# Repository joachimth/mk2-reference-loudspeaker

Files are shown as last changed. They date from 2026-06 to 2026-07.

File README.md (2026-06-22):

# Mk2 Reference Loudspeaker

A DIY active 3-way reference loudspeaker project, inspired by Genelec 8361, Dutch & Dutch 8C, and Revel Salon2.

## Current Design - v6b

| Parameter | Value |
|---|---|
| Woofers | 2 × GRS 8SW-4HE-8 (push-push, side-mounted) |
| Midrange | ScanSpeak 15W/4434G00 |
| Tweeter | ScanSpeak H2606/920000 in WG212 waveguide |
| Cabinet | 300 × 370 × 1080 mm, 22 mm birch plywood |
| Front edges | R50 vertical roundovers |
| Bass volume | ~69 L sealed |
| Mid chamber | ~5.7 L sealed |
| Bass/mid xover | 150 Hz LR4 |
| Mid/tweeter xover | 1250 Hz LR4 |
| Mid/tweeter c-c | 140 mm |
| Bass alignment | Fc ~34.5 Hz, Qtc ~0.62 |
| System type | Active, DSP-controlled |

## Project Status




Design candidate **v6b** is selected. CAD models and simulations are complete.
Physical prototype not yet started.

**Current gate:** Print WG212 waveguide → measure H2606 distortion at 1250 Hz → confirm crossover frequency → build prototype.

See [`PROJECT_TODO.md`](PROJECT_TODO.md) for the full task list and dependency graph.

## Documentation

The full Design Bible lives in the `docs/` folder:

| Chapter | File |
|---|---|
| Master index | [docs/00_design_bible.md](docs/00_design_bible.md) |
| 1. Project goals | [docs/01_project_goals.md](docs/01_project_goals.md) |
| 2. Theory | [docs/02_theory.md](docs/02_theory.md) |
| 3. Woofer selection | [docs/03_woofer_selection.md](docs/03_woofer_selection.md) |
| 4. Midrange selection | [docs/04_midrange_selection.md](docs/04_midrange_selection.md) |
| 5. Tweeter selection | [docs/05_tweeter_selection.md](docs/05_tweeter_selection.md) |
| 6. Waveguide development | [docs/06_waveguide_development.md](docs/06_waveguide_development.md) |
| 7. Cabinet development | [docs/07_cabinet_development.md](docs/07_cabinet_development.md) |
| 8. Push-push bass | [docs/08_push_push_bass.md](docs/08_push_push_bass.md) |
| 9. Volume calculations | [docs/09_volume_calculations.md](docs/09_volume_calculations.md) |
| 10. Bracing | [docs/10_bracing.md](docs/10_bracing.md) |
| 11. Crossovers | [docs/11_crossovers.md](docs/11_crossovers.md) |
| 12. Directivity | [docs/12_directivity.md](docs/12_directivity.md) |
| 13. Spinorama | [docs/13_spinorama.md](docs/13_spinorama.md) |
| 14. DSP | [docs/14_dsp.md](docs/14_dsp.md) |
| 15. Measurements | [docs/15_measurements.md](docs/15_measurements.md) |
| 16. Build guide | [docs/16_build_guide.md](docs/16_build_guide.md) |
| 17. Future versions | [docs/17_future_versions.md](docs/17_future_versions.md) |

## Reference Files

- [DESIGN_REQUIREMENTS.md](DESIGN_REQUIREMENTS.md) - Acoustic and mechanical targets
- [DESIGN_DECISIONS.md](DESIGN_DECISIONS.md) - Rationale for all key decisions
- [PARTS.md](PARTS.md) - Driver and materials list
- [SIMULATIONS.md](SIMULATIONS.md) - Simulation work and assumptions
- [MEASUREMENTS.md](MEASUREMENTS.md) - Measurement plan
- [BUILD_LOG.md](BUILD_LOG.md) - Physical build log
- [ROADMAP.md](ROADMAP.md) - Version history and future plans
- [CHANGELOG.md](CHANGELOG.md) - Design change log
- [REFERENCES.md](REFERENCES.md) - Books, papers, tools
- [TODO.md](TODO.md) - Outstanding tasks
- [REVIEW.md](REVIEW.md) - External technical review of the docs/simulations (flags physics-doc errors and revisits the 1250 Hz / 140 mm targets)
- [simulations/](simulations/) - Version-controlled simulation scripts + generated plots (bass alignment / max-SPL, vertical lobing)
- [cad/](cad/) - Parametric CAD (OpenSCAD OS waveguide for the H2606)
- [assets/](assets/) - Drawings, response plot, DSP table, and the SB23 study's design bible (reference material; see [assets/README.md](assets/README.md) — note the SB23 material diverges from the v6b spec)

## License

MIT

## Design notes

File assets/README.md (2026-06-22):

# Assets

Drawings, plots, and data files for the Mk2 Reference Loudspeaker.

These were imported from an external design session. They are kept here as
**reference material**. Treat the numbers in them as simplified, physics-based
**estimates / sketches — not measured data** and not the authoritative spec.

## ⚠️ These files describe an SB23-based study, not the current v6b spec

The current reference candidate (**v6b**) uses **GRS 8SW-4HE-8** woofers (see
`../DESIGN_DECISIONS.md` DD-004, and the v6b table in `../README.md`). The
drawings and DSP table below depict an **alternative / earlier SB23 line** and
disagree with v6b on several values. They are recorded for reference only; the
v6b spec in the rest of the repo is unchanged.

| Parameter | Current v6b (repo) | These assets |
|---|---|---|
| Woofer | GRS 8SW-4HE-8 | SB23 (SB23NRXS45-8) |
| Cabinet height | 1080 mm | 1050 mm |
| Bass volume | ~69 L sealed | ~50 L (`mk2_kabinet_tegning`) / ~64 L (`mk2_cab_ark1_ydre`, `..._snit_lodret`) |
| Mid/tweeter c-c | 140 mm | 157 mm (`mk2_kabinet_tegning`) / 160 mm (`mk2_cab_ark1_ydre`) |
| Bass/mid xover | 150 Hz LR4 | 180 Hz LR4 |
| Mid/tweeter xover | 1250 Hz LR4 | 1600 Hz LR4 |
| Waveguide / mid / tweeter | WG212 / 15W/4434G00 / H2606/920000 | same |

Note the assets are also **internally inconsistent** (c-c 157 vs 160 mm; bass
~50 vs ~64 L), so they are a set of in-progress sketches rather than one
finalized design.

## File index

This folder holds the **SB23 study** (the alternative direction) — its write-up,
drawings, data, and plots. Duplicates that also belonged in the type-based
folders have been removed: the review is at [../REVIEW.md](../REVIEW.md), the
runnable scripts + their plots are in [../simulations/](../simulations/), and the
waveguide model is in [../cad/mk2_waveguide_os.scad](../cad/mk2_waveguide_os.scad).

### Write-up + data

| File | What it is |
|---|---|
| [mk2_design_bible_sb23.md](mk2_design_bible_sb23.md) | **The SB23 study's full design write-up** (Danish): OS waveguide, ~1600 Hz LR4, c-c ~157–160 mm, 2 × SB23 sealed ~64 L (Qtc ≈ 0.75 / Fc ≈ 54 Hz). Textual companion to the drawings. Alternative direction, **not** the repo's v6b spec. |
| [mk2_parametre.csv](mk2_parametre.csv) | Parameter list for the SB23 study (cabinet, alignment, waveguide, crossovers). Columns: `Parameter` (name, Danish), `Værdi` (value with unit inline). |
| [mk2_stykliste.csv](mk2_stykliste.csv) | Cut list / bill of materials for the SB23 cabinet (panel sizes, bracing, magnet coupling rod). Columns: `Del` (part name), `Antal` (qty), `Mål (mm)` (dimensions), `Materiale` (material), `Bemærkning` (notes). |
| [mk2_dsp.csv](mk2_dsp.csv) | DSP filter plan per driver (HP/LP, Linkwitz Transform, delay, rest-EQ). Columns: `Vej` (signal path / driver), `Filter` (filter type and name), `Frekvens` (frequency or parameter), `Type` (filter topology: LR4, LT, PEQ, delay), `Formål` (purpose / rationale). |

### Drawings

| File | What it is |
|---|---|
| [mk2_kabinet_tegning.png](mk2_kabinet_tegning.png) | Cabinet dimensions and driver placement (labelled WG 212 mm, c-c 157 mm). |
| [mk2_cab_ark1_ydre.png](mk2_cab_ark1_ydre.png) | Sheet 1 — external dimensions (front / side / top), 300 × 370 × 1050 mm. |
| [mk2_cab_ark2_snit_lodret.png](mk2_cab_ark2_snit_lodret.png) | Sheet 2 — vertical section A-A (chambers + bracing, 22 mm walls). |
| [mk2_cab_ark3_snit_vandret.png](mk2_cab_ark3_snit_vandret.png) | Sheet 3 — horizontal section (push-push side woofers, internal width). |
| [mk2_cab_ark4_baffel.png](mk2_cab_ark4_baffel.png) | Sheet 4 — baffle layout (WG + mid cutouts, recesses). |
| [mk2_kabinet_tegninger.pdf](mk2_kabinet_tegninger.pdf) | Combined cabinet drawings (PDF). |
| [mk2_waveguide_profil.png](mk2_waveguide_profil.png) | Rendered OS waveguide profile (companion to `../cad/mk2_waveguide_os.scad`). |

### Plots (estimates, not measured)

| File | What it is |
|---|---|
| [mk2_estimeret_respons.png](mk2_estimeret_respons.png) | Estimated spinorama-style response: on-axis target, estimated in-room, sound power, directivity index. |
| [mk2_di_handoff.png](mk2_di_handoff.png) | Directivity-index hand-off across the mid/tweeter crossover. |
| [mk2_vertikal_lobing.png](mk2_vertikal_lobing.png) | Vertical lobing estimate for the SB23 study's c-c / crossover. |

The design bible's inline image and file references (`mk2_waveguide_profil.png`,
`mk2_kabinet_tegning.png`, `mk2_parametre.csv`, `mk2_dsp.csv`) all resolve within
this folder.

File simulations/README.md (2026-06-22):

# Simulations

Version-controlled, assumption-headed simulation scripts for the Mk2 Reference
Loudspeaker. This starts closing the "recreate simulations as version-controlled
scripts" task in [../SIMULATIONS.md](../SIMULATIONS.md).

**All outputs are simplified physics estimates, not measured data.** Every script
states its assumptions in a docstring. Final crossover/DSP decisions must come
from real measurements of the finished cabinet (see [../MEASUREMENTS.md](../MEASUREMENTS.md)).

## Scripts

| Script | What it computes | Output |
|---|---|---|
| `bass_alignment_maxspl.py` | Sealed alignment table (2 × GRS 8SW-4HE) + excursion-limited max-SPL ceiling (GRS vs SB23 reference) + sealed response with a Linkwitz-Transform target. | `plots/bass_alignment_maxspl.png` |
| `bass_volume_compare.py` | Sealed alignment (Qtc / Fc / F3) and group delay for 64–72 L net, highlighting the 69 L target — shows the alignment is robust to box-volume tolerance. | `plots/bass_volume_compare.png` |
| `vertical_lobing.py` | First vertical interference-null angle vs frequency for c-c and crossover options. | `plots/vertical_lobing.png` |
| `directivity_estimate.py` | Estimated directivity index (DI) of the 15W and the WG212 tweeter across the crossover — quantifies the DI step vs crossover frequency (DD-010 / REVIEW §C2). | `plots/directivity_estimate.png` |
| `waveguide_profile.py` | WG212 mouth-to-baffle termination cross-section — shows the sharp-lip diffraction problem and the flush / blended fixes. | `plots/waveguide_termination.png` |
| `crossover_simulation.py` | LR4 filters at 150 Hz + 1250 Hz: per-section amplitude and phase, coherent sum, zoomed panels around each crossover region. | `plots/crossover_simulation.png`, `csv/crossover_simulation.csv` |
| `system_response.py` | Full-bandwidth on-axis estimate 20 Hz–20 kHz: sealed woofer + LR4 LP@150, piston mid + BP@150/1250, tweeter roll-in + LR4 HP@1250 (placeholder — replace with real H2606-in-WG212 FR). | `plots/system_response.png`, `csv/system_response.csv` |
| `polar_response.py` | 2D polar map (freq × angle), spinorama curves (on-axis, listening window, early reflections, sound power, DI, PIR), and horizontal polar cuts at 7 key frequencies. | `plots/polar_response.png`, `csv/spinorama.csv`, `csv/polar_horizontal.csv` |
| `vertical_polar_map.py` | Vertical 2D heat-map vs frequency + comparison of four crossover options (1250/1350/1450/1600 Hz) + null-depth bar chart. Key input to the WG212 distortion-test decision. | `plots/vertical_polar_map.png`, `csv/vertical_polar_map.csv` |
| `design_versions_comparison.py` | Tabulates v1–v6b design parameters for reference. | `design_versions.md`, `csv/design_versions.csv` |
| `baffle_step.py` | Baffle-step diffraction model for the 300 mm wide cabinet: SPL correction curve, low-frequency level loss, and the full on-axis response before/after step correction. | `plots/baffle_step.png`, `csv/baffle_step.csv` |

The GRS alignment script reproduces the repo's stated **Qtc ≈ 0.62 / Fc ≈ 34.5 Hz
in ~69 L** (verified in [../REVIEW.md](../REVIEW.md) §A). The lobing script backs
up [../REVIEW.md](../REVIEW.md) §C2: even c-c 160 mm crossed at 1600 Hz keeps the
first vertical null near 42° — far outside the listening window.

## Running

```
pip install "numpy>=1.26" "matplotlib>=3.8"
python3 simulations/bass_alignment_maxspl.py
python3 simulations/bass_volume_compare.py
python3 simulations/vertical_lobing.py
python3 simulations/directivity_estimate.py
python3 simulations/waveguide_profile.py
python3 simulations/crossover_simulation.py
python3 simulations/system_response.py
python3 simulations/polar_response.py
python3 simulations/vertical_polar_map.py
python3 simulations/design_versions_comparison.py
python3 simulations/baffle_step.py
```

The directivity script implements the Bessel `J1` via a polynomial
approximation, so no SciPy is required.

Plots are written to `simulations/plots/`.

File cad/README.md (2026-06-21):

# CAD

Parametric CAD models for the Mk2 Reference Loudspeaker.

## `mk2_waveguide_os.scad`

A fully parametric **OpenSCAD** model of the tweeter waveguide for the
ScanSpeak **H2606/920000** — an oblate-spheroid (OS) constant-directivity bore
with a tangent rolled mouth that ends flush with the baffle.

- Mouth ≈ **211.7 × 121.0 mm**, total depth **75 mm** (the WG212 family).
- Asymmetric coverage ≈ **100° horizontal / 64° vertical**.
- Horizontal pattern control down to ≈ **1620 Hz**, i.e. designed to support a
  clean LR4 crossover to the 15W/4434G00 **near the waveguide's control limit**
  rather than well below it (this relates to the crossover discussion in
  [../REVIEW.md](../REVIEW.md) §C2 — the repo's current target is 1250 Hz LR4).

### Critical tunables (verify before printing)

- `throat_d` (28 mm placeholder) **must be matched to the real H2606 dome /
  faceplate exit** — this sets whether you get a throat resonance. Print throat
  test pieces against the physical tweeter first.
- The mouth roundover must blend smoothly into the cabinet's baffle roundover;
  a step there re-introduces diffraction.
- **Mouth-to-baffle termination:** the flange now sits *behind* the flush mouth
  plane so the bore meets the baffle with no forward lip (an earlier version left
  a sharp 90° edge there — a diffraction source). `Lr` controls the mouth
  roundover; increase it for an even gentler baffle blend at the cost of depth.
  See [`../simulations/waveguide_profile.py`](../simulations/waveguide_profile.py)
  and `plots/waveguide_termination.png`.

### Building

Open in OpenSCAD, render with F6, export STL. `$fn` is high for export — drop to
64 while iterating. The model echoes the computed mouth size and depth on render.

A rendered profile of this waveguide is in
[../assets/mk2_waveguide_profil.png](../assets/mk2_waveguide_profil.png).

These are **design-direction geometry, not validated by measurement.** Mouth
size, throat and coverage must be confirmed against H2606-in-waveguide
measurements.

## `cabinet.scad`

A fully parametric **OpenSCAD** model of the v6b enclosure — the first cabinet
geometry in the repo.

- External **300 × 370 × 1080 mm**, 22 mm walls, **R50** front vertical
  roundovers (rear edges square).
- **Side-mounted push-push** woofer cut-outs, opposed at the same height
  (~520 mm), with the rigid coupling block between the magnets (see
  [Chapter 8](../docs/08_push_push_bass.md)).
- Front baffle cut-outs for the **WG212** (elliptical mouth + rounded flange
  recess, matched to `mk2_waveguide_os.scad`) and the **15W/4434G00** midrange at
  **~150 mm c-c**.
- `show_internals = true` renders a cut-away with the sealed mid chamber, a
  window brace at the woofer line and the bass/mid shelf brace.
- `show_waveguide = true` drops the WG212 model into the baffle (it `use`s
  `mk2_waveguide_os.scad`, so keep both files together). The waveguide is seated
  with its mouth poking `wg_through` (default 0.3 mm) **through** the baffle. Its
  seating depth is read from the waveguide via `wg_front_z()`, so it can't drift
  out of sync. (If it only sits flush near ~84.5 mm, your waveguide file is the
  old flange-forward version — the flush model seats at `D_tot` = 75 mm.)

### Assembly and the coincident-face rule

OpenSCAD cannot show a hole or a join where two surfaces sit at exactly the same
plane — the boolean becomes non-manifold and renders as a flickering "smear"
instead of a clean opening. So every cutter here overshoots the panel it pierces
by `eps` (0.1 mm), and when the waveguide is seated its flush mouth is pushed
`wg_through` mm proud of the baffle so the two solids genuinely overlap. Keep
`wg_through > 0` (≥ 0.01 mm); set it to ~0.3 mm for a reliable preview. The
overlap is cosmetic for visualisation — it is not a real interference fit.

### Critical tunables (verify before cutting)

- `woofer_z`, `tw_z`, `mid_z` (driver heights) and `cc` set the baffle layout;
  confirm against the real flanges and the bracing layout
  ([Chapter 10](../docs/10_bracing.md)).
- The mid-chamber box here is **representational** — its net volume must be
  confirmed at **~5.7 L** from the solid model
  ([Chapter 9](../docs/09_volume_calculations.md)) before it is trusted.
- Cut-out diameters (woofer 185, mid 124 mm) are estimates pending datasheet
  templates.

This is a **dimension-check / visualisation model, not a cut list.**

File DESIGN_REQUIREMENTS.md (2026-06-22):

# Design Requirements

## Acoustic Targets

- Approx. ±1.5 dB on-axis response
- Smooth directivity index
- Controlled horizontal radiation
- Useful ±15° vertical listening window
- Smooth predicted in-room response

## Driver Layout

- 2 × GRS 8SW-4HE-8
- ScanSpeak 15W/4434G00
- ScanSpeak H2606/920000
- WG212

## Cabinet

- 300 × 370 × 1080 mm
- 22 mm birch plywood
- R50 front roundovers

## Alignment

- 69 L sealed bass chamber
- Qtc ≈ 0.62
- Fc ≈ 34.5 Hz

## Crossovers

- 150 Hz LR4
- 1250 Hz LR4

## Geometry

- Target c-c spacing: **140 mm nominal** (WG212 mouth radius ~55 mm + 15W flange radius ~62 mm + gap ~23 mm).
  In practice ~150–155 mm is expected once the WG212 is printed and the 15W flange is physically measured.
  Confirm from physical parts before locking the cabinet model.

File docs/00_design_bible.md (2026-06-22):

# Mk2 Reference Loudspeaker - Design Bible

## About this document

This is the master documentation index for the Mk2 Reference Loudspeaker project. Each chapter covers one aspect of the design process, from initial goals through theory, driver selection, cabinet development, simulation, measurement, and build.

The design bible is a living document. It will be updated as the project progresses from simulation to physical prototype to final tuning.

---

## Current design summary - v6b

- Active 3-way loudspeaker with DSP crossovers
- 2 × GRS 8SW-4HE-8 woofers (side-mounted push-push)
- ScanSpeak 15W/4434G00 midrange
- ScanSpeak H2606/920000 tweeter in WG212 waveguide
- Cabinet: 300 × 370 × 1080 mm, 22 mm birch plywood, R50 front roundovers
- Bass: ~69 L sealed, Fc ~34.5 Hz, Qtc ~0.62
- Crossovers: 150 Hz LR4 (bass/mid), 1250 Hz LR4 (mid/tweeter)
- Mid/tweeter c-c: 140 mm

---

## Chapters

| # | Title | File | Status |
|---|---|---|---|
| 1 | Project goals and philosophy | [01_project_goals.md](01_project_goals.md) | Complete |
| 2 | Loudspeaker theory | [02_theory.md](02_theory.md) | Complete |
| 3 | Woofer investigations | [03_woofer_selection.md](03_woofer_selection.md) | Complete |
| 4 | Midrange investigations | [04_midrange_selection.md](04_midrange_selection.md) | Complete |
| 5 | Tweeter investigations | [05_tweeter_selection.md](05_tweeter_selection.md) | Complete |
| 6 | Waveguide development | [06_waveguide_development.md](06_waveguide_development.md) | Complete (CAD done; print + measure pending) |
| 7 | Cabinet development | [07_cabinet_development.md](07_cabinet_development.md) | Complete (CAD done; build pending) |
| 8 | Push-push bass | [08_push_push_bass.md](08_push_push_bass.md) | Complete |
| 9 | Volume calculations | [09_volume_calculations.md](09_volume_calculations.md) | Complete |
| 10 | Bracing | [10_bracing.md](10_bracing.md) | Complete (representational CAD; detail pending build) |
| 11 | Crossovers | [11_crossovers.md](11_crossovers.md) | Complete (frequency pending distortion measurement) |
| 12 | Directivity | [12_directivity.md](12_directivity.md) | Complete |
| 13 | Spinorama | [13_spinorama.md](13_spinorama.md) | Complete (estimated; true spinorama pending build) |
| 14 | DSP | [14_dsp.md](14_dsp.md) | Complete (platform not yet selected) |
| 15 | Measurements | [15_measurements.md](15_measurements.md) | Plan written; execution pending prototype |
| 16 | Build guide | [16_build_guide.md](16_build_guide.md) | Plan written; execution not started |
| 17 | Future versions | [17_future_versions.md](17_future_versions.md) | Complete |

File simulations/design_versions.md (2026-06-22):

# Mk2 Reference Loudspeaker — Design Versions Comparison

Auto-generated by `simulations/design_versions_comparison.py`. Numbers from ROADMAP.md and design decision log.

## Physical

| Version | Status | Cabinet (W×H×D mm) | Wall | R-front | Bass vol (L) | Mid vol (L) |
| --- | --- | --- | --- | --- | --- | --- |
| **v1** | concept | 300×370×1080 | 22 mm | R50 | 69.0 | 5.7 |
| **v2** | concept | 300×370×1080 | 22 mm | R50 | 69.0 | 5.7 |
| **v3** | investigation | 300×370×1080 | 22 mm | R50 | 69.0 | 5.7 |
| **v4** | exploration | 280×370×1080 | 22 mm | R40 | 65.0 | 5.7 |
| **v5** | candidate | 300×370×1080 | 22 mm | R50 | 68.0 | 5.7 |
| **v6** | candidate | 300×370×1080 | 22 mm | R50 | 69.0 | 5.7 |
| **v6b** | CURRENT REFERENCE | 300×370×1080 | 22 mm | R50 | 69.0 | 5.7 |

## Drivers & crossovers

| Version | Woofer | Qty | Midrange | Tweeter | Waveguide | Xover bass | Xover mid/tw | c-c (mm) |
| --- | --- | --- | --- | --- | --- | --- | --- | --- |
| **v1** | SB23NRXS45-8 | 2 | ScanSpeak 15W/4434G00 | ScanSpeak H2606/920000 | WG212 | 150 Hz LR4 | 1600 Hz LR4 | 150 |
| **v2** | SB23NRXS45-8 | 2 | ScanSpeak 15W/4434G00 | ScanSpeak H2606/920000 | WG212 | 150 Hz LR4 | 1500 Hz LR4 | 150 |
| **v3** | GRS 8SW-4HE-8 | 2 | ScanSpeak 15W/4434G00 | ScanSpeak H2606/920000 | WG212 | 150 Hz LR4 | 1500 Hz LR4 | 150 |
| **v4** | GRS 8SW-4HE-8 | 2 | ScanSpeak 15W/4434G00 | ScanSpeak H2606/920000 | WG212 | 150 Hz LR4 | 1400 Hz LR4 | 150 |
| **v5** | GRS 8SW-4HE-8 | 2 | ScanSpeak 15W/4434G00 | ScanSpeak H2606/920000 | WG212 | 150 Hz LR4 | 1300 Hz LR4 | 150 |
| **v6** | GRS 8SW-4HE-8 | 2 | ScanSpeak 15W/4434G00 | ScanSpeak H2606/920000 | WG212 | 150 Hz LR4 | 1250 Hz LR4 | 140 |
| **v6b** | GRS 8SW-4HE-8 | 2 | ScanSpeak 15W/4434G00 | ScanSpeak H2606/920000 | WG212 | 150 Hz LR4 | 1250 Hz LR4 | 150 |

## Bass alignment (2× driver, sealed)

| Version | Qtc | Fc (Hz) | Notes |
| --- | --- | --- | --- |
| **v1** | 0.56 | 31.9 | Initial concept with SB23 woofer; directivity investigation started |
| **v2** | 0.56 | 31.9 | Cabinet geometry defined; side-mounted push-push woofer layout introduced |
| **v3** | 0.62 | 34.5 | GRS 8SW-4HE-8 introduced as woofer candidate; strong sealed alignment fit |
| **v4** | 0.65 | 35.8 | Narrower 280 mm front explored; R40 roundover useful but mechanically constrained |
| **v5** | 0.63 | 34.8 | 300 mm / R50 selected; 68 L bass volume |
| **v6** | 0.62 | 34.5 | Directivity optimization; c-c 140 mm target; WG212–WG240 compared |
| **v6b** | 0.62 | 34.5 | c-c 150 mm practical minimum (15W frame). WG212 CAD + cabinet CAD complete. 1250 Hz target subject to WG212 distortion test (tweeter Fs 1030 Hz). Fallback: 1350-1450 Hz if 1250 Hz fails. |

---

*Measurements will be added to this table once the prototype is built. Until then all values are design targets, not validated data.*

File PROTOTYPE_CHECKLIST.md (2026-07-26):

# Prototype Checklist — Next Gate

## What you need to do before building the cabinet

3 steps. That's it. Do them in order.

---

## Step 1 — Print the SB26STAC waveguide

| Property | Current value | Status |
|---|---|---|
| STL source | `cad/exports/waveguide.stl` (or local: `openscad -o waveguide.stl cad/waveguide.scad`) | ✅ Ready |
| Material | PETG recommended | |
| Orientation | Print flat — flange down, throat up | |
| Post-print | Slow cool to avoid warping | |

**Known dimensions (do NOT change without measurement):**

| Dimension | Value | Source | Caliper verify? |
|---|---|---|---|
| Throat diameter | ø32 mm (dome + surround, caliper-verified) | SB26STAC physical measurement Jul 25 | [x] |
| BCD (screw circle) | ø88.5 mm | Caliper-verified Jul 25 | [x] |
| Mouth size (H×V) | from SCAD echo | SCAD | |
| Total depth | from SCAD | SCAD | |
| Flange (W×H) | from SCAD | SCAD | |

### SB26STAC tweeter mounting — verify before bonding

| Dimension | Expected | Check with caliper | Pass? |
|---|---|---|---|
| Faceplate OD | 100.0 mm (measured 99.84) | [x] Caliper-verified Jul 25 | [x] |
| Screw hole BCD | ø88.5 mm | [x] Caliper-verified Jul 25 | [x] |
| Throat through-hole | ø32 mm — dome + surround fits bore | [x] Caliper-verified Jul 25 | [x] |
| Recess diameter | ø43 mm (outer edge) | [x] Caliper-verified Jul 25 | [x] |

> **Note:** SB26STAC-C000-4 GrabCAD STEP file is a FAKE (similar but wrong SB Acoustics tweeter). All dimensions have been caliper-verified from the physical unit (Jul 25, 2026) and updated in waveguide.scad. See `docs/SB26STAC_measurement_sheet.html` for full verification sheet.

### Baffle mounting holes — verify before drilling

| Dimension | Expected | Check | Pass? |
|---|---|---|---|
| BCD x | from SCAD | ☐ | ☐ |
| BCD y | from SCAD | ☐ | ☐ |
| Screw diameter | from datasheet | ☐ | ☐ |

---

## Step 2 — Confirm driver cutout diameters from real parts

**These are still estimates — confirm from physical driver before cutting baffle.**

| Driver | Cutout diameter | Status | Verify from |
|---|---|---|---|
| GRS 12SW-4HE (woofer) | ø284 mm | ⚠️ Estimate from datasheet (embedded fonts block text extraction) | ☐ Caliper on physical unit |
| ScanSpeak 18W/4424G00 (mid) | Ø144.3 mm (Ø179.2 faceplate) | From official datasheet + cad/midrange.scad | ☐ Verify anyway |
| SB26STAC waveguide mouth (baffle aperture) | from SCAD | ✅ Auto-propagating from waveguide.scad | ☐ Measure printed part |

---

## Step 3 — Distortion test: SB26STAC at 1100 Hz

This is **the design gate**. If the SB26STAC can't do 1100 Hz with low distortion, the crossover frequency shifts up.

**Setup:**
- Mount SB26STAC in the printed waveguide
- Use a solid baffle (cardboard or ply test panel) with the waveguide aperture cut
- Measure nearfield with measurement mic (UMIK-1 or similar)
- Signal: 2.83 V sine sweep

**What to check:**

| Frequency | Acceptable THD | Action |
|---|---|---|
| 1100 Hz | < 2% | ✅ Crossover target confirmed at 1100 Hz LR4 |
| 1300 Hz | < 2% | Shift crossover up; update fc_mid in all simulation scripts |
| 1500 Hz | < 2% | Same as above |
| 1800 Hz | < 1% | Safe upper limit |

**Why 1100 Hz specifically:** SB26STAC Fs = 750 Hz. Crossover at 1100 Hz is 350 Hz above resonance. The SB26STAC has 0.6 mm Xmax, giving +8.1 dB excursion headroom at crossover. This is a comfortable margin. If distortion is too high, raise to 1300-1500 Hz.

**Recording (note these):**
- Measured THD at 1100 Hz: _____ %
- Measured THD at 1300 Hz: _____ %
- Measured THD at 1500 Hz: _____ %
- Any audible anomalies: ___________

**After the test:**
- [ ] If 1100 Hz passes: confirm fc = 1100 Hz, update DESIGN_DECISIONS.md
- [ ] If 1100 Hz fails: update fc_mid in all simulation scripts + MiniDSP XML config
- [ ] Measure real c-c from printed waveguide flange to 18W frame — expected 165 mm (DD-016)
- [ ] Update cc_mid_tw_mm in design_versions_comparison.py + DESIGN_DECISIONS.md DD-011

---

## Then you can: start the cabinet build

The cabinet CAD is fully parametric. Once these 3 steps are done:

1. Order drivers (2× GRS, 1× 18W/4424G00, 1× SB26STAC-C000-4 per speaker)
2. DSP: MiniDSP 4×10 HD — import `mk3-v9-200-1100-bw4-lr4.xml`
3. Follow `docs/16_build_guide.md` — 10 phases, build log in `BUILD_LOG.md`
4. 22 mm birch plywood, ~4 sheets per pair

---

## CAD current state (as of July 26, 2026)

| Model | File | Notes |
|---|---|---|
| `cad/waveguide.scad` | primary | SB26STAC waveguide: BCD 88.5 mm, throat 32 mm (caliper-verified), recess 43 mm. STL rendered, manifold. Waveguide mockup printed and impedance-verified. |
| `cad/cabinet.scad` | shared | Fully dynamic from waveguide.scad; W300 D420 H1180, 65 L bass chamber, 5.7 L mid chamber. Updated for GRS 12SW-4HE (284 mm cutout). |

**Don't cut panels from SCAD outputs until parts are physically verified.**

---

## Quick reference — key dimensions

| Item | Value |
|---|---|
| Cabinet W×D×H | 300 × 420 × 1180 mm (22 mm birch ply, locked Jul 8) |
| Woofer (each) | GRS 12SW-4HE, 4 Ω, 12" high excursion, side-mounted push-push |
| Woofer centers | ~520 mm from bottom, opposed at same height |
| Midrange | ScanSpeak 18W/4424G00, 4 Ω |
| Tweeter | SB Acoustics SB26STAC-C000-4 in custom waveguide |
| Mid/tweeter c-c | 165 mm (physical minimum with 18W faceplate — verify from real parts, DD-016) |
| Bass crossover | 200 Hz BW4 |
| Mid/tweeter crossover | 1100 Hz LR4 (unconfirmed — Step 3) |
| FR roundovers | R19 on cabinet front vertical edges |
| DSP | MiniDSP 4×10 HD |

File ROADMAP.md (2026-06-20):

# Mk2 Reference Loudspeaker Roadmap

## v1 - Initial concept

- Active 3-way reference loudspeaker concept
- Initial cabinet and driver layout
- SB23 woofer-based starting point

## v2 - Cabinet development

- 300 mm wide cabinet concept
- Side-mounted push-push woofers
- Dedicated midrange chamber
- H2606 in waveguide

## v3 - GRS woofer investigation

- Introduced GRS 8SW-4HE-8 as alternative woofer
- Evaluated sealed-box alignments
- Found strong fit for 64-70 L sealed bass volume

## v4 - 280 mm cabinet exploration

- Explored narrower 280 mm front baffle
- Compared edge roundovers
- Found R40 useful but mechanically constrained

## v5 - 300 mm / R50 cabinet

- Selected 300 mm front width
- Selected R50 vertical front roundovers
- Targeted 64-70 L sealed bass volume
- Refined woofer placement and mid chamber

## v6 - Directivity optimization

- Compared WG212, WG220, WG230 and WG240 concepts
- Compared 1300-1600 Hz mid/tweeter crossover region
- Found c-c spacing more important than larger waveguide mouth

## v6b - Current reference candidate

Current main design:

- 300 x 370 x 1080 mm cabinet
- 22 mm birch plywood
- R50 front roundovers
- 2 x GRS 8SW-4HE-8 side-mounted push-push woofers
- ScanSpeak 15W/4434G00 midrange
- ScanSpeak H2606/920000 tweeter
- WG212 waveguide
- Approx. 69 L sealed bass volume
- Approx. 5.7 L sealed mid chamber
- 150 Hz LR4 bass/mid crossover
- 1250 Hz LR4 mid/tweeter crossover
- Target 140 mm mid/tweeter c-c spacing

## v7 - Measurement-validated design

- Build first physical prototype
- Measure all drivers in cabinet
- Import measurements into VituixCAD
- Validate or revise 1250 Hz crossover
- Validate vertical listening window

## v8 - CAD/package refinement

- Final cabinet drawings
- Final waveguide model
- STEP/STL export
- CNC/fræse-ready drawings

## v9 - DSP implementation

- Initial MiniDSP/FusionAmp presets
- Delay optimization
- EQ and target curves
- House curve versions

## v10 - Advanced variants

- FIR filters
- Alternative tweeters
- Alternative midranges
- Cardioid/controlled bass experiments

## v11 - Integrated active version

- Integrated amplifier module
- Internal DSP
- Full wiring plan
- Finalized build guide

---

## Alternative variant - SB23 line (parallel study)

A separate, self-contained study explores a **SB23-based** version of the Mk2
rather than the GRS bass of the main v6b line. It shares the H2606 tweeter, 15W
midrange and waveguide direction but differs on the bass and several cabinet
numbers:

- 2 × SB Acoustics SB23NRXS45-8 (push-push), sealed ~64 L, Qtc ≈ 0.75 / Fc ≈ 54 Hz
- OS (oblate-spheroid) waveguide, ~1600 Hz LR4 mid/tweeter, c-c ~157-160 mm
- Cabinet ~1050 mm tall, 180 Hz LR4 bass/mid

This is **not** the reference design — v6b (GRS) remains the main line. The full
write-up, drawings, parameters and parts list live in
[`assets/`](assets/) (see [`assets/mk2_design_bible_sb23.md`](assets/mk2_design_bible_sb23.md)
and [`assets/README.md`](assets/README.md)). Several of its directivity arguments
(higher crossover near the waveguide control limit, ~157-160 mm c-c) align with
the review caveats now recorded against DD-010 / DD-011.

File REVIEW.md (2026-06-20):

# Technical Review — Mk2 Reference Loudspeaker

External review of the repository documentation and the "simulations" (the numbers and
physics claims in the docs). Goal: flag anything incorrect, anything worth optimising,
and confirm which numbers hold up.

**Headline:** the core bass alignment is **correct** (reproduced independently below).
The design framing (sealed, active, push-push, spinorama-driven, "estimates not
measurements") is sound and honestly stated. The issues are a handful of **documentation
errors in the physics explanations** and **two design targets (1250 Hz crossover, 140 mm
c-c) that are questionable and probably not buildable as written**.

Severity: 🔴 fix (wrong), 🟠 revisit (questionable judgement), 🟡 minor/polish.

---

## A. Bass alignment — verified correct ✅

Independent recomputation, two GRS 8SW-4HE in a shared sealed box, standard N-driver
relation `Vas_total = N · Vas_single`, `Qtc = Qts·√(1 + Vas_total/Vb)`:

| Vb (net) | Qtc | Fc |
|---|---|---|
| 62 L | 0.64 | 35.4 Hz |
| 69 L | 0.62 | 34.5 Hz |
| 73 L | 0.62 | 34.0 Hz |

This matches the repo's stated **Qtc ≈ 0.62 / Fc ≈ 34.5 Hz** in ~69 L. Good low-Q sealed
alignment, ideal for DSP extension. No change needed to the *numbers*.

---

## B. Documentation errors to fix 🔴

### B1. `docs/09_volume_calculations.md` — the Vas explanation is wrong
The text says *"the effective system Vas is approximately equal to the individual driver
Vas."* That is incorrect, and if you actually used it you'd get the wrong answer:
`Vas=31.7, Vb=69 → Qtc 0.54 / Fc 30`, **not** the 0.62/34.5 you (correctly) report.

The correct statement, and the one that reproduces your own result:
> For N identical drivers sharing one sealed box, the system behaves like one driver with
> `Sd_total = N·Sd` and **`Vas_total = N · Vas_single`**. For two GRS: `Vas_total = 2 × 31.7 = 63.4 L`.
> `Qtc = Qts·√(1 + Vas_total/Vb) = 0.45·√(1 + 63.4/69) = 0.62`, `Fc = 24.9·√(…) = 34.5 Hz`.

Note `docs/03_woofer_selection.md` already states the correct `63.4 L` — so 09 currently
contradicts 03. Align 09 to 03.

### B2. `docs/03_woofer_selection.md` — inverted formula + spec mismatches
- The formula is printed inverted: *"Qtc = Qts × sqrt(1 + Vb/Vas per driver pair)"*.
  It should be `Qtc = Qts × sqrt(1 + Vas_total / Vb)`.
- Spec table lists **Xmax ~13 mm** and **Sd ~214 cm²**. The SoundImports datasheet for
  8SW-4HE gives **Xmax 10.8 mm** and **Sd 227 cm²** (Re 3.8 Ω, not 3.4). The 13 mm figure
  is likely an Xmech/peak number, not Xmax. Use the conservative datasheet Xmax (10.8 mm)
  for any SPL/excursion estimate, and verify all three against the official GRS sheet.

### B3. `docs/11_crossovers.md` — LR4 phase claim is wrong
The doc says *"both drivers are 180° out of phase at Fc, but this is corrected by time
delay."* That describes **LR2**, not LR4. For **LR4** the two acoustic outputs are
**in phase (0°)** at Fc, each at −6 dB, and they sum flat **without** polarity inversion.
What time-alignment (delay) corrects is the **physical acoustic-centre offset** between
drivers — not a 180° crossover phase. Suggested wording:
> LR4 outputs are in phase at the crossover frequency (each −6 dB) and sum flat with no
> polarity inversion. DSP delay is used to align the drivers' acoustic centres so the
> summation is correct off-axis as well as on-axis.

---

## C. Design targets to revisit 🟠

### C1. 140 mm c-c (DD-011) is probably not buildable as written
Geometric minimum c-c ≈ `(mid_frame/2) + (WG_flange_height/2)`. The 15W frame is Ø149,
so its half is 74.5 mm. A WG212 (mouth ~121 mm tall + a rolled mouth termination) needs a
flange roughly 140–150 mm tall → half ≈ 70–75 mm. That puts the **geometric minimum c-c
at ~145–160 mm**. 140 mm is only achievable with a deliberately compact / bottom-trimmed
("D-shaped") flange. Recommendation: treat **c-c ≈ 150–160 mm** as the realistic target,
set it from the actual WG flange + mid recess once the WG is in CAD, and don't over-commit
to 140 in the decision log.

Importantly, you don't *need* 140 for lobing — see C2.

### C2. 1250 Hz crossover (DD-010) — the rationale is only half-right
The repo says lowering the crossover "improves directivity matching." It improves
**lobing**, but it can **hurt constant directivity**, because a 212 mm-mouth waveguide only
controls its pattern down to ~1500–1700 Hz. Crossing at **1250 Hz** sits ~300–450 Hz
**below** where the WG controls, so in that octave the tweeter pattern is still broad (no
match benefit), and you ask the H2606 (Fs 1030 Hz) to work at only **1.2 × Fs** — aggressive
for an LR4 high-pass and a distortion/excursion risk.

Lobing does **not** force 1250 Hz. First vertical null angle `θ = asin(c / (2·d·fx))`:

| c-c | 1250 Hz | 1500 Hz | 1600 Hz |
|---|---|---|---|
| 140 mm | 79° | 55° | 50° |
| 160 mm | 59° | 46° | 42° |

Even at **c-c 160 mm and 1600 Hz** the first null is at **42°** — far outside the ±15–30°
window. So a buildable **c-c ≈ 160 mm crossed near the WG control limit (~1500 Hz)** is
clean for lobing *and* gives the WG something to actually do. Suggested target: **acoustic
LR4 ~1500 Hz, c-c ~155–160 mm**, final value set by measured H2606-in-WG distortion
(expect the usable range 1400–1700 Hz). (`simulations/vertical_lobing.py` reproduces the
table above.)

### C3. `docs/08_push_push_bass.md` — self-contradictory, and the stagger is excessive
The chapter says "centres aligned at the same height" and then "vertically stacked … lower
350 mm / upper 700 mm." A 350 mm vertical offset destroys most of the force-cancelling
couple (large rocking moment) — it is *not* a minor compromise.

It is also unnecessary. The GRS overall depth is ~117 mm; in a 256 mm internal width two
opposed magnets leave `256 − 2×117 = 22 mm` of **static** gap (the magnets are fixed to the
baskets/walls and don't move). So **same-height opposed push-push fits**, and a short rigid
**coupling block bonded across that 22 mm** is actually the ideal force-cancelling
arrangement. Recommendation: drop the 350/700 stagger; specify **same height, opposed, with
a coupling block**. Only stagger or widen the cabinet if you want more working clearance.

---

## D. Minor / polish 🟡

- **`docs/09`** driver-displacement deduction "~1.5 L for two woofers" is low for the deep
  GRS (117 mm, ~1.6 kg magnet) — budget ~2–3 L each (~5 L pair). It barely moves Qtc
  (still ~0.62), but fix the figure.
- **`docs/14` / DD-006** mid sensitivity is quoted ~88 dB; the 15W/4434G00 is ~89.7 dB.
  Tweeter pad will land around −5 to −7 dB; finalise from measurement (already noted).
- **Impedance labelling:** the SoundImports listing shows 4 Ω under the "-8" SKU
  (Re 3.8). Confirm whether your drivers are 4 Ω (series → 8 Ω, as the docs assume) or
  8 Ω before wiring.
- **Naming:** consider stating once, prominently, that all spinorama/DI curves are
  *simplified power-response estimates*, not CEA-2034 from measurement — the docs say it,
  but a one-line banner at the top of `13_spinorama.md` would prevent misreading.

---

## E. What's genuinely good (so it isn't lost in the edits)

- Sealed-alignment maths and the low-Q DSP rationale are correct.
- The "estimates, not measurements; finalise from REW/VituixCAD" discipline is exactly
  right and consistently repeated.
- The CEA-2034 / Toole–Olive framing in `02_theory.md` and `13_spinorama.md` is accurate.
- Cabinet width / roundover reasoning (300 mm + R50) is sound and well-justified.
- Documentation structure (numbered chapters + a decision log with DD-IDs) is excellent and
  easy to review.

---

## F. Suggested additions in this PR

To start closing the "recreate simulations as version-controlled scripts" TODO
(`SIMULATIONS.md`), this review ships two runnable, assumption-headed scripts:

- `simulations/bass_alignment_maxspl.py` — sealed alignment table + excursion-limited max
  SPL (GRS pair vs SB23 reference) + sealed response with a Linkwitz-Transform target.
  Writes `simulations/plots/bass_alignment_maxspl.png`.
- `simulations/vertical_lobing.py` — first vertical-null angle vs frequency for c-c and
  crossover options (backs up §C2). Writes `simulations/plots/vertical_lobing.png`.

Run: `python3 simulations/bass_alignment_maxspl.py` (needs numpy + matplotlib).

All figures are simplified physics estimates and must be validated against measurements of
the finished cabinet.

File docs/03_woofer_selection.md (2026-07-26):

# Chapter 3 - Woofer Investigations

> **UPDATE Jul 8, 2026:** Cabinet width locked at 300 mm (not 320 mm as stated
> below). Bass volume is ~65 L (not 75 L). DATS measurements (Jul 25) show
> Fs=23.3 Hz, Qts=0.46 after 10h break-in (datasheet: Fs=22, Qts=0.43).

---

## Requirements

The woofer system must:

- Cover the bass range from approximately 20-25 Hz to 200 Hz
- Be suitable for a sealed alignment with Qtc around 0.6-0.65
- Produce useful output below 30 Hz with DSP assistance
- Fit two drivers side-mounted in a 320 mm wide cabinet
- Have sufficient excursion for realistic SPL at low frequencies
- Have an acceptable cost/performance ratio for a DIY project

A 12-inch driver size was selected as the target, as it provides high excursion and large radiating surface area for deep bass output in a moderate sealed cabinet. (An earlier 8-inch target — GRS 8SW-4HE-8 — was used through v7 and is retained below as a historical comparison.)

---

## Investigated drivers

### SB Acoustics SB23 (initial concept, v1)

The SB23 family was the starting point in the earliest concept phase (v1). The SB23 is a well-regarded driver with good T/S parameters, but it was replaced as the project evolved and the bass volume requirements became clearer.

**Outcome:** Not selected. Used as the starting reference point only.

---

### GRS 8SW-4HE-8 (historical — v3 through v7, superseded by 12SW)

The GRS 8SW-4HE-8 was introduced in v3 and served as the woofer through v7. It has
been superseded by the GRS 12SW-4HE (see below) for the v8 bass upgrade. It is
retained here as a historical comparison.

**Key T/S parameters (manufacturer data):**

| Parameter | Value |
|---|---|
| Fs | ~24.9 Hz |
| Vas | ~31.7 L |
| Qts | ~0.45 |
| Re | ~3.8 Ω |
| Xmax | ~10.8 mm |
| Sd | ~227 cm² |

T/S values are from the SoundImports datasheet and must be verified against the
official GRS sheet before construction. Use the conservative datasheet **Xmax
~10.8 mm** for any excursion/SPL estimate; the ~13 mm figure quoted elsewhere is
likely an Xmech/peak number, not Xmax.

**Two drivers in series:**
- Total impedance: ~8 Ω nominal
- Combined Vas: approximately 2 × 31.7 L = 63.4 L equivalent (for one equivalent driver)
- Combined Sd: approximately 2 × 227 cm² = 454 cm²

**Sealed alignment — two drivers in 69 L net (historical, v7):**

Two identical drivers sharing one sealed box behave like a single equivalent
driver with `Sd_total = 2 × Sd` and `Vas_total = 2 × Vas_single = 63.4 L`. The
sealed alignment is then:

```
Qtc = Qts × sqrt(1 + Vas_total / Vb) = 0.45 × sqrt(1 + 63.4/69) ≈ 0.62
Fc  = Fs  × sqrt(1 + Vas_total / Vb) = 24.9 × sqrt(1 + 63.4/69) ≈ 34.5 Hz
```

So for two GRS 8SW-4HE-8 in a sealed cabinet (historical v7 simulation target):

- Net bass volume: ~69 L
- Fc: ~34.5 Hz
- Qtc: ~0.62

This is a low-Q sealed alignment that:
- Has a well-controlled rolloff
- Responds well to DSP bass extension (Linkwitz Transform or shelf boost)
- Produces low group delay compared with heavily tuned ported designs

**Strengths:**

- Low Fs suitable for deep bass in a moderate cabinet
- Good excursion for the price
- 4-ohm nominal impedance allows series wiring to 8 Ω (suitable for most amplifiers)
- Fits the cabinet geometry and mounting requirements

**Weaknesses / open items:**

- Verify exact cutout and frame dimensions before cabinet construction
- Verify push-push wiring phase: the rear-mounted woofer must be wired in reversed polarity to maintain acoustic push-push cancellation of cabinet reaction forces

### GRS 12SW-4HE (selected — v8)

The GRS 12SW-4HE is a 12-inch high-excursion woofer selected for the v8 bass
upgrade, replacing the 8SW. The push-push configuration and sealed alignment are
retained.

**Key T/S parameters (manufacturer data, Klippel-verified Xmax):**

| Parameter | Value |
|---|---|
| Fs | 22 Hz |
| Vas | 80.4 L |
| Qts | 0.43 |
| Sd | 504 cm² |
| Xmax | 12.5 mm (Klippel verified) |
| Bl | 16.2 Tm |
| Sensitivity | 84.5 dB |
| Power | 250 W |
| Impedance | 4 Ω |
| Cutout diameter | 284 mm |

**Two drivers in series:**
- Total impedance: ~8 Ω nominal
- Combined Vas: 2 × 80.4 = 160.8 L equivalent
- Combined Sd: 2 × 504 = 1008 cm²

**Sealed alignment — two drivers in ~75 L net (under divider plate):**

```
Qtc = Qts × sqrt(1 + Vas_total / Vb) = 0.43 × sqrt(1 + 160.8/75) ≈ 0.76
Fc  = Fs  × sqrt(1 + Vas_total / Vb) = 22.0 × sqrt(1 + 160.8/75) ≈ 39.0 Hz
```

So for two GRS 12SW-4HE in a sealed cabinet (v8 target):

- Net bass volume: ~75 L (under the divider plate)
- Sealed Fc: ~39 Hz, Qtc: ~0.76
- Linkwitz Transform target: Fc 39.0 → 28 Hz, Qtc 0.76 → 0.707

**Displacement and max SPL:**
- Peak displacement (2 drivers): 2 × Sd × Xmax = 2 × 504 cm² × 12.5 mm = 12.6 cm³
- vs 8SW pair: 2.0 cm³ — a 6.3× increase
- Max SPL @ 30 Hz: **+16 dB** over the previous 8SW design

**Strengths:**

- Very low Fs (22 Hz) — deep bass extension in a moderate sealed cabinet
- High excursion (12.5 mm Xmax, Klippel verified) for low-distortion SPL
- Large Sd (504 cm²) for efficient air displacement
- Good cost/performance ratio (~€75 per driver)
- Qts 0.43 works well with a Linkwitz Transform to a 0.707 target

**Weaknesses / open items:**

- Large frame (~332 mm overall) and 284 mm cutout — verify fit on 370 mm deep
  side panels
- Basket depth ~136 mm — opposed magnets have only ~4 mm clearance in the
  276 mm internal width (vs ~22 mm for the old 8SW). Coupling block must be sized
  accordingly.
- Lower sensitivity (84.5 dB) than the 8SW — more amplifier power needed, but the
  6.3× displacement advantage dominates at low frequencies
- Verify push-push wiring phase and coupling block fit before finalizing CAD

---

## Configuration: push-push

Two woofers, one front-mounted and one rear-mounted (or both side-mounted facing outward), wired so that as one cone moves outward the other cone also moves outward into free air. This means the reaction forces on the cabinet are equal and opposite, cancelling rather than summing.

See Chapter 8 (Push-push bass) for full detail.

---

## Wiring

Two 4-ohm woofers wired in series: nominal 8 Ω total load.

Parallel wiring (2 Ω total) is possible if the amplifier channel is rated for 2-ohm loads, but series wiring is safer for most DSP/amplifier hardware.

**Confirm impedance before wiring.** The GRS 12SW-4HE is a 4 Ω driver; two in
series gives the intended 8 Ω load. Verify the actual DCR of the delivered drivers
before committing the wiring.

---

## Current status

GRS 12SW-4HE selected (v8). The previous GRS 8SW-4HE-8 is retained as a historical
comparison. Exact mechanical dimensions (cutout 284 mm, frame ~332 mm, mounting
depth ~136 mm, opposed magnet clearance ~4 mm) must be verified before cabinet CAD
is finalized.

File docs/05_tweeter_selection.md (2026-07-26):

# Chapter 5 - Tweeter Investigations

> **UPDATE Jul 25, 2026:** Throat diameter caliper-verified at **32 mm** (not
> 28 mm as estimated below). Recess diameter corrected to **43 mm** (not 53 mm).
> Both values updated in `cad/waveguide.scad`. The 320 mm baffle width mentioned
> below was later changed to 300 mm (see Chapter 7 update note).

---

## Requirements

The tweeter must:

- Cover the range from 1100 Hz to beyond 20 kHz
- Be suitable for mounting in a custom waveguide
- Have sufficient power handling and headroom at 1100 Hz
- Have low distortion at 1100 Hz and above
- Have a dome/surround geometry compatible with the waveguide throat design
- Fit within the 320 mm baffle at 140 mm c-c from the midrange

---

## Selected driver

### SB Acoustics SB26STAC-C000-4

A 26mm soft dome tweeter with cast aluminium faceplate, copper-capped pole piece, and a non-reflective rear chamber with optimized damping.

**Key specifications:**

| Parameter | Value |
|---|---|
| Series | SB26 |
| Type | Conventional soft dome (no built-in horn) |
| Dome diameter | 26 mm / 1" |
| Dome material | Fine weave fabric |
| Impedance | 4 Ω |
| Re | 3.2 Ω |
| **Fs** | **750 Hz** |
| **Sensitivity** | **91.5 dB / 2.83V / 1m** |
| Le | 0.04 mH |
| Qms | 3.0 |
| Qes | 1.78 |
| Qts | 1.12 |
| BL | 1.6 Tm |
| Mms | 0.3 g |
| **Xmax (one-way)** | **0.6 mm** |
| **Linear travel (p-p)** | **1.2 mm** |
| Sd | 6.2 cm² |
| Power (RMS) | 120 W |
| Power test | IEC 268-5, HP Butterworth 2600 Hz 12 dB/oct |
| Faceplate Ø | 100.0 ±0.35 mm |
| BCD | 88.5 ±0.10 mm |
| Mounting holes | 4-Ø4.0 + 4-Ø8.0 counterbore |
| Recess Ø | 53.0 mm |
| Total depth | 39.7 mm |
| Net weight | 0.53 kg |
| Price | ~€37 |
| STEP file | **Not available** (manual caliper measurement required) |

Datasheet: `assets/datasheets/SB26STAC-C000-4.pdf`

---

## Why the SB26STAC was selected

The SB26STAC was chosen through a systematic selection analysis (see
`docs/SB26STAC-C000-4_analysis.md` for the full analysis and simulation
results). Its key advantages:

- **Fs 750 Hz gives 350 Hz margin at the 1100 Hz crossover** — a comfortable
  margin that requires no distortion-test gate before committing to the
  crossover frequency.
- **0.6 mm Xmax gives +8.1 dB excursion headroom** at 1100 Hz — 3× the linear
  travel of a typical 1" dome tweeter, substantially more maximum SPL capability
  near the crossover.
- **91.5 dB sensitivity is a better match to the 15W/4434G00's 89.7 dB** — only
  -1.8 dB of DSP pad is needed. This reduces wasted amplifier power and the
  thermal/level mismatch.
- **No ferrofluid** — vented pole piece instead, eliminating the long-term
  ferrofluid aging concern.

---

## Driver character

The SB26STAC is a conventional dome tweeter — no built-in horn. The dome radiates directly into the waveguide throat, which provides the acoustic loading and directivity control.

The fine weave fabric dome produces a smooth, non-aggressive character. The copper-capped pole piece reduces voice coil inductance and phase shift, improving transient response. The non-reflective rear chamber with vented pole piece provides damping without ferrofluid, eliminating the long-term aging concern.

The 0.6mm one-way Xmax is exceptional for a 1" dome tweeter. This directly translates to higher maximum SPL at the crossover frequency before distortion rises.

---

## Sensitivity matching

At 91.5 dB / 2.83V / 1m, the SB26STAC is 1.8 dB more sensitive than the 15W midrange (~89.7 dB). This requires only ~2 dB of DSP attenuation on the tweeter channel — a natural match.

In the waveguide, the SB26STAC will gain 2-3 dB of acoustic loading, bringing effective sensitivity to ~94 dB. The exact pad is finalized from measurement.

---

## Waveguide integration

The SB26STAC has no built-in horn — the 26mm dome radiates directly. The custom waveguide (`cad/waveguide.scad`) starts its OS bore at Ø28mm (dome + ~1mm surround per side) and provides the full directivity control.

Key waveguide dimensions:

| Parameter | Value |
|---|---|
| Throat diameter | 28 mm (dome + surround) |
| Coverage angles | 100° H × 64° V |
| Mouth size | 293 × 173 mm |
| Total depth | 98 mm |
| Rear plate | Ø115 mm |
| Faceplate pocket | Ø101 × 4mm deep |
| Baffle mounting | Flange recessed into baffle |

**Open item:** The throat diameter (28mm) is estimated from the 26mm dome + surround. The faceplate has a Ø53mm recess around the dome. Physical caliper measurement is needed to confirm the exact throat transition before the final print.

---

## Crossover integration

The tweeter is:
- **High-pass at 1100 Hz LR4**
- Approximately -2 dB gain adjustment in DSP to match midrange sensitivity
- DSP delay applied to align acoustic center with midrange

The 1100 Hz crossover is selected because:
1. **Fs margin:** 350 Hz above the 750 Hz resonance — comfortable, no distortion test gate
2. **Directivity:** Better DI match with the 15W at 1100 Hz (4.6 dB mismatch)
3. **Lobing:** The broadside null for 150mm c-c is at 1147 Hz — just above the 1100 Hz crossover, where LR4 suppression is strongest. ±15° ripple is under 0.7 dB.

See Chapter 11 (Crossovers) and Chapter 14 (DSP) for detail.

---

## Open items

- [ ] Purchase SB26STAC-C000-4 physical unit
- [ ] Caliper measurement: faceplate OD, BCD (88.5 from drawing — confirm), dome surround Ø, total depth, recess Ø, counterbore depth
- [ ] Confirm throat diameter (estimated 28mm — dome + surround)
- [ ] Print waveguide
- [ ] Test fit SB26STAC in waveguide
- [ ] Measure on-axis and off-axis response in waveguide
- [ ] Measure distortion at 1100 Hz (expected to pass comfortably)
- [ ] Confirm c-c spacing to 15W midrange is achievable at 140 mm

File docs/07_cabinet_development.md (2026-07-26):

# Chapter 7 - Cabinet Development

> **UPDATE Jul 8, 2026:** Cabinet dimensions locked at **W300 × D420 × H1180 mm**
> (commit 27850dc). The 320 mm width discussed below was the v9 design at the
> time of writing. It was later reduced to 300 mm after verifying 12SW magnet
> clearance at 256 mm internal width. Bass volume is ~65 L (not 75 L as stated
> below). This chapter is kept as design history.

---

## Design history

The cabinet geometry was developed iteratively across the early concept versions.

| Width | Roundover | Notes |
|---|---|---|
| Initial concept | - | Active 3-way with push-push woofers |
| 280 mm | R20-R40 | Narrower baffle explored, R40 promising |
| 300 mm | R50 | 300/R50 selected as best compromise (DD-007) |
| 320 mm | R19 | Current v9 cabinet — width increased for 12SW magnet clearance |

---

## Current dimensions

| Parameter | Value |
|---|---|
| External width | 320 mm |
| External depth | 380 mm |
| External height | 1180 mm |
| Material | 22 mm birch plywood |
| Front edge roundovers | R19 (vertical edges) |
| Rear/other edges | R20-R30 or chamfers (TBD) |

---

## Cabinet width: 320 mm

The 320 mm wide front baffle is the current v9 cabinet width. Originally 300 mm
was selected (DD-007) as the best compromise, but the width was increased to
320 mm to provide adequate clearance for the opposed GRS 12SW-4HE magnets (only
~4 mm gap at 276 mm internal width with 300 mm external). The 320 mm width gives
276 mm + 2×9 mm = improved internal clearance.

The 320 mm width is the best compromise between:

- **Directivity:** A narrower baffle reduces baffle diffraction effects at high frequencies. 280 mm was investigated but showed only small additional benefits over 300 mm (the original DD-007 width).
- **Diffraction:** The R19 roundovers on the 320 mm baffle smooth diffraction more than was achievable on the narrower 280 mm version with practical roundover radii.
- **Mechanical fit:** 320 mm provides enough width for the waveguide and the woofer cutouts while leaving adequate material for the box sides and bracing.
- **Cabinet volume:** 320 mm provides more internal volume than 280 mm, easing the ~65 L bass chamber requirement (volume under the divider plate).
- **Visual proportion:** 320 mm is a reasonable proportion for a tall reference loudspeaker.

---

## R50 front edge roundovers

The R19 vertical front roundovers (revised from R50 in v9 — see DD-016 and
CHANGELOG) were selected from a comparison of R20, R30, R40, R50, and R70 radii in simplified diffraction simulation.

Larger roundovers produce smoother diffraction, reducing the diffraction ripple in the off-axis response and the predicted in-room response. R19 is a practical radius for the 320 mm wide cabinet using typical woodworking methods (router jig or router table).

The roundover applies to the vertical front edges only. The horizontal top and bottom edges may use smaller roundovers or chamfers depending on the mechanical construction.

---

## Driver placement

### Tweeter / waveguide

The waveguide is mounted at the top of the driver array on the front baffle. The tweeter dome center is approximately 140 mm above the midrange center.

Exact height from the cabinet top is to be determined from the final front baffle layout, with the waveguide centered as close to the top as practical while leaving adequate material above the cutout.

### Midrange

The ScanSpeak 18W/4424G00 is mounted directly below the waveguide. The center-to-center spacing to the tweeter is 165 mm (DD-016, physical minimum with these flanges).

The midrange operates in a dedicated sealed chamber (see Chapter 9: Volume calculations).

### Woofers

Two GRS 12SW-4HE woofers (12" high excursion) are side-mounted in a push-push
configuration, opposed at the same height on the two side panels (directly across
from each other — see Chapter 8). The current placement targets:

- Both woofer centers: approximately 520 mm from the cabinet bottom (nominal;
  same height on both sides)

This height is subject to revision based on:
- Internal bracing layout
- Mid chamber boundaries
- The coupling block between the opposed magnets (push-push symmetry)

---

## Material: 22 mm birch plywood

22 mm Baltic birch plywood is the primary structural material. It offers:

- Consistent density and stiffness compared with MDF
- Good screw retention for threaded inserts
- Manageable weight
- Better moisture resistance than MDF
- Suitability for CNC or hand cutting

The front baffle may use a double layer (44 mm) around the driver cutouts for driver mounting depth and rigidity, depending on the final design.

---

## Front baffle layout

The front baffle must accommodate:

- Waveguide cutout
- ScanSpeak 18W/4424G00 midrange cutout
- R19 vertical front edge roundovers
- 165 mm c-c spacing between waveguide and 18W centers (DD-016)
- Adequate wood remaining between cutouts and edges for structural integrity

The mechanical tightness of this layout is a known constraint (DD-011). The waveguide flange and midrange recess must be designed together.

---

## Internal layout

| Region | Contents |
|---|---|
| Upper section | Mid chamber (~11 L sealed, 18W/4424G00) |
| Main bass chamber | Bass volume (~65 L net, under divider plate) |
| Woofer positions | Side walls, push-push |
| Bracing | Shelf, window, vertical (see Chapter 10) |

---

## Open items

- Finalize exact external dimensions and tolerances
- Develop full 2D front baffle layout drawing
- Verify woofer frame dimensions fit side walls
- Determine front baffle thickness (single vs. double layer)
- Confirm waveguide flange dimensions once CAD is complete
- Generate OpenSCAD or STEP cabinet model

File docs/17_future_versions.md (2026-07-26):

# Chapter 17 - Future Versions

---

## Version roadmap

The Mk3 Reference Loudspeaker is designed to be an evolving platform. The v9 design (GRS 12SW-4HE woofer upgrade, ScanSpeak 18W/4424G00 midrange, SB26STAC-C000-4 tweeter at 1100 Hz, 200 Hz BW4 bass/mid crossover, W300 D420 H1180 cabinet) is the current prototype candidate. Future versions will address remaining limitations and explore more advanced techniques.

---

## v8 - GRS 12SW-4HE woofer upgrade

Woofer upgraded from GRS 8SW-4HE-8 (8") to GRS 12SW-4HE (12" high excursion).

**Changes:**
- 2 × GRS 12SW-4HE push-push woofers (Fs 22 Hz, Xmax 12.5 mm, Sd 504 cm²)
- Bass volume ~65 L under divider plate
- Linkwitz Transform: Fc 39→28 Hz, Qtc 0.76→0.707
- Max SPL @ 30 Hz: +16 dB over v7
- See DD-015

---

## v9 - Midrange upgrade + crossover optimization

The v9 design upgrades the midrange and optimizes the bass/mid crossover.

**Changes from v8:**
- Midrange replaced: ScanSpeak 15W/4434G00 → **18W/4424G00** (Discovery, 18 cm, 91 dB)
- Layout flipped: midrange on top, waveguide/tweeter below, full-width tilted divider between
- Bass/mid crossover: 150 Hz LR4 → **200 Hz BW4** (fills woofer rolloff dip)
- Cabinet width: 300 mm → **320 mm** (12SW magnet clearance), depth 380 mm, height 1180 mm
- Front roundovers: R50 → **R19**
- Mid/tweeter c-c: 150 mm → **165 mm** (physical minimum with 18W faceplate)
- DSP gains rebalanced: **W0/M-4/T-9** (woofer at unity, pad others down)
- DSP correction reduced: ±6 → ±1.3 dB
- See DD-016, DD-017

**Remaining goals (prototype validation):**
- Build prototype cabinet
- Measure all drivers in cabinet
- Import measurements into VituixCAD
- Validate or revise the 1100 Hz crossover for 18 cm cone directivity
- Validate the vertical listening window at 165 mm c-c
- Finalize DSP crossover settings
- Document all measurements

**Success criteria:**
- On-axis response ±1.5 dB after DSP
- DI smooth and rising
- No lobing artifacts in ±15° vertical listening window
- SB26STAC distortion acceptable at 1100 Hz (expected)

---

## v10 - CAD and package refinement

After the prototype is validated acoustically, refine the physical design for a higher-quality final version.

**Goals:**
- Create complete 2D cabinet drawings for CNC or hand cutting
- Finalize waveguide CAD (OpenSCAD or Fusion360/FreeCAD)
- Export STEP/STL files for waveguide printing or machining
- Generate final front baffle layout drawing with exact hole positions
- Refine exterior finish (veneer, solid wood edge, paint)

---

## v11 - DSP implementation

Finalize the DSP implementation for long-term use.

**Goals:**
- Finalize MiniDSP or FusionAmp presets
- Create preset files for three house curves (flat, Harman, bass lift)
- Document all DSP settings with backup files in repository
- Test with multiple sources and listening conditions
- Document startup/shutdown procedure for the active system

---

## v12 - FIR filters

Upgrade the DSP from IIR (Linkwitz-Riley) to FIR (linear phase) crossovers.

**Goals:**
- Implement FIR crossover filters (requires a DSP platform with sufficient tap count)
- Achieve linear phase crossover behavior
- Measure before/after comparison
- Evaluate audibility of the change

**Platform options:**
- miniDSP SHD (Dirac Live, FIR capable)
- ADAU1701/1452 with FIR support
- Linux-based DSP (e.g. Camilla DSP on Raspberry Pi)

---

## v13 - Integrated active electronics

Design and build an integrated amplifier module that fits inside the cabinet.

**Goals:**
- Internal 3- or 4-channel Class D amplifier
- Internal DSP
- Power supply
- Single IEC power input on the rear panel
- Balanced XLR or RCA line-level input
- Clean cable management

**Platform candidates:**
- Hypex FusionAmp (plug-in module)
- Purifi-based custom amplifier
- ADAU1452 custom DSP + separate ICEpower or Purifi amplifier channels

---

## Advanced investigations (Nice To Have)

### Cardioid bass (separate experiment)

Cardioid bass uses a rear-facing woofer with a delay and polarity inversion to produce partial cancellation of the rear wave. This can reduce room excitation by the bass system and improve the in-room bass response.

Inspired by Dutch & Dutch 8C. Requires additional amplifier channel and DSP filters.

### Purifi midrange

The Purifi PTT6.5W04-NFA-01 is a 6.5-inch midrange driver with exceptionally low distortion. It would be a candidate to replace the ScanSpeak 15W in a higher-performance version.

### Klippel NFS measurements

A Klippel NFS (Near Field Scanner) provides a complete spinorama dataset from near-field measurements, without requiring a large outdoor measurement area. Available at some universities and professional labs.

### Public website / GitHub Pages

A GitHub Pages static site with the design documentation, measurement results, and build photos, for sharing the project with the DIY audio community.

---

## Version history

See [ROADMAP.md](../ROADMAP.md) for the full version history.
See [CHANGELOG.md](../CHANGELOG.md) for detailed design changes per version.

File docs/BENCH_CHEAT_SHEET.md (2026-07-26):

# Mk3 Reference Loudspeaker — Bench Cheat Sheet

> Print this (one page). Keep it at the workbench or next to the MiniDSP plugin.

---

## System Overview

| Item | Value |
|---|---|
| **Design** | Active DSP 3-way, sealed, push-push woofers |
| **Cabinet** | W300 × D420 × H1180 mm, 22 mm birch plywood (locked Jul 8) |
| **Bass volume** | ~65 L (under divider plate) |
| **Front roundovers** | R19 mm vertical edges |

---

## Drivers

| Band | Driver | Quantity | Sensitivity | Notes |
|---|---|---|---|---|
| **Woofer** | GRS 12SW-4HE | 2 (push-push) | 84.5 dB | 12" high excursion, Fs 22 Hz, Xmax 12.5 mm |
| **Mid** | ScanSpeak 18W/4424G00 | 1 | 91 dB | Discovery series, 18 cm |
| **Tweeter** | SB Acoustics SB26STAC-C000-4 | 1 | 91.5 dB | Conventional dome, Fs 750 Hz, waveguide-mounted |

---

## Crossover

| Band | Frequency | Slope |
|---|---|---|
| Bass → Mid | **200 Hz** | BW4 (24 dB/oct) |
| Mid → Tweeter | **1100 Hz** | LR4 (24 dB/oct) |

### Why 1100 Hz
- SB26STAC Fs is 750 Hz — 350 Hz margin, no distortion gate needed.
- 1100 Hz is below the broadside null for ~150 mm c-c spacing (1147 Hz).
- Optimisation sweep scored 8.1/10 at this point.

### Wiring
- **Woofers:** wired in **series** → 8 Ω load per side
- Mid: single driver
- Tweeter: single driver
- **Level trim:** woofer 0 dB (unity), mid -4 dB, tweeter -9 dB (W0/M-4/T-9)

---

## Critical Dimensions

| Dimension | Value | Verified? |
|---|---|---|
| Mid/tweeter c-c spacing | **~150-160 mm** (realistic target; 140 mm ideal if D-flange waveguide) | [ ] |
| Tweeter waveguide throat | **32 mm** (caliper-verified Jul 25) | [x] |
| Waveguide mouth | **~293 mm** | [ ] |
| Waveguide BCD | **88.5 mm** (4-hole, Ø4.0 + Ø8.0 CBSK) | [x] |
| 18W cutout | Ø144.3 mm | [ ] |
| 12SW cutout | Ø284 mm | [ ] |
| Cabinet internal width | 256 mm (300 - 2×22 mm walls) | [ ] |
| Opposed woofer magnet clearance | ~4 mm @ 256 mm internal width | [ ] ⚠️ |

> ⚠️ **Verify 12SW magnet clearance with physical driver before cutting panels.**
> Coupling block: h=20 mm, r=55 mm. Basket profile must be checked against a real
> 12SW. The 300 mm cabinet width (256 mm internal) was chosen to provide adequate
> opposed-magnet clearance.

---

## DSP Chain (per channel)

```
Input → Subsonic HP 18 Hz LR4 → Linkwitz Transform → Crossover → Output
```

### Linkwitz Transform (12SW in ~65 L sealed)

| Parameter | Before LT | After LT |
|---|---|---|
| Fc | ~42 Hz (DATS: Fs=23.3, Qts=0.46) | 28 Hz |
| Qtc | ~0.88 (DATS-measured) | 0.707 |

### Delay Estimates (for MiniDSP alignment)

| Driver | Estimated delay | Notes |
|---|---|---|
| Woofer | 0 µs | Reference point |
| Mid | ~0.4-0.6 ms | Acoustic center ~15-20 cm behind woofer |
| Tweeter | ~0.2-0.4 ms | Waveguide mouth behind mid, but smaller depth |

> Measure with REW timing reference for exact values.

---

## Verification Steps (in order)

- [x] **1. Print waveguide** — throat 32 mm ✓, BCD 88.5 mm ✓, caliper-verified Jul 25
- [ ] **2. SB26STAC distortion test** — 1100 Hz, 96 dB. Target: ≤2% THD. If >3%, rethink XO
- [x] **3. Measure T/S on 12SW** — DATS measured, break-in 10h complete: Fs=23.3, Qts=0.46
- [ ] **4. Mock up magnet clearance** — cut cardboard templates from STEP, check opposed gap
- [ ] **5. Full cabinet** — build, mount drivers, seal, wire series
- [ ] **6. DSP load** — import `mk3-v9-200-1100-bw4-lr4.xml` → upload to MiniDSP
- [ ] **7. Nearfield measurements** — each driver individually with REW
- [ ] **8. Gated measurements** — quasi-anechoic at 1 m, full system
- [ ] **9. Iterate** — adjust delay, level, PEQ based on measured response

---

## Cabinet Construction Notes

- **12SW cutout:** 284 mm — significantly larger than the old 8SW (185 mm)
- **Bracing:** new angle divider plate (12°) in cad/ — reduces internal reflections
- **Vertical braces** added to all panels in cad/
- **Ideal panel material:** 24 mm plywood (18 mm minimum + 3 mm laminate)
- **Internal volume:** target ~75 L under divider plate after deducting braces

---

## Tooling Reference

| Tool | Purpose |
|---|---|
| **MiniDSP 4×10 HD** | Active crossover, EQ, delay |
| **REW** | Measurements, gating, distortion, timing |
| **OpenSCAD + cad/** | Waveguide profile, cabinet model, STL export |
| **dsp-configs/generate_minidsp_xml.py** | Regenerate MiniDSP XML (modify freq/gain/delay) |
| **dsp-configs/generate_biquads.py** | Regenerate biquad coefficients |

---

## Quick Links

| File | What it covers |
|---|---|
| `DESIGN_DECISIONS.md` | All DD entries with rationale |
| `docs/07_cabinet_development.md` | Cabinet design evolution |
| `docs/11_crossovers.md` | Crossover design and optimization |
| `docs/14_dsp.md` | Full DSP architecture |
| `docs/16_build_guide.md` | Assembly instructions |
| `cad/` | All CAD files (cabinet, waveguide, braces) |
| `simulations/` | Simulation scripts and outputs |
| `dsp-configs/` | MiniDSP XML configs + generators |

---

*Last updated: July 26, 2026 — v9 (18W/4424G00 midrange, 200 Hz BW4 crossover, W300 D420 cabinet, DATS-measured drivers).*

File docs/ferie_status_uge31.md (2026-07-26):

# Mk3 Prototype — Status før ferie (uge 31-33)

**Dato:** 25. juli 2026 (lørdag aften)
**Næste handling:** Første værkstedsdag efter ferie

## ✅ Hvad er klart

| Område | Status | Detaljer |
|---|---|---|
| **Cabinet design** | LÅST (v9) | W300 D420 H1180, 22mm birkekrydsfiner. CAD, STL, cut-SVG, BOM alle genereret. |
| **Push-push woofers** | LÅST | 2× GRS 12SW-4HE, side-mounted, 65 L shared sealed chamber. |
| **Waveguide** | VERIFICERET | Throat 32mm ✅, recess ØD 43mm ✅ (caliper 25/7). Waveguide.scad opdateret. Mockup printet og impedans-målt. |
| **Crossover frekvenser** | LÅST | 200 Hz BW4 + 1100 Hz LR4. Bekræftet optimal (175 Hz testet og afvist). |
| **DSP config** | KLAR | `mk3-sb26stac-200hz-bw4.xml`. Gains W0/M-4/T-9. Subsonic 18 Hz LR4. |
| **BOM v9** | KLAR | ~EUR 800/pair aktivt. Alle driverpartnumre, tilbehør, dæmpematerialer. |
| **Bench cheat sheet** | KLAR | `docs/BENCH_CHEAT_SHEET.md` med byggeprocedure og mål. |
| **CI/CD** | GRØN | cad-r32 udgivet. 12 sims → STL → 34 renders → cut SVGs → deploy. Auto-release aktiveret. |

## 🔬 Driver-målinger (DATS, 25. juli)

### GRS 12SW-4HE (woofer, 2 stk.)

| Parameter | Datasheet | Målt 0h | Målt 5h | Målt 10h | Forskel (10h) |
|---|---|---|---|---|---|
| Fs | 22 Hz | 25.1 Hz | 23.5 Hz | 23.3 Hz | +5.7% ✅ |
| Qts | 0.43 | 0.51 | 0.44 | 0.46 | +7.3% ✅ |
| Re | 3.7 Ω | 4.20 Ω | 4.23 Ω | 4.40 Ω | +18.9% ⚠ (kold recheck) |
| Vas | 80.4 L | 80.4 L (antaget) | — | — | — |

**Konsekvens:** Qtc = 0.88 i 65 L (vs 0.80 datasheet). Linkwitz Transform kan stadig rette til 28 Hz / Q 0.707. **Kabinet uændret.** Break-in færdig efter 10h.

Anden 12SW er ikke målt endnu — bør matches til push-push.

### ScanSpeak 18W/4424G00 (midrange)

| Parameter | Datasheet | Målt 0h | Målt 5h | Proj. 10h | Proj. 15h | Proj. 20h |
|---|---|---|---|---|---|---|
| Fs | 49 Hz | 69.4 Hz | 64.5 Hz | 61.6 Hz | 59.8 Hz | 58.7 Hz |
| Qts | 0.38 | 0.598 | 0.576 | 0.559 | 0.546 | 0.535 |
| Qtc (13 L) | 0.60 | 0.94 | 0.91 | 0.88 | 0.86 | 0.84 |
| Fc (13 L) | 76.9 Hz | 109.0 Hz | 101.2 Hz | 96.7 Hz | 93.9 Hz | 92.0 Hz |

**Estimater baseret på eksponentiel decay-model** (se `simulations/plots/breakin_projection.png`):
- **Optimistisk scenarie** (Fs→57, Qts→0.50): τ_Fs=10h, τ_Qts=20h. 90% efter ~23h (Fs) og ~45h (Qts).
- **Konservativt scenarie** (Fs→60, Qts→0.55): τ_Fs=6.8h, τ_Qts=8.2h. 90% efter ~16h (Fs) og ~19h (Qts).
- **Reelt estimat:** Forvent Fs ~55-60 Hz, Qts ~0.50-0.55 efter 20-25h break-in.

**Break-in plan:**
| Milestone | Handling |
|---|---|
| 10h (1. session efter ferie) | Re-mål DATS |
| 15h (2. session) | Re-mål DATS — forvent 70-80% af total ændring |
| 20h (3. session) | Re-mål DATS — forvent ~90% settled. Herefter kan DSP biquads regnes. |

Næste 5h break-in blok giver ~3 Hz Fs-forbedring (5→10h). Derefter aftager udbyttet: 10→15h giver ~2 Hz, 15→20h giver ~1 Hz.

**Design note:** Selv med Fc=101 Hz (5h) er mid-kammeret fint da krydset er 200 Hz BW4. Ingen kabinetændring nødvendig.

### SB26STAC-C000-4 (tweeter)

| Parameter | Datasheet | Målt fri luft | I waveguide | Forskel |
|---|---|---|---|---|
| Fs | 750 Hz | 658 Hz | 632 Hz | −12% / −16% ✅ |
| Re | 3.2 Ω | 3.22 Ω | 3.27 Ω | <1% ✅ |
| Qts | 1.12 | 1.04 | 1.08 | −7% / −4% ✅ |

**Konklusion:** Fremragende match. Waveguide loading mild (Fs −4%, Qts +3.8%). Crossover margin 468 Hz (632 vs 1100 Hz LR4). Ingen justering nødvendig.

### Fysiske mål (SB26STAC, caliper 25/7)
- Throat: 32 mm (var 28 mm i CAD — rettet)
- Recess: 43 mm (var 53 mm — rettet)
- Alle øvrige mål inden for tolerance
- Waveguide.scad opdateret og pushed

## 📋 Mangler efter ferien (uge 34 →)

### 🔴 Skal gøres før prototype

| # | Opgave | Estimeret tid | Note |
|---|---|---|---|
| 1 | **18W break-in færdiggør** (15h + 20h måling) | 1 døgn | Start når du er hjemme. Re-mål DATS efter hver session. |
| 2 | **Mål anden GRS 12SW** | 15 min | Skal matche første (Qts indenfor ±0.03 for push-push). |
| 3 | **Opdater DSP biquads** med endelige DATS-værdier | 1 time | Script: `generate_minidsp_xml.py`. |
| 4 | **SB26STAC distortion test** ved 1100 Hz | 30 min | Bekræft at krydset er sikkert. |

### 🟡 Prototype-byg

| # | Opgave | Note |
|---|---|---|
| 5 | Indkøb materialer (BOM v9) | ~EUR 800. 22mm birkekrydsfiner + dæmpematerialer + skruer/lim. |
| 6 | Skær cabinet-paneler | Cut SVGs i `cad/cut/`. CNC eller håndværktøj. |
| 7 | Montér kabinet | Lim/skru, dæmpematerialer, divider-plade, waveguide. |
| 8 | Montér drivere | Push-push 12SW, 18W, SB26STAC. |
| 9 | Indmåling og DSP-tuning | REW-måling i stuen. Justér PEQ. |

### 🔵 Når prototypen spiller

| # | Opgave |
|---|---|
| 10 | Distortion + max SPL test |
| 11 | Kabinet-resonans test (accelerometer) |
| 12 | Endelig DSP config færdiggør |
| 13 | Byg nummer to |

## 📈 Hvad pipeline gør i ferien

- **Outlook pipeline** — kører hver 3. time hverdage: invoices → info@, spam filtreres, drafts forberedes. **Config issue:** nogle invoices går stadig til lb@ — kan ikke rettes uden Make-adgang.
- **Defender incident 23** — stadig ulæst (dag 15). Skal tjekkes.
- **CodeTwo SIU** — afventer din handling.
- **Milair-history-proxy** — kører stabilt (3,174 rows / 447 aircraft).
- **Stock monitoring** — næste automatiske check mandag morgen.

## 🔗 Nøgle-filer

| Fil | Formål |
|---|---|
| `docs/BOM_v9.md` | Indkøbsliste |
| `cad/cabinet.scad` | Cabinet source of truth |
| `assets/datasheets/` | Datasheets + STEP |
| `simulations/DATS_FINDINGS.md` | DATS resultater |
| `dsp/mk3-sb26stac-200hz-bw4.xml` | DSP config |
| `docs/BENCH_CHEAT_SHEET.md` | Værkstedsprocedure |

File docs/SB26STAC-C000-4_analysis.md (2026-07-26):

# SB Acoustics SB26STAC-C000-4 — Tweeter Selection Analysis

**Date:** July 4, 2026
**Purpose:** Selection analysis for the Mk3 Reference Loudspeaker tweeter
**Datasheet:** `assets/datasheets/SB26STAC-C000-4.pdf`

This document records the analysis behind the selection of the SB26STAC-C000-4
as the project tweeter. It compares the SB26STAC against an earlier horn-dome
candidate (the ScanSpeak H2606/920000) that was evaluated and set aside during
the design process. The H2606 data is retained here as the historical
comparison baseline that justified the SB26STAC selection — it is not a current
design option.

---

## Driver Summary

The SB26STAC-C000-4 is a 26mm soft dome tweeter from SB Acoustics with a cast aluminium faceplate, copper-capped pole piece, and a non-reflective rear chamber with optimized damping. It is a **conventional flush-mount dome tweeter**, not a horn-loaded tweeter.

Key features: low Fs (750 Hz), CCAW voice coil, vented pole piece, silver lead wires, saturation-controlled motor.

---

## Side-by-side comparison (selection baseline)

| Parameter | SB26STAC-C000-4 | H2606/920000 (evaluated, set aside) | Notes |
|---|---|---|---|
| **Type** | Conventional soft dome | Horn dome tweeter | Fundamentally different |
| Dome | 26mm fine weave fabric | 25mm coated textile | Similar |
| **Impedance** | 4 Ω | 6 Ω | SB26 draws more current |
| Re | 3.2 Ω | 4.7 Ω | |
| **Fs** | **750 Hz** | **1030 Hz** | **280 Hz lower — the key difference** |
| **Sensitivity** | 91.5 dB/2.83V/1m | 95.2 dB/2.83V/1m | SB26 is 3.7 dB less sensitive |
| Le | 0.04 mH | 0.05 mH | Similar |
| Sd | 6.2 cm² | 5.7 cm² | SB26 slightly larger |
| **Linear travel (p-p)** | **1.2 mm (0.6 mm one-way)** | **0.2 mm** | **SB26 has 3× more excursion** |
| Qms | 3.0 | 2.1 | SB26 has taller, broader resonance |
| Qes | 1.78 | 1.2 | |
| Qts | 1.12 | 0.70 | SB26 resonance is less damped |
| Bl | 1.6 Tm | 3.3 Tm | H2606 has 2× stronger motor |
| Mms | 0.3 g | 0.4 g | |
| Power (RMS) | 120 W | 100 W | SB26 rated higher |
| Power test freq | 2600 Hz | — | SB26 tested at 2600 Hz |
| **Faceplate Ø** | ~100 mm | 104 mm | SB26 is 4 mm smaller |
| Baffle cutout | 88.5 mm | ~96 mm | From drawing dimensions |
| Recess Ø | 53.0 mm | — | Recess around dome |
| **BCD** | **88.5 ±0.10 mm** | 95.0 mm | **6.5 mm smaller — confirmed from drawing** |
| Screw holes | 4-Ø4.0 + 4-Ø8.0 cb | 4-Ø4.0 | SB26 has counterbores |
| **Throat / horn exit** | **None (direct radiator)** | **Ø33 mm** | **SB26 has no horn** |
| Rear chamber | Yes (damped, vented) | Yes | Both have rear chambers |
| Ferrofluid | No | Yes | H2606 has ferrofluid cooling |
| Total depth | 39.7 mm | ~44 mm | SB26 is shallower |
| Net weight | 0.53 kg | — | |
| Price | ~€35-40 | ~€44 | SB26 is cheaper |
| STEP file | **Not available** | Yes (from ScanSpeak) | SB26 requires manual measurement |

---

## Analysis

### 1. Fs and crossover margin — THE deciding factor

This is the single most important difference. The H2606's Fs of 1030 Hz with only 220 Hz margin to a 1250 Hz crossover was the project's critical risk — it would have required a distortion test gate before the crossover could be confirmed.

The SB26STAC at Fs=750 Hz gives a **350 Hz margin** at the 1100 Hz crossover. An LR4 high-pass at 1100 Hz is 24 dB/oct above a resonance that's 1.47× below the crossover. This is a very comfortable margin — no distortion-test gate is required. The 1100 Hz crossover also sits below the 150 mm c-c broadside null (1147 Hz), so the null falls outside the active crossover band.

The higher Qts (1.12 vs 0.70) means the resonance peak is taller and broader, but with 350 Hz of separation and 24 dB/oct slopes, the resonance contribution at the crossover is negligible.

**Verdict: SB26STAC completely solves the crossover margin problem.**

### 2. Excursion — 3× more headroom

The H2606's 0.2mm Xmax is the physical reason a low crossover with that driver is risky. At low frequencies, dome excursion increases rapidly (4th power of 1/f for constant SPL). The SB26STAC's 0.6mm one-way linear travel gives 3× the displacement headroom. At 1100 Hz, this translates to +8.1 dB more maximum SPL before distortion rises — a massive improvement.

**Verdict: SB26STAC has dramatically better low-frequency headroom.**

### 3. Sensitivity — 3.7 dB lower, but better system match

The 91.5 dB sensitivity is 3.7 dB below the H2606's 95.2 dB. However:
- The 15W midrange is ~89.7 dB. The H2606 would require 5-7 dB of DSP attenuation to match. The SB26STAC needs only ~2 dB attenuation — a better natural match.
- In a waveguide, the SB26STAC gains 2-3 dB of loading, bringing effective sensitivity to ~94 dB.
- The active DSP system can compensate for any sensitivity difference. This is a non-issue for the design, just an amp power consideration.

**Verdict: Minor disadvantage individually, better match system-wide.**

### 4. No horn loading — requires a dedicated waveguide

This is the fundamental design difference. The H2606 is a horn tweeter whose Ø33mm throat exit was designed to couple directly into a horn-continuation waveguide. The SB26STAC is a conventional dome with no horn — its 26mm dome radiates directly into the waveguide throat.

Using the SB26STAC means the waveguide is a pure directivity device rather than a horn extension:
- **Throat:** starts at ~28mm (the dome + surround) and transitions into the waveguide profile.
- **Mounting:** the faceplate is ~100mm with an 88.5 mm BCD and 4-Ø4.0 through + 4-Ø8.0 counterbore screws.
- **No STEP file:** all dimensions must be caliper-measured from a physical unit.
- **Directivity:** a bare dome in a waveguide has different throat impedance and radiation characteristics than a horn-loaded dome. The directivity simulations use the appropriate assumptions.

**Verdict: A dedicated non-horn-loaded waveguide design — which is what `cad/waveguide.scad` provides.**

### 5. No ferrofluid — thermal and damping differences

The H2606 uses ferrofluid for both cooling and mechanical damping. The SB26STAC uses a vented pole piece and damped rear chamber instead. Without ferrofluid:
- Thermal handling at sustained high SPL may be slightly worse (no fluid to conduct heat from the voice coil to the magnet)
- Mechanical damping is lower (Qms 3.0 vs 2.1), which contributes to the lower Fs but also means the resonance is less controlled
- No ferrofluid aging concern (ferrofluid can dry out over years)

**Verdict: Acceptable trade-off. The vented pole piece and rear chamber are a legitimate alternative approach.**

### 6. Mechanical dimensions

| Dimension | SB26STAC | H2606 | Waveguide impact |
|---|---|---|---|
| Faceplate Ø | ~100 mm | 104 mm | Back plate recess needs resize |
| BCD | 88.5 mm | 95 mm | 6.5 mm smaller — manageable |
| Throat | None (26mm dome) | Ø33 mm | Waveguide bore designed for bare dome |
| Depth | 39.7 mm | ~44 mm | Less depth needed in cabinet |
| Recess Ø | 53 mm | — | Feature in waveguide |

**The BCD is 88.5 ±0.10 mm — confirmed from the dimension drawing.**

---

## Overall assessment

### What the SB26STAC delivers
- **Crossover margin:** Fs 750 Hz gives 350 Hz margin at 1100 Hz. No distortion-test gate required.
- **Excursion:** 3× more linear travel means +8.1 dB more SPL headroom at the crossover frequency.
- **Sensitivity match:** Better natural match to the 15W midrange (1.8 dB gap vs 5.5 dB).
- **Directivity:** Lower crossover (1100 Hz) gives a smaller DI step with the 15W (4.6 dB mismatch vs 5.3 dB at 1250 Hz).
- **Lobing:** Crossing at 1100 Hz puts the broadside null (1147 Hz for 150mm c-c) just above the crossover, where LR4 suppression is strongest. ±15° ripple under 0.7 dB.

### What it costs (and how it's handled)
- **No STEP file** → physical unit needed for caliper verification (same as the GRS woofer situation).
- **Dedicated waveguide design** → `cad/waveguide.scad` (STL rendered and manifold-verified).
- **3.7 dB lower sensitivity** → compensated in DSP, and actually a better match to the 15W.
- **Loss of horn loading** → the waveguide provides the loading instead (that's its purpose).

**The SB26STAC-C000-4 wins on every acoustic parameter that matters.** The
H2606's only real advantages were the horn loading (higher sensitivity) and a
STEP file (CAD convenience) — both outweighed by the SB26STAC's acoustic
superiority.

---

## Datasheet location

`assets/datasheets/SB26STAC-C000-4.pdf`

## Waveguide CAD

The waveguide for the SB26STAC is `cad/waveguide.scad`.

**STL rendered and validated:** `cad/exports/waveguide.stl` (manifold)

### Key dimensions

| Parameter | Value |
|---|---|
| throat_d | 32 mm (dome + surround, caliper-verified Jul 25) |
| tw_face_d | 100.0 mm |
| tw_bcd | 88.5 mm |
| tw_ring_od | 115 mm |
| Counterbores | 4-Ø8.0 × 2mm |
| tw_recess_d | 53.0 mm |
| Mouth size | ~289 × 172 mm |
| Total depth | 98 mm (D_os + Lr = 65 + 25) |
| Flange | 242 × 143 mm |
| Coverage angles | θh=50°, θv=32° (~100° × 64°) |
| Crossover target | 1100 Hz LR4 |

The OS profile, coverage angles, mouth roundover, and baffle mounting are all
designed for the bare-dome throat interface. The cabinet baffle cutout, flange
mounting, and external appearance are driven by this waveguide model.

---

## Simulation results

### Excursion headroom at crossover

The single most important metric. Relative max SPL before distortion rises, normalized to H2606 @ 1250 Hz = 0 dB (historical baseline):

| Scenario | Driver | Fc | Fs | Margin | Xmax | Rel. max SPL |
|---|---|---|---|---|---|---|
| H2606 @ 1250 Hz (baseline) | H2606 | 1250 | 1030 | 220 Hz | 0.2 mm | **0.0 dB (reference)** |
| H2606 @ 1450 Hz | H2606 | 1450 | 1030 | 420 Hz | 0.2 mm | +2.6 dB |
| SB26 @ 1000 Hz | SB26STAC | 1000 | 750 | 250 Hz | 0.6 mm | **+6.4 dB** |
| **SB26 @ 1100 Hz (selected)** | SB26STAC | 1100 | 750 | 350 Hz | 0.6 mm | **+8.1 dB** |
| SB26 @ 1250 Hz | SB26STAC | 1250 | 750 | 500 Hz | 0.6 mm | **+10.3 dB** |

The SB26STAC has **6-10 dB more SPL headroom** at the crossover frequency than the H2606 baseline, depending on where you cross. This is the 3× excursion advantage (0.6mm vs 0.2mm) compounding with the lower Fs.

### Directivity match (DI mismatch with 15W midrange)

| Crossover | DI 15W | DI waveguide | Mismatch |
|---|---|---|---|
| 1000 Hz | 1.0 dB | 5.3 dB | **+4.3 dB** |
| 1100 Hz | 1.0 dB | 5.7 dB | **+4.6 dB** |
| 1250 Hz | 1.0 dB | 6.3 dB | +5.3 dB |
| 1450 Hz | 1.0 dB | 7.2 dB | +6.2 dB |
| 1600 Hz | 1.0 dB | 8.0 dB | +6.9 dB |

Lower crossover = smaller directivity step. The SB26STAC at 1100 Hz gives a **0.7 dB better directivity match** than the H2606 at 1250 Hz.

### Vertical lobing (c-c = 150 mm, LR4)

| Crossover | First null angle | Null depth | SPL at ±15° |
|---|---|---|---|
| 1000 Hz | 90° | -14.0 dB | -0.6 dB |
| 1100 Hz | 90° | -23.9 dB | -0.7 dB |
| 1250 Hz | 67° | -66.5 dB | -0.9 dB |
| 1450 Hz | 52° | -54.8 dB | -1.2 dB |

The broadside null for 150mm c-c is at 1147 Hz. Crossing **below** this (1100 Hz) pushes the null above the crossover frequency, meaning it falls outside the active crossover band. At ±15° the ripple is under 1 dB for all scenarios.

**Key insight:** Crossing at 1100 Hz with the SB26STAC is the sweet spot. The broadside null (1147 Hz) sits just above the crossover, so the LR4 rolloff suppresses it almost entirely. At ±15° the response is within 0.7 dB.

### Comparison plot

`sims/plots/h2606_vs_sb26stac_comparison.png` — 4-panel comparison: excursion headroom, directivity match, vertical lobing, and feature bar chart.

---

## Open items

- [ ] Purchase SB26STAC-C000-4 physical unit
- [ ] Caliper measurement: faceplate OD, BCD (88.5 from drawing — confirm), dome surround Ø, total depth, recess Ø, counterbore depth
- [ ] Confirm counterbore depth (estimated 2mm — not on drawing)
- [x] Confirm throat diameter (32mm — caliper-verified Jul 25, 2026)
- [ ] Print waveguide and test-fit SB26STAC
- [ ] Measure SB26STAC in-waveguide response and directivity at 1100 Hz (expected to pass comfortably)

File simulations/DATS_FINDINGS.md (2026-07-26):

# DATS vs Datasheet — Simulation Results

**Dato:** Lørdag 25. juli 2026
**Script:** `simulations/dats_vs_datasheet_bass.py`
**Output plot:** `simulations/plots/dats_vs_datasheet_bass.png`

## Resultater

### Bass: 2× GRS 12SW-4HE (65 L sealed)

| Parameter | Datasheet | DATS Jul 25 | Forskel |
|---|---|---|---|
| Qts | 0.43 | **0.51** | +19% |
| Qtc (i 65 L) | 0.80 | **0.95** | Højere |
| Fc | 41.0 Hz | 41.0 Hz | Ingen |
| LT boost | 41→28 Hz, Q 0.80→0.71 | 41→28 Hz, Q 0.95→0.71 | Kraftigere EQ |

**Konklusion:** Den højere Qts (0.51 vs 0.43) giver en Qtc på 0.95 i stedet for 0.80. Det betyder en smallere, mere peaker respons før EQ — ca. 1-2 dB mere udstråling omkring Fc. Linkwitz Transform kan stadig rette det til 28 Hz/Q 0.707, men kræver lidt mere EQ-boost. **Acceptabelt — kabinettet behøver ikke ændres.**

### Mid: 18W/4424G00 (13 L sealed)

| Parameter | Datasheet | DATS 5h BI | Forskel |
|---|---|---|---|
| Fs | 49.0 Hz | **64.5 Hz** | +32% |
| Qts | 0.38 | **0.58** | +53% |
| Qtc | 0.60 | **0.91** | Kraftig |
| Fc | 76.9 Hz | **101.2 Hz** | +24 Hz |

**Konklusion:** Mid'en er stadig i break-in. Fc på 101 Hz vs forventet 77 Hz betyder mindre low-end headroom i mid chamber — men da krydset er 200 Hz BW4, er det **stadig fint**. ScanSpeak-spec (Fs=49, Qts=0.38) forventes at nærme sig efter 15-20h break-in. Følg op med re-måling ved 15h og 20h.

## Anbefaling

1. **Cabinet uændret** — begge driveres afvigelser er indenfor justeringsområdet for DSP
2. **18W break-in fortsætter** — re-mål ved 15h og 20h
3. **DSP config opdateres** når 18W er stabiliseret

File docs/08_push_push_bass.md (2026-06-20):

# Chapter 8 - Push-Push Bass

---

## What is push-push?

A push-push bass configuration uses two woofer drivers mounted on opposite sides of the cabinet (or the same side in opposing orientations), wired so that as one cone moves outward (away from the cabinet), the other cone also moves outward.

From the perspective of an external observer, both cones move in the same direction simultaneously. From the perspective of the cabinet, the reaction forces from the two drivers act in opposite directions and therefore cancel each other.

---

## Why push-push?

### Cabinet vibration reduction

Each woofer driver exerts a reaction force on the cabinet equal and opposite to the force it exerts on the air. In a conventional single-woofer design, this force causes the cabinet to vibrate at bass frequencies.

In push-push, the two reaction forces are opposite and cancel at the cabinet. The net force on the cabinet is close to zero. This significantly reduces cabinet vibration and the associated structural resonances.

### Front baffle kept clear

Side mounting both woofers leaves the front baffle free for the midrange and tweeter/waveguide array. This simplifies the front baffle layout and avoids a woofer cutout near the midrange driver.

### Symmetrical cabinet structure

Two symmetrically placed woofers produce a mechanically symmetric cabinet structure. The side panels experience equal loading.

---

## Physical arrangement

For the Mk2 Reference Loudspeaker, both woofers are mounted on the side panels:

- One woofer on the left side panel
- One woofer on the right side panel
- Both woofers facing outward (magnets facing inward)
- **Centers opposed at the same height** (directly across from each other)

Mounting the two drivers directly opposite at the same height is the correct
push-push arrangement: the two reaction forces share a single line of action and
cancel as a clean couple, with no rocking moment. A vertical stagger (mounting
one driver higher than the other) offsets that line of action and re-introduces
a rocking moment on the cabinet, so it is avoided. (An earlier layout proposed a
~350 mm / ~700 mm stagger; this has been dropped — see [REVIEW.md](../REVIEW.md) §C3.)

The geometry fits: the GRS overall depth is ~117 mm, so in the ~256 mm internal
width two opposed magnets leave roughly `256 − 2×117 ≈ 22 mm` of static clearance
between them (the magnets are fixed to the baskets/walls and do not move). That
gap is enough to bond a short rigid coupling block between the two magnet
assemblies — see *Mechanical coupling* below.

---

## Wiring

In a push-push configuration, the wiring polarity determines whether the drivers work together or against each other.

**Correct wiring (push-push):**
- Both driver cones move outward simultaneously
- The magnetic polarity of the two drivers is opposite relative to the current direction
- In practice: wire the two 4-ohm drivers in series, with one driver's positive terminal connected to the other's negative terminal

**Verification test:**
1. Apply a DC voltage (e.g. from a battery) briefly to the series combination
2. Both cones should move in the same direction (both out or both in)
3. If one moves out and one moves in, the wiring is incorrect (push-pull, not push-push)

---

## Push-push vs push-pull

These two terms are often confused.

| Configuration | Cone movement | Cabinet reaction | Acoustic output |
|---|---|---|---|
| Push-push | Both move out together | Forces cancel | Normal (full) |
| Push-pull | One out, one in | Forces add | Cancels (net zero) |

Push-pull cancels the acoustic output - it is not useful for producing bass. Push-push is the correct configuration for a bass radiator system.

---

## Mechanical coupling

With the two drivers opposed at the same height, a short rigid **coupling block**
is bonded across the ~22 mm gap between the magnet assemblies. This ties the two
motors together so they cannot independently excite the cabinet side panels — the
ideal force-cancelling arrangement, and the main reason same-height opposed
placement is preferred over a stagger.

The block must not significantly obstruct the bass chamber air flow. Its size and
fixing are finalized in CAD and confirmed in the prototype phase.

---

## Expected benefits

- Reduced cabinet panel excitation in the bass range
- Potentially audible reduction in bass coloration from cabinet resonances
- Clean front baffle for midrange/tweeter integration

---

## Open items

- Confirm the opposed woofer center height matches the bracing layout
- Verify the coupling block fits the ~22 mm magnet gap in the 300 × 370 mm cross-section without choking air flow
- Develop polarity test procedure for prototype verification
- Measure cabinet vibration with and without push-push coupling (optional)

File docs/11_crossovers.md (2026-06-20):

# Chapter 11 - Crossovers

---

## Approach

The Mk2 Reference Loudspeaker uses an active DSP crossover. There is no passive crossover. Each driver has its own amplifier channel.

See Chapter 14 (DSP) for the full DSP implementation. This chapter covers the crossover topology and the acoustic targets.

---

## Crossover frequencies

| Crossover | Frequency | Slope | Drivers |
|---|---|---|---|
| Bass / midrange | 150 Hz | LR4 (24 dB/oct) | GRS woofers → ScanSpeak 15W |
| Midrange / tweeter | 1250 Hz | LR4 (24 dB/oct) | ScanSpeak 15W → ScanSpeak H2606/920000 / WG212 |

---

## Linkwitz-Riley 4th-order (LR4) crossover

The LR4 crossover is the standard choice for active multi-way loudspeakers. Its properties:

- **-6 dB at the crossover frequency** for each driver
- **Summed acoustic response is flat** at all frequencies when drivers are in phase and perfectly aligned
- **4th order (24 dB/octave) slopes** provide fast rolloff, reducing out-of-band driver stress and lobing
- **Phase matched** at the crossover frequency (both drivers are 180° out of phase at Fc, but this is corrected by time delay in DSP or physical offset)

LR4 crossovers can be implemented as a cascade of two 2nd-order Butterworth filters, or directly as a 4th-order IIR filter in the DSP.

---

## Bass / midrange: 150 Hz

The 150 Hz crossover was selected to:
- Relieve the ScanSpeak 15W of bass reproduction (below 150 Hz is handled by the woofers)
- Keep the GRS woofers within their optimal operating range
- Allow the 15W to reproduce the lower midrange (150-500 Hz) without excessive excursion

**Woofer low-pass:** 150 Hz LR4
The woofers are rolled off at 150 Hz. Below 150 Hz the full bass SPL is produced by the GRS push-push system. The bass system also receives a high-pass filter at approximately 20 Hz to protect the woofers from infrasonic content.

**Midrange high-pass:** 150 Hz LR4
The 15W midrange is high-passed at 150 Hz. This removes bass loading from the midrange driver and the mid chamber.

**Phase alignment:** The acoustic centers of the woofers and the midrange are at different physical positions. DSP delay must be applied to align them at the crossover frequency.

---

## Midrange / tweeter: 1250 Hz

The 1250 Hz crossover was selected in v6b (DD-010) based on simplified directivity simulations showing that:
- Lower crossover frequencies improve directivity matching between the midrange and the waveguide tweeter
- The 140 mm c-c spacing produces acceptable vertical lobing at 1250 Hz but would produce worse lobing at higher frequencies
- The H2606 in WG212 is expected to handle 1250 Hz LR4, but this must be verified by distortion measurement

**Midrange low-pass:** 1250 Hz LR4
The 15W is rolled off above 1250 Hz.

**Tweeter high-pass:** 1250 Hz LR4
The H2606 in WG212 is high-passed at 1250 Hz.

**Phase alignment:** The acoustic centers of the midrange and the tweeter/waveguide are at different positions. DSP delay will be used to align them. The waveguide also adds physical depth to the tweeter's acoustic center.

---

## Vertical lobing at the mid/tweeter crossover

The two-driver interference pattern at the mid/tweeter crossover creates lobing in the vertical plane. The lobing frequency and severity depend on:

- The center-to-center (c-c) spacing between the midrange and tweeter
- The crossover frequency
- The crossover slope

For two drivers with a c-c spacing of d, the first lobe null occurs at approximately:

```
f_null = c / (2 × d × sin(θ))
```

where c is the speed of sound (~344 m/s), d is the c-c spacing in meters, and θ is the off-axis angle.

For d = 140 mm and θ = 90° (broadside null):
```
f_null = 344 / (2 × 0.14) ≈ 1229 Hz
```

This means the 140 mm c-c spacing produces a broadside null near 1229 Hz - close to the 1250 Hz crossover frequency. This is acceptable because:
- LR4 slopes transition the energy between drivers over a wide range
- The crossover suppresses the 15W output at 1250 Hz (it is already at -6 dB at the crossover frequency)
- The lobing at the listening angle (±15° vertical) is much less severe than the theoretical broadside null

Shorter c-c spacing reduces lobing severity and pushes the null higher. Increasing the crossover frequency with the same c-c spacing worsens the lobing.

---

## DSP implementation

See Chapter 14 (DSP) for the filter coefficients, delay values, and EQ.

---

## Open items

- Measure H2606 in WG212 distortion at 1250 Hz to confirm crossover viability
- Measure acoustic centers of all three driver systems in the final cabinet
- Calculate and apply DSP delay values
- Verify crossover summation in measurement (flat on-axis, smooth off-axis)
- Adjust crossover frequency if distortion measurement requires it

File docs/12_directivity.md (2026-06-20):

# Chapter 12 - Directivity

---

## What is directivity?

Directivity describes how a loudspeaker radiates sound in different directions. A loudspeaker with ideal directivity control radiates smoothly controlled patterns at all frequencies, with the pattern narrowing gradually with frequency as expected from the geometry.

Poor directivity produces:
- Sudden changes in the off-axis pattern at crossover frequencies ("directivity step")
- Narrow vertical lobes from c-c spacing at crossover
- Diffraction artifacts from cabinet edges
- Irregular reflections in the listening room

---

## Directivity Index (DI)

The Directivity Index is the difference in dB between the on-axis response and the sound power response (the integrated energy radiated in all directions).

A smooth, monotonically rising DI is a sign of well-controlled directivity. It indicates:
- The loudspeaker becomes gradually more directional at higher frequencies (as expected from increasing source size relative to wavelength)
- There are no abrupt directivity transitions

Irregularities in the DI (dips, steps, irregularities) indicate directivity problems at those frequencies.

---

## Sources of directivity problems

### Crossover directivity mismatch

At the crossover frequency, two drivers of different sizes transition between each other. If their off-axis responses do not match at the crossover frequency, the combined off-axis response will show a step or dip.

For the mid/tweeter crossover at 1250 Hz:
- The ScanSpeak 15W midrange at 1250 Hz radiates over a moderate angle (the ~120 mm cone diameter is beginning to narrow the pattern)
- The ScanSpeak H2606/920000 already has a built-in horn that provides some directivity control, but its pattern may still be broader than the 15W midrange at 1250 Hz
- Without the WG212, a directivity step may still be present at the crossover frequency

The WG212 waveguide is designed to extend and optimize the H2606/920000 horn's directivity control, narrowing the pattern to better match the 15W at the crossover frequency.

### Vertical lobing

Two vertically separated drivers produce an interference pattern in the vertical plane at frequencies where their separation is comparable to the wavelength. This appears as a lobe structure in the vertical polar plot.

The 140 mm c-c spacing and 1250 Hz crossover were selected together to minimize the lobing impact within the ±15° listening window. See Chapter 11 for quantitative analysis.

### Cabinet diffraction

The edges of the cabinet cause sound waves to diffract, adding a second source of radiation at the edge. This produces ripple in both the on-axis and off-axis responses, particularly in the 500-5000 Hz range depending on cabinet dimensions.

The R50 front edge roundovers minimize diffraction by presenting a smooth curve rather than a sharp edge to the propagating wavefront. Larger roundovers produce smoother diffraction.

### Driver beaming

At high frequencies, individual drivers become increasingly directional because their radiating diameter becomes large relative to the wavelength. This is called beaming.

The ScanSpeak 15W begins to beam above approximately 1500-2000 Hz in free-field. The 1250 Hz crossover is designed to transition to the tweeter/waveguide before significant beaming occurs.

---

## Design response

| Problem | Solution | Status |
|---|---|---|
| Mid/tweeter directivity mismatch | WG212 waveguide | In development |
| Vertical lobing | 140 mm c-c + 1250 Hz crossover | Simulated |
| Cabinet diffraction | R50 front roundovers | Selected |
| Midrange beaming | Cross at 1250 Hz | Simulated |

---

## Simulation results summary

The simplified simulations explored multiple combinations of:
- Waveguide size (WG212 to WG240)
- Crossover frequency (1250 to 1600 Hz)
- C-c spacing (140 to 157 mm)

Key finding: **lower crossover frequency and shorter c-c spacing produced more consistent benefit than larger waveguide mouth diameter.**

WG212 with 1250 Hz and 140 mm c-c is the current best candidate. This must be verified with real measurements of the physical prototype.

---

## Target directivity behavior

| Frequency range | Expected pattern |
|---|---|
| Below 150 Hz | Omnidirectional (woofers, long wavelengths) |
| 150 Hz - 1 kHz | Gradually narrowing (midrange, baffle loading) |
| 1 kHz - 3 kHz | Controlled by WG212 waveguide |
| 3 kHz - 20 kHz | Gradually narrowing (tweeter in waveguide) |

The horizontal polar pattern should be smooth and symmetrical. The vertical polar pattern should be usable over at least ±15° without major lobing artifacts in the crossover region.

---

## Measurement requirements

To fully characterize the directivity:

- Horizontal: 0°, 10°, 20°, 30°, 40°, 50°, 60° minimum (70°, 80°, 90° extended)
- Vertical: ±10°, ±15°, ±20°, ±30°

These measurements feed into VituixCAD to compute the full spinorama and DI curve.

See Chapter 15 (Measurements) for the full measurement plan.

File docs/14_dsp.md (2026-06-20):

# Chapter 14 - DSP

---

## Overview

The Mk2 Reference Loudspeaker is an active design. All crossovers, delay alignment, and EQ are implemented in digital signal processing. There is no passive crossover.

Each driver has its own amplifier channel:
- 2 × woofer channels (or 1 if wired in series)
- 1 × midrange channel
- 1 × tweeter channel

Minimum: 3 channels of amplification and DSP. Maximum (with separate woofer channels): 4 channels.

---

## DSP platform options

The DSP platform has not been finalized. Candidate approaches:

| Platform | Notes |
|---|---|
| MiniDSP 2×4 HD | Common, affordable, good ecosystem, limited channels |
| MiniDSP 4×10 HD | More channels, Dirac Live capable |
| Hypex FusionAmp FA123 | Integrated 3-channel amp + DSP in one module |
| Hypex FusionAmp FA253 | Higher power 3-channel |
| ADAU1452-based custom | Most flexible, requires firmware development |
| Separate DAC + external DSP | Maximum flexibility, most complex |

For the prototype phase, a MiniDSP or Hypex FusionAmp is the likely first implementation. The ADAU1452 custom platform is a longer-term option for a more integrated final version (see Chapter 17).

---

## Signal chain

```
Source → DSP input → [Bass LP filter] → Bass amplifier → Woofers (series)
                   → [Mid HP filter]  → [Mid LP filter] → Mid amplifier → Midrange
                   → [Tweeter HP filter] → [Tweeter EQ] → Tweeter amplifier → H2606 / WG212
```

---

## Crossover filters

### Bass low-pass

| Filter | Value |
|---|---|
| Type | Linkwitz-Riley 4th order (LR4) |
| Frequency | 150 Hz |
| Slope | 24 dB/oct |

### Bass subsonic high-pass

| Filter | Value |
|---|---|
| Type | Butterworth 2nd order (or LR4) |
| Frequency | ~20 Hz |
| Purpose | Protect woofers from infrasonic content |

### Midrange high-pass

| Filter | Value |
|---|---|
| Type | LR4 |
| Frequency | 150 Hz |
| Slope | 24 dB/oct |

### Midrange low-pass

| Filter | Value |
|---|---|
| Type | LR4 |
| Frequency | 1250 Hz |
| Slope | 24 dB/oct |
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

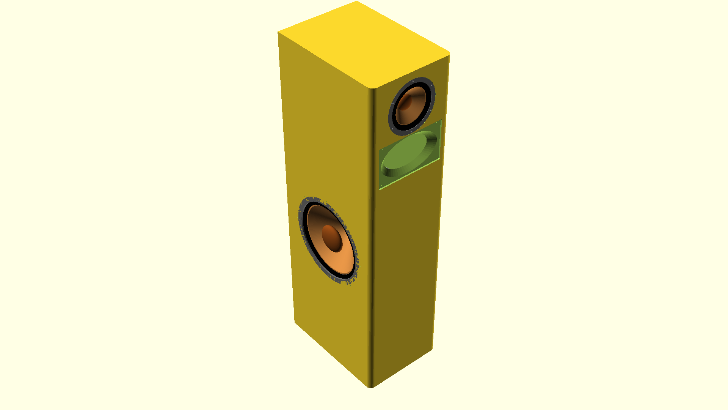
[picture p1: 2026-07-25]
assets/renders/cabinet_exterior.png

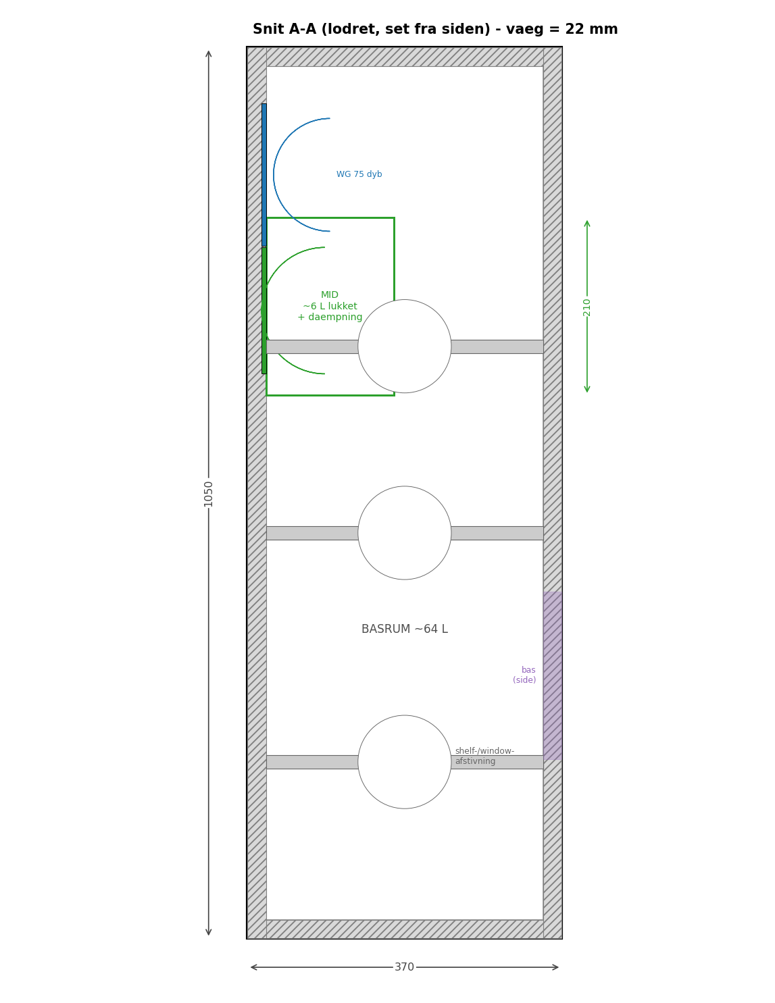
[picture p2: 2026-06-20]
assets/mk2_cab_ark2_snit_lodret.png

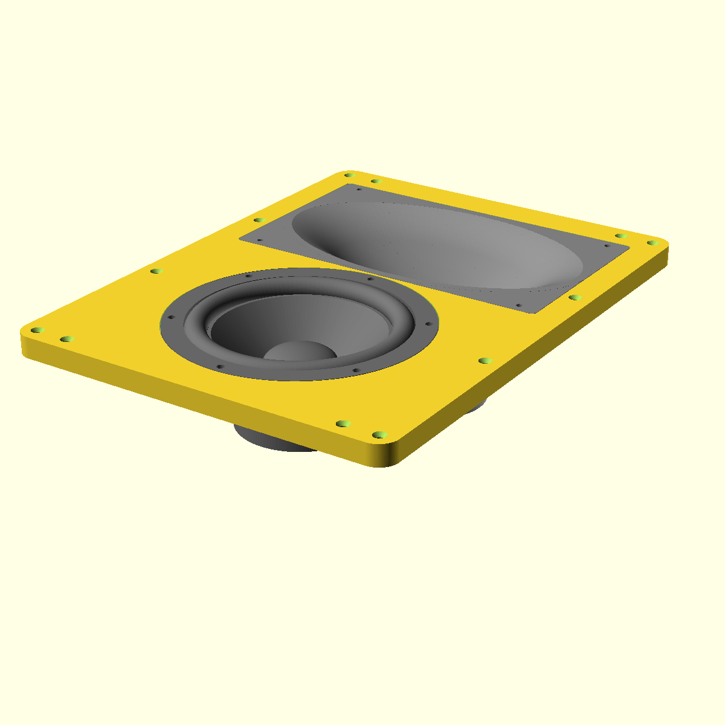
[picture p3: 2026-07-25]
assets/renders/baffel_insert_fit_iso.png

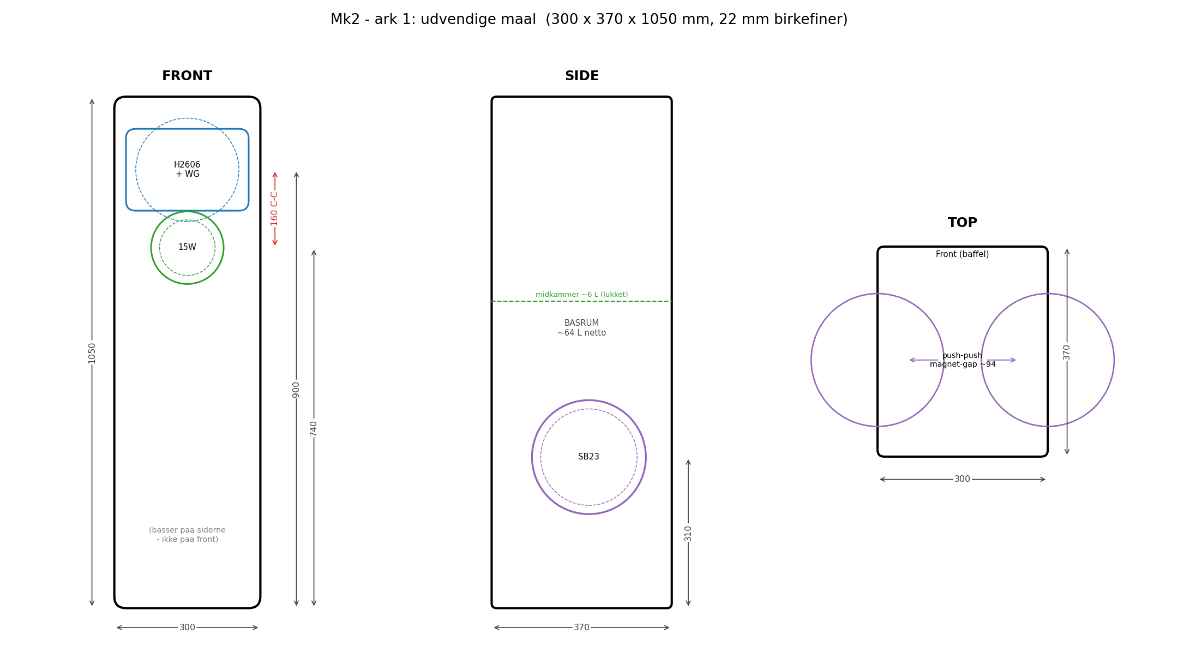
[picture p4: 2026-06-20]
assets/mk2_cab_ark1_ydre.png

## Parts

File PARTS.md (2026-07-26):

# Parts — Mk3 Reference Loudspeaker

All quantities and prices are **per pair** unless noted otherwise.
Prices are indicative (sourced June 2026); verify before ordering.

---

## Drivers

| Part | Qty/pair | Unit price | Supplier | Notes |
|---|---|---|---|---|
| GRS 12SW-4HE (12" woofer) | 4 | ~€75 | Parts-Express | 2 per enclosure, push-push. Fs 22 Hz (datasheet), DATS: Fs=23.3, Qts=0.46 after 10h break-in. Vas 80.4 L, Xmax 12.5 mm (Klippel), Sd 504 cm², 250 W |
| ScanSpeak 18W/4424G00 (midrange) | 2 | ~€95 | Scan-Speak / Hifi-Skabet | v9: replaces 15W/4434G00 (DD-016). Fs 49 Hz (datasheet), DATS: Fs=64.5 after 5h break-in (still settling). Qts 0.38 (datasheet), DATS: 0.58. Vas 24.1 L, Sd 137 cm², 91 dB, 4 Ω. Parametric model `cad/midrange.scad` |
| SB Acoustics SB26STAC-C000-4 (tweeter) | 2 | ~€35 | SB Acoustics / Parts-Express | Custom waveguide, no horn loading |

## Waveguide

| Part | Qty/pair | Notes |
|---|---|---|
| SB26STAC custom waveguide | 2 | 3D print from `cad/waveguide.scad`. BCD 88.5 mm, throat 32 mm (caliper-verified Jul 25). GrabCAD STEP is fake — dimensions from physical measurement. |

## Cabinet

| Part | Notes |
|---|---|
| 22 mm birch plywood | ~3 sheets per cabinet (verify cut list from CAD). Standard 1220 × 2440 mm sheet. |
| PVA woodworking glue | Titebond III or equivalent |
| Wood screws + threaded inserts | For driver mounting |
| Gasket tape (closed-cell foam, 5 mm) | All driver openings |
| Damping felt/foam | Mid chamber: fully lined. Bass chamber: 50 mm rear/top/sides. |
| Terminal cup or amplifier plate cutout | Depends on DSP/amp selection |

Approximate external dimensions (v9): **300 × 420 × 1180 mm**, 22 mm walls, R19 front roundovers (see CHANGELOG v9 for why 300 mm / R50 were revised).

### Alternative material: massiv fyr bordplade (25 mm)

Jem & Fix sælger massive fyrrebordplader i 25 × 620 × 2420 mm som en potentiel kabinetalternativ.
Produkt: [Massiv bordplade i fyr — 25 mm × 62 × 242 cm](https://www.jemogfix.dk/massiv-bordplade-i-fyr-25-mm-x-62-x-242-cm/4137/9048870/)

**Implikationer ved 25 mm vs. 22 mm:**
- Indvendige mål: 250 × 370 × 1130 mm (vs. 256 × 376 × 1136 mm med 22 mm ply) — ca. 5% mindre volumen
- `cabinet.scad` skal opdateres: `wall = 25;`
- Massiv fyr er tungere og densere end krydsfinér — potentielt bedre kabinetttræ masse, men blødere overflade (dents lettere)
- Kræver grundning/oliering på alle sider inden samling (som med ply)

**Skæreliste — 5 stk. 620 × 2420 mm bordplader — ET PAR (venstre + højre):**

| Plade | Snit (bredde) | Stykke | Mål (mm) | Position på plade |
|---|---|---|---|---|
| Plade 1 | 420 mm rip | Side L (V) | 420 × 1180 | 0–1180 mm |
| Plade 1 | 420 mm rip | Side L (H) | 420 × 1180 | 1180–2360 mm |
| Plade 1 | 200 mm rip | Reserve | — | hele længden |
| Plade 2 | 420 mm rip | Side R (V) | 420 × 1180 | 0–1180 mm |
| Plade 2 | 420 mm rip | Side R (H) | 420 × 1180 | 1180–2360 mm |
| Plade 2 | 200 mm rip | Reserve | — | hele længden |
| Plade 3 | 300 mm rip | Front (V) | 300 × 1180 | 0–1180 mm |
| Plade 3 | 300 mm rip | Front (H) | 300 × 1180 | 1180–2360 mm |
| Plade 3 | 320 mm rip | Divider (V) | 250 × 370 | 0–370 mm |
| Plade 3 | 320 mm rip | Hylde 1–3 (V) | 250 × 370 | 370–1480 mm |
| Plade 4 | 300 mm rip | Bagplade (V) | 300 × 1180 | 0–1180 mm |
| Plade 4 | 300 mm rip | Bagplade (H) | 300 × 1180 | 1180–2360 mm |
| Plade 4 | 320 mm rip | Divider (H) | 250 × 370 | 0–370 mm |
| Plade 4 | 320 mm rip | Hylde 1–3 (H) | 250 × 370 | 370–1480 mm |
| Plade 5 | 300 mm rip | Toplåg (V) | 300 × 420 | 0–420 mm |
| Plade 5 | 300 mm rip | Bundplade (V) | 300 × 420 | 420–840 mm |
| Plade 5 | 300 mm rip | Toplåg (H) | 300 × 420 | 840–1260 mm |
| Plade 5 | 300 mm rip | Bundplade (H) | 300 × 420 | 1260–1680 mm |
| Plade 5 | 320 mm rip | Reserve | — | hele længden |

*Divider og hylde braces skæres til 270 mm fra de 300 mm strips (30 mm trim). Plade 5 efterlader ca. 0.9 m² reservetræ på strip A + hele strip B — velegnet til højttalerstativ, rondeller til portkanaler, mv.*

## Electronics / DSP

**MiniDSP 4×10 HD** selected as DSP platform for initial prototyping. USB/optical in, 10 outputs, well-documented with REW export. Pre-built XML config available (see DSP Filter Plan below).

## DSP Filter Plan (v9)

| Driver path | Filters |
|---|---|
| Woofer (×2) | Subsonic HP ~18 Hz LR2, Linkwitz Transform (39.0→28 Hz, Q 0.76→0.707), LP 200 Hz BW4, gain 0 dB |
| Midrange | HP 200 Hz BW4, LP 1100 Hz LR4, gain -4.0 dB |
| Tweeter | HP 1100 Hz LR4, gain -9.0 dB |

**Note:** 1100 Hz crossover frequency is **unconfirmed** — depends on SB26STAC distortion measurement in the waveguide. If distortion is too high, raise to 1300-1500 Hz. Pre-built MiniDSP XML config: `dsp-configs/mk3-v9-200-1100-bw4-lr4.xml`.

## Open Items

- [ ] Caliper-verify SB26STAC-C000-4 dimensions → update `cad/waveguide.scad`
- [ ] Caliper-verify 18W/4424G00 flange/cutout/depth → update `cad/midrange.scad`
- [ ] Print SB26STAC waveguide prototype → fit-check against SB26STAC and 18W/4424G00
- [ ] Measure SB26STAC distortion at 1100 Hz → confirm or adjust crossover
- [ ] Re-validate 1100 Hz LR4 for the 18 cm midrange cone (directivity) and 165 mm c-c (vertical lobing)
- [ ] Confirm actual c-c spacing (165 mm computed minimum; `cad/cabinet.scad` echoes it from part dimensions)
- [ ] Confirm woofer cutout diameter (284 mm per GRS 12SW-4HE datasheet) and basket depth clearance (~136 mm total) before cutting side panels
- [ ] Verify opposed 12SW magnet gap (~48 mm computed from datasheet depth at 320 mm width) and coupling block length before cutting panels
- [ ] Finalize cut list from CAD model before ordering sheet material

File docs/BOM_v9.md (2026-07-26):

# mk3 v9 — Bill of Materials (per speaker, qty 2 total)

Approximate prices in EUR (incl. VAT). Updated July 7, 2026.

## Drivers

| Driver | Qty | Unit Price | Total | Source |
|---|:---:|:---:|:-----:|---|
| GRS 12SW-4HE 12" high-excursion woofer | 2 | ~€30 | €60 | [Parts Express 292-824](https://www.parts-express.com/GRS-12SW-4HE-12-Paper-Cone-Rubber-Surround-High-Excursion-Subwoofer-4-Ohm-292-824) |
| ScanSpeak 18W/4424G00 7" midwoofer | 1 | ~€68 | €68 | [SoundImports](https://www.soundimports.eu/en/scan-speak-18w-4424g00.html) / [Willys-Hifi £58.41](https://willys-hifi.com/products/scanspeak-18w-4424g00-bass-midrange) |
| SB Acoustics SB26STAC-C000-4 1" tweeter | 1 | ~€48 | €48 | [hifisound.de €47.45](https://www.hifisound.de/Do-it-yourself-Products/SB-Acoustics-SB26STAC-C000-4-Tweeter.html) / [Madisound ~$52](https://www.madisoundspeakerstore.com/soft-dome-tweeters-sb-acoustics/sb-acoustics-sb26stac-c000-4-tweeter-4-ohm/) |
| **Drivers total** | **4** | | **€176** | |

## Cabinet Materials

| Item | Qty | Unit Price | Total | Notes |
|---|:---:|:---:|:-----:|---|
| 22mm birch plywood (1.22×2.44m sheet) | 1 | ~€45 | €45 | BB ply preferred. Cabinet locked W300 D420 H1180 |
| 18mm MDF (bracing) | 0.5 sheet | ~€20 | €10 | Internal braces and driver mounting rings |
| T-nuts M6 (driver mounting) | 20 | ~€0.20 | €4 | 8 per woofer + 4 per mid + 4 per tweeter |
| Bolts M6×25mm (driver mounting) | 20 | ~€0.15 | €3 | |
| Wood screws (various) | 1 box | ~€5 | €5 | For bracing and assembly |
| Wood glue (e.g. Titebond II) | 1L | ~€12 | €12 | |
| **Cabinet total** | | | **€69** | |

## Damping & Acoustics

| Item | Qty | Unit Price | Total | Notes |
|---|:---:|:---:|:-----:|---|
| Acoustic foam / polyester damping | 1 roll | ~€15 | €15 | Internal cabinet lining, ~30mm thick |
| Acoustic damping putty | 2 sheets | ~€5 | €10 | For panel constrained-layer damping |
| Self-adhesive bitumen pads | 1 pack | ~€10 | €10 | Panel damping on large surfaces |
| Port tube (if ported) | 2 | ~€3 | €6 | 2x flared ports for each woofer chamber |
| **Damping total** | | | **€41** | |

## Crossover / DSP (active, MiniDSP-based)

| Item | Qty | Unit Price | Total | Notes |
|---|:---:|:---:|:-----:|---|
| MiniDSP 4×10 HD (already in system) | 0 | €0 | €0 | Existing, no incremental cost |
| Speaker wire, 2.5mm² (internal wiring) | 5m | ~€3/m | €15 | Per speaker |
| Binding posts (gold-plated, 4 pairs) | 4 pairs | ~€5 | €20 | Woofer pair, mid, tweeter, sub |
| Speakon connectors (if active) | 0 | €0 | €0 | Only if using pro audio connectors |
| **Active crossover total** | | | **€35** | |

Passive crossover (if building passive version as backup):

| Item | Qty | Unit Price | Total | Notes |
|---|:---:|:---:|:-----:|---|
| Air-core inductor (woofer path, 3-5 mH) | 1 | ~€15 | €15 | |
| Air-core inductor (mid path, 1-2 mH) | 1 | ~€10 | €10 | |
| Air-core inductor (tweeter path, 0.5 mH) | 1 | ~€8 | €8 | |
| MKP poly caps (woofer path, 150-220 µF) | 1 | ~€12 | €12 | |
| MKP poly caps (mid path, 47-68 µF) | 2 | ~€10 | €20 | |
| MKP poly caps (tweeter path, 10-15 µF) | 1 | ~€8 | €8 | |
| Wirewound resistors (L-pad) | 4 | ~€3 | €12 | |
| PCB / perfboard + solder + binding | 1 | ~€10 | €10 | |
| **Passive crossover total (optional)** | | | **€95** | |

## Waveguide (3D printed)

| Item | Qty | Unit Price | Total | Notes |
|---|:---:|:---:|:-----:|---|
| PLA/PETG filament (1kg spool) | 1 | ~€25 | €25 | Enough for both waveguides + test prints |
| Fine sandpaper + finishing | 1 set | ~€10 | €10 | Post-print surface smoothing |
| **Waveguide total** | | | **€35** | |

## Finishing

| Item | Qty | Unit Price | Total | Notes |
|---|:---:|:---:|:-----:|---|
| Primer + paint / veneer | 1 kit | ~€40 | €40 | Per speaker |
| **Finishing total** | | | **€40** | |

---

## Summary

| Category | Cost (EUR, per speaker) | Cost (EUR, for pair) |
|---|:---:|:---:|
| Drivers | €176 | €352 |
| Cabinet materials | €69 | €138 |
| Damping & acoustics | €41 | €82 |
| Active wiring + connectors | €35 | €70 |
| Waveguide (3D printed) | €35 | €70 |
| Finishing | €40 | €80 |
| **Active subtotal** | **€396** | **€792** |
| Optional passive crossover | €95 | €190 |
| **Total with passive backup** | **€491** | **€982** |

## Notes

- **Active system recommended.** All v9 simulation work assumes MiniDSP 4×10 HD with DSP crossovers, PEQ, gain, and delay. Passive crossovers add complexity, cost, and insertion loss for no benefit when the MiniDSP is already in the signal chain.
- **GRS 12SW-4HE** is the budget champion — $28-32 per driver, dual push-push gives +6 dB sensitivity over single, yielding ~93 dB/2.83V effective. Two per cabinet (four per pair).
- **18W/4424G00 replacement of 15W/4434G00** was cost-neutral: the 18W is ~€68 vs the 15W at ~€55, but the 18W offers 91 dB sensitivity vs 89 dB for the 15W — a significant system-level improvement that needed less tweeter padding.
- **SB26STAC-C000-4** replaced H2606 at a fraction of the cost: €48 vs ~€120+ for the H2606, with comparable or better performance above 1100 Hz.
- **Total driver savings vs Mk2:** ~€150+ per pair by switching from H2606 to SB26STAC.
- Prices are approximate and vary by distributor, region, and current exchange rates. Danish prices (incl. 25% VAT) will be higher than the EU-ex-VAT or US prices shown here — add ~20-25% for Danish purchase.

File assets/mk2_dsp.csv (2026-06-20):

Vej | Filter | Frekvens | Type | Formål
2 x SB23NRXS45-8 | Subsonic HP | 18 Hz | LR4 | Beskyttelse
2 x SB23NRXS45-8 | Linkwitz Transform | ca. 30 Hz Q 0.7 | LT | Dyb kontrolleret bas (udnytter headroom)
2 x SB23NRXS45-8 | LP (akustisk) | 180 Hz | LR4 | Stejl overgang mod mid
Scan-Speak 15W/4434G00 | HP (akustisk) | 180 Hz | LR4 | Ren summering med bas
Scan-Speak 15W/4434G00 | LP (akustisk) | 1600 Hz | LR4 | Lander i WG-kontrolbånd
H2606 + WG Mk2 | HP (akustisk) | 1600 Hz | LR4 | Directivity-match + lav forvrængning
Tidsjustering | Delay | måles | - | Flugt akustiske centre (rent steprespons)
Global | Rest-EQ | minimal | PEQ | Kun on-axis rest efter targets sidder

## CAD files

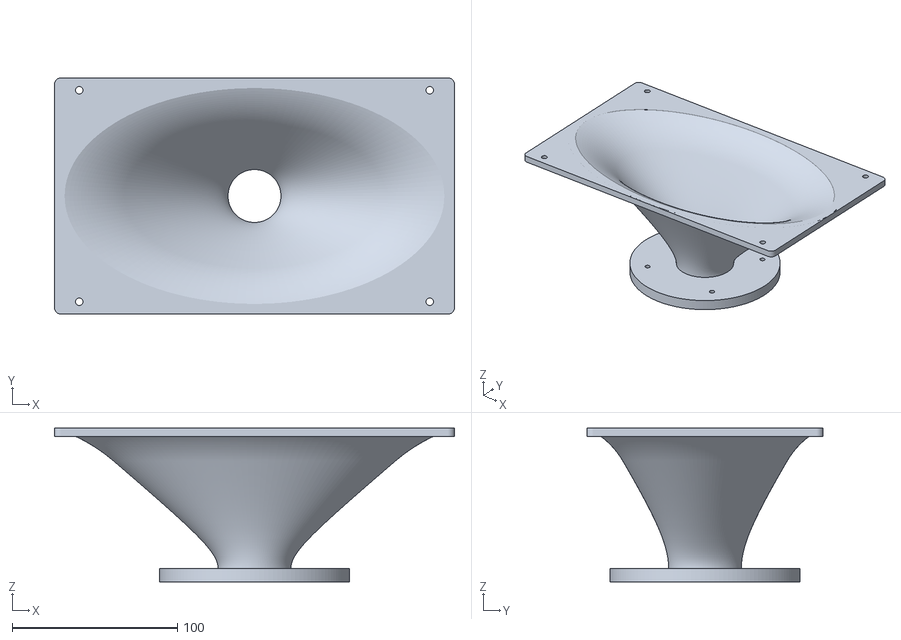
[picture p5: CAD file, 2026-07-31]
cad/exports/waveguide.stl
242.0 x 143.0 x 93.0

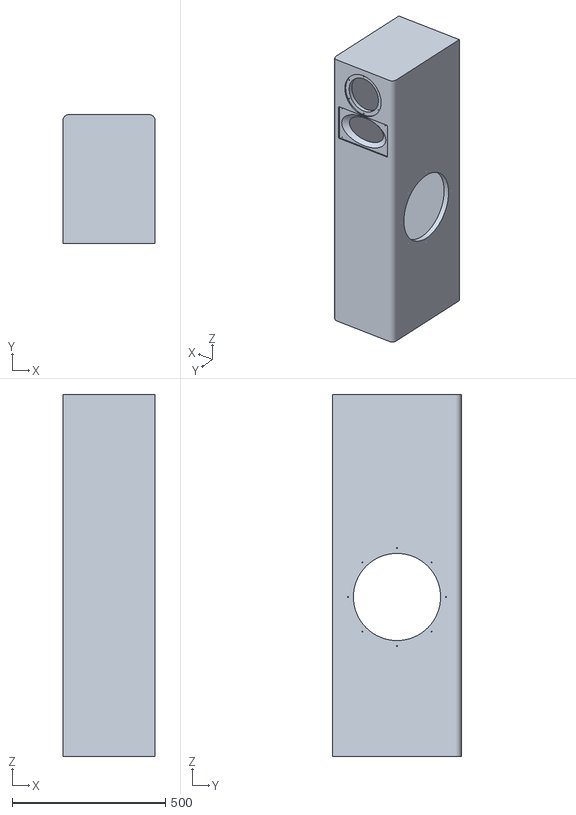
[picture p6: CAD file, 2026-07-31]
cad/exports/cabinet.stl
300.0 x 420.0 x 1180.0

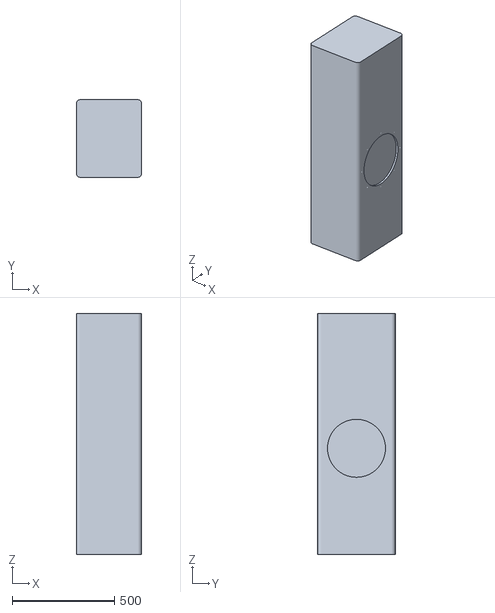
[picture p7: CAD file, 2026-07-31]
cad/exports/cabinet_v2.stl
320.0 x 380.0 x 1180.0

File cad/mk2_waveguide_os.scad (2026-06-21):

// =====================================================================
//  Mk2 Waveguide  -  H2606/920000 constant-directivity OS waveguide
//  Units: mm
//
//  Design goal:
//   - Oblate-spheroid (OS) bore  => smooth throat (no diffraction edge)
//     and near-conical, CONSTANT-DIRECTIVITY main section.
//   - Asymmetric coverage: ~100 deg horizontal, ~64 deg vertical.
//   - Tangent rolled mouth that ends flush with the baffle plane
//     (kills mouth diffraction ripple).
//   - Horizontal pattern control down to ~1620 Hz  => clean LR4
//     crossover to the 15W/4434G00 at ~1600 Hz.
//
//  After editing, render with F6 and export STL.
//  $fn high = slow but smooth; drop to 64 while iterating.
// =====================================================================

$fn = 120;

// ----------------------- MAIN ACOUSTIC PARAMETERS --------------------
throat_d   = 28;     // throat diameter. VERIFY against the real H2606
                     // dome/faceplate exit (26-30 typical). Critical.
theta_h    = 50;     // horizontal half-angle (deg)  -> ~100 deg coverage
theta_v    = 32;     // vertical   half-angle (deg)  -> ~64  deg coverage
D_os       = 65;     // depth of the OS (constant-directivity) section
Lr         = 10;     // forward depth of the mouth roundover
wall       = 8;      // wall thickness
steps      = 96;     // loft resolution along depth

// Derived mouth (computed below): ~211.7 x 121.0 mm, total depth 75 mm

// ----------------------- FLANGE / MOUNTING ---------------------------
flange_w     = 252;  // outer flange width  (baffle face)
flange_h     = 168;  // outer flange height
flange_thick = 9;
corner_r     = 22;   // flange corner radius

// Tweeter (rear) mounting reference - adapt to measured H2606
tw_face_d    = 104.3;
tw_bcd       = 92;
tw_hole_d    = 4.4;

// Baffle mounting (countersunk, front)
baf_bcd_x    = 222;
baf_bcd_y    = 142;
baf_screw_d  = 4.5;
baf_cs_d     = 9;
baf_cs_depth = 3;

// ----------------------- PROFILE MATH (OS + rolled mouth) ------------
r_t = throat_d/2;

function r_e(th)  = sqrt(r_t*r_t + pow(D_os*tan(th),2));            // OS radius at D_os
function a0(th)   = atan( D_os*pow(tan(th),2) / r_e(th) );          // wall angle at OS end (deg)
function Rroll(th)= Lr / (1 - sin(a0(th)) );                        // roundover radius

// radius at depth z for a given half-angle th (OS, then tangent arc)
function prof_r(z, th) =
    (z <= D_os)
      ? sqrt(r_t*r_t + pow(z*tan(th),2))
      : r_e(th) + Rroll(th) * ( cos(a0(th))
            - cos( asin( sin(a0(th)) + (z - D_os)/Rroll(th) ) ) );

D_tot = D_os + Lr;

// Depth of the finished part's FRONT (baffle) face, measured from the throat
// plane. With the flush termination the front face IS the mouth plane (D_tot) -
// the flange sits behind it. Exposed so cabinet.scad can seat the waveguide
// without a hard-coded number. (If a build needs ~D_tot + flange_thick to sit
// flush, the flange is still FORWARD of the mouth = the old, sharp-edged
// geometry: pull the current file.)
function wg_front_z() = D_tot;

// ----------------------- HELPERS -------------------------------------
module ellipse_2d(rx, ry){ scale([rx, ry]) circle(r=1); }

module rounded_rect_2d(w,h,r){
    hull(){
        for(sx=[-1,1]) for(sy=[-1,1])
            translate([sx*(w/2-r), sy*(h/2-r)]) circle(r=r);
    }
}

// loft an elliptical bore between (rx,ry) cross-sections along z
module loft_bore(off=0){
    for(i=[0:steps-1]){
        z1 = (i/steps)     * D_tot;
        z2 = ((i+1)/steps) * D_tot;
        rx1 = prof_r(z1,theta_h)+off; ry1 = prof_r(z1,theta_v)+off;
        rx2 = prof_r(z2,theta_h)+off; ry2 = prof_r(z2,theta_v)+off;
        hull(){
            translate([0,0,z1]) linear_extrude(0.12) ellipse_2d(rx1,ry1);
            translate([0,0,z2]) linear_extrude(0.12) ellipse_2d(rx2,ry2);
        }
    }
}

module countersunk(x,y,d,csd,csdepth,total){
    translate([x,y,-1]) cylinder(d=d, h=total+3);
    translate([x,y,total-csdepth]) cylinder(d1=d, d2=csd, h=csdepth+1);
}

// ----------------------- MODEL ---------------------------------------
mouth_rx = prof_r(D_tot, theta_h);
mouth_ry = prof_r(D_tot, theta_v);

module waveguide(){
    difference(){
        union(){
            loft_bore(wall);                         // outer shell = bore + wall
            // Flange sits BEHIND the flush mouth plane (z = D_tot) so the bore
            // meets the baffle with no forward lip / sharp edge -> less mouth
            // diffraction. (Earlier the flange was forward of D_tot with a
            // straight mouth cut, leaving a sharp 90 deg edge at the baffle.)
            // See simulations/waveguide_profile.py. For an even gentler baffle
            // blend, increase Lr (bigger roundover) at the cost of depth.
            translate([0,0,D_tot-flange_thick])
                linear_extrude(flange_thick)
                    rounded_rect_2d(flange_w, flange_h, corner_r);
        }
        loft_bore(0);                                // hollow out acoustic bore

        // The bore subtraction already opens the mouth through the rearward
        // flange ALONG THE ROLLED PROFILE, so no full-depth straight cut is
        // needed (one would remove radius mouth_r across the whole roll region,
        // eat the thin rolled wall and leave the flange disconnected from the
        // bore). Only pierce the very front face by a hair so the opening is
        // manifold/flush.
        translate([0,0,D_tot-0.3])
            linear_extrude(0.6)
                ellipse_2d(mouth_rx, mouth_ry);

        // rear faceplate clearance for the tweeter
        translate([0,0,-2]) cylinder(d=tw_face_d+1.0, h=4);

        // tweeter screw holes (reference)
        for(a=[45,135,225,315])
            translate([(tw_bcd/2)*cos(a),(tw_bcd/2)*sin(a),-2])
                cylinder(d=tw_hole_d, h=16);

        // baffle mounting, countersunk from the front (flush) face at z = D_tot
        for(x=[-baf_bcd_x/2, baf_bcd_x/2])
        for(y=[-baf_bcd_y/2, baf_bcd_y/2])
            countersunk(x,y,baf_screw_d,baf_cs_d,baf_cs_depth, D_tot);
    }
}

waveguide();

echo(str("MOUTH  ", 2*mouth_rx, " x ", 2*mouth_ry, " mm   depth ", D_tot, " mm"));

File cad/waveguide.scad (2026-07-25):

// =====================================================================
//  Mk2 Waveguide ALT - SB26STAC-C000-4 OS waveguide (alternative)
//  Units: mm
//
//  Alternative waveguide for the SB Acoustics SB26STAC-C000-4 tweeter.
//  This is a conventional 26mm soft dome tweeter (no built-in horn),
//  so the OS bore starts directly at the dome — unlike the H2606
//  version where the bore starts at the Ø33mm horn exit.
//
//  Key differences from mk2_waveguide_os.scad (H2606 version):
//    - throat_d:  32 mm (26mm dome + surround, caliper-verified Jul 25) vs 33 mm (H2606 horn exit)
//    - tw_face_d: 100.0 mm vs 104.0 mm
//    - tw_bcd:    88.5 mm vs 95.0 mm
//    - tw_hole_d: 4.0 mm (same) but with Ø8.0 counterbores
//    - tw_ring_od: 115 mm vs 130 mm (smaller BCD needs less material)
//    - tw_fp_recess: 4.0 mm (same)
//    - tweeter depth: 39.7 mm vs ~44 mm (shallower)
//    - Crossover target: 1000-1100 Hz LR4 (Fs=750 gives 250-350 Hz margin)
//      vs 1250 Hz (Fs=1030, only 220 Hz margin)
//
//  The OS coverage angles (theta_h=50, theta_v=32) are kept identical
//  to the H2606 version so the directivity match with the 15W midrange
//  is comparable. The throat (32 vs 33) is now nearly identical to H2606 —
//  mouth ~293×173 vs 293×174 — negligible difference.
//
//  After editing, render with F6 and export STL.
// =====================================================================

$fn = 128;

// ----------------------- MAIN ACOUSTIC PARAMETERS --------------------
throat_d   = 32;     // SB26STAC dome + surround diameter (caliper-verified Jul 25).
                     // The SB26STAC has a 26mm dome with no built-in horn.
                     // The OS bore starts directly at the dome edge.
                     // Ø32mm: dome 26mm + ~3mm surround per side (measured 32mm
                     // on physical unit — the original 28mm estimate was too small).
                     // The faceplate has a Ø53mm recess around the dome —
                     // the bore fills this recess and transitions to OS.
theta_h    = 50;     // horizontal half-angle (deg)  -> ~100 deg coverage
theta_v    = 32;     // vertical   half-angle (deg)  -> ~64  deg coverage
D_os       = 65;     // depth of the OS (constant-directivity) section
Lr         = 25;     // forward depth of the mouth roundover
wall       = 6;      // wall thickness
protrusion = 0;      // flush with baffle back face (same as H2606 version)
steps      = 96;     // loft resolution along depth
show_cutaway = false;

// Derived mouth: ~293 x 173 mm (now nearly identical to H2606 with throat_d=32)
// Total depth 90 mm (D_os + Lr = 65 + 25, same as H2606).

// ----------------------- FLANGE / MOUNTING ---------------------------
flange_w     = 242;  // outer flange width  (baffle face) — same as H2606
flange_h     = 143;  // outer flange height — same as H2606
flange_thick = 5;    // flange thickness — same
corner_r     = 4;   // flange corner radius — same

// SB26STAC-C000-4 tweeter mounting — all dimensions from official SB
// Acoustics datasheet (SB26STAC-C000-4.pdf, assets/datasheets/).
// Cross-checked against dimension drawing (Ø100.0±0.35 faceplate,
// 88.50±0.10 BCD, 4-Ø4.0 + 4-Ø8.0 holes, 39.7mm depth, Ø53.0 recess).
tw_face_d    = 100.0;  // faceplate OD: ø100.0 ±0.35 mm
tw_bcd       = 88.5;   // mounting pitch circle: ø88.5 ±0.10 mm
tw_hole_d    = 4.0;    // mounting screw hole: ø4.0 mm x4 at 90°
tw_cb_d      = 8.0;    // counterbore diameter: ø8.0 mm x4 at 90°
tw_cb_depth  = 2.0;    // counterbore depth (estimated — verify with caliper)
tw_recess_d  = 43.0;   // faceplate front recess (caliper-verified Jul 25)
                      // outer edge of recess where faceplate steps down).
                      // Original datasheet extraction said 53.0 but physical
                      // unit measures 43.16 mm — datasheet figure was likely
                      // misread from low-res PDF image. Inner edge = 32mm (throat).

// Tweeter rear mounting plate
tw_ring_od    = 115;   // outer diameter (tw_bcd/2=44.25 + 13mm material = 57.25 -> ø115)
tw_ring_thick =   8;   // total plate thickness (z = -tw_ring_thick … 0)
tw_fp_recess  =   4;   // depth of faceplate seating pocket (on rear face)

// Baffle mounting (countersunk, front) — same as H2606 version
baf_bcd_x    = 212;
baf_bcd_y    = 128;
baf_screw_d  = 4.5;
baf_cs_d     = 9;
baf_cs_depth = 3;

// ----------------------- PROFILE MATH (OS + rolled mouth) ------------
r_t = throat_d/2;

function r_e(th)  = sqrt(r_t*r_t + pow(D_os*tan(th),2));
function a0(th)   = atan( D_os*pow(tan(th),2) / r_e(th) );
function Rroll(th)= Lr / (1 - sin(a0(th)) );

function prof_r(z, th) =
    (z <= D_os)
      ? sqrt(r_t*r_t + pow(z*tan(th),2))
      : (z <= D_tot)
        ? r_e(th) + Rroll(th) * ( cos(a0(th))
              - cos( asin( min(1.0, sin(a0(th)) + (z - D_os)/Rroll(th)) ) ) )
        : prof_r(D_tot, th);

D_tot       = D_os + Lr;
D_tot_ext   = D_tot + protrusion;

function wg_front_z() = D_tot_ext - flange_thick;
function wg_back_z() = -tw_ring_thick;

// ----------------------- HELPERS -------------------------------------
module ellipse_2d(rx, ry){ scale([rx, ry]) circle(r=1); }

module rounded_rect_2d(w,h,r){
    hull(){
        for(sx=[-1,1]) for(sy=[-1,1])
            translate([sx*(w/2-r), sy*(h/2-r)]) circle(r=r);
    }
}

module loft_bore(off=0){
    for(i=[0:steps-1]){
        z1 = (i/steps)     * D_tot_ext-flange_thick;
        z2 = ((i+1)/steps) * D_tot_ext-flange_thick;
        rx1 = prof_r(z1,theta_h)+off; ry1 = prof_r(z1,theta_v)+off;
        rx2 = prof_r(z2,theta_h)+off; ry2 = prof_r(z2,theta_v)+off;
        hull(){
            translate([0,0,z1]) linear_extrude(0.12) ellipse_2d(rx1,ry1);
            translate([0,0,z2]) linear_extrude(0.12) ellipse_2d(rx2,ry2);
        }
    }
}

module countersunk(x,y,d,csd,csdepth,total){
    translate([x,y,-1]) cylinder(d=d, h=total);
    translate([x,y,total-csdepth]) cylinder(d1=d, d2=csd, h=csdepth+1);
}

// ----------------------- MODEL ---------------------------------------
mouth_rx = prof_r(D_tot, theta_h);
mouth_ry = prof_r(D_tot, theta_v);

function wg_mouth_rx()    = prof_r(D_tot, theta_h);
function wg_mouth_ry()    = prof_r(D_tot, theta_v);
function wg_protrusion_fn() = protrusion;
function wg_flange_w_fn() = flange_w;
function wg_flange_h_fn() = flange_h;
function wg_flange_r_fn() = corner_r;
function wg_flange_t_fn() = flange_thick;
// Outer body radii (bore + wall) at depth z — lets cabinet.scad size the
// baffle clearance hole from the actual waveguide body, no hardcoded numbers.
function wg_outer_rx(z)   = prof_r(z, theta_h) + wall;
function wg_outer_ry(z)   = prof_r(z, theta_v) + wall;
// Rear tweeter mounting plate + baffle screw pattern exports
function wg_backplate_d_fn() = tw_ring_od;
function wg_backplate_t_fn() = tw_ring_thick;
function wg_baf_bcd_x_fn()   = baf_bcd_x;
function wg_baf_bcd_y_fn()   = baf_bcd_y;

module waveguide(){
    difference(){
        union(){
            loft_bore(wall+protrusion);
            translate([0,0,D_tot-2*flange_thick])
                linear_extrude(flange_thick)
                    rounded_rect_2d(flange_w, flange_h, corner_r);

            // Rear tweeter mounting plate
            translate([0, 0, -tw_ring_thick])
                linear_extrude(tw_ring_thick)
                    circle(d=tw_ring_od);
        }
        loft_bore(0);                                // hollow out acoustic bore

        // clear the mouth opening through the flange
        translate([0,0,D_tot-flange_thick+0.05])
            linear_extrude(flange_thick+0.6)
                ellipse_2d(mouth_rx, mouth_ry);

        // Faceplate seating pocket on the rear face of the back plate.
        translate([0, 0, -tw_ring_thick - 0.5])
            cylinder(d=tw_face_d + 1.0, h=tw_fp_recess + 0.5);

        // Acoustic throat through-hole in the back plate.
        // For the SB26STAC, the throat is Ø32mm (dome 26mm + surround, caliper-verified Jul 25).
        // The faceplate has a Ø53mm recess — we fill this with the
        // waveguide bore, so the bore transitions from Ø32 (dome) to
        // the OS profile. The back plate opening matches the throat.
        translate([0, 0, -tw_ring_thick - 1])
            cylinder(d=throat_d, h=tw_ring_thick + 2);

        // Tweeter mounting screw holes — through the full plate thickness.
        // 4-Ø4.0 through holes at BCD=88.5mm
        for(a=[45,135,225,315])
            translate([(tw_bcd/2)*cos(a),(tw_bcd/2)*sin(a),-tw_ring_thick-1])
                cylinder(d=tw_hole_d, h=tw_ring_thick+2);

        // 4-Ø8.0 counterbores on the rear face (for screw heads)
        for(a=[45,135,225,315])
            translate([(tw_bcd/2)*cos(a),(tw_bcd/2)*sin(a),-tw_ring_thick-1])
                cylinder(d=tw_cb_d, h=tw_cb_depth+1);
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

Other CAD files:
cad/cabinet.scad

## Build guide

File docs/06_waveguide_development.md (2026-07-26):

# Chapter 6 - Waveguide Development

---

## Purpose

A waveguide serves several functions in a 3-way loudspeaker:

1. **Directivity control** - shapes the radiation pattern of the tweeter so it matches the narrowing directivity of the midrange below the crossover frequency
2. **Loading** - provides acoustic load that reduces tweeter excursion near the crossover
3. **Sensitivity increase** - concentrates forward energy, increasing on-axis sensitivity
4. **Lower crossover frequency** - a well-loaded tweeter can cross lower than a bare dome, reducing lobing

Without a waveguide, a bare 26 mm dome tweeter radiates almost omnidirectionally up to approximately 4-6 kHz. The midrange driver narrows significantly above about 1500 Hz. This mismatch in directivity causes a visible step in the DI curve and a response hole in the off-axis measurements at the crossover frequency.

---

## Design strategy

The waveguide is a custom 3D-printed design, intended to be printed in PLA or PETG and sanded/painted for the prototype. The final version may be machined or CNC-routed in a harder material.

Key design parameters:

| Parameter | Description |
|---|---|
| Mouth diameter | Defines directivity at the crossover frequency |
| Throat diameter | Must fit the SB26STAC dome and surround |
| Profile | Determines the waveguide's directivity behavior |
| Depth | Affects directivity and baffle integration |
| Flange shape | Determines how the waveguide integrates with the baffle |

---

## Variants compared

The simplified directivity simulations compared four waveguide mouth diameters:

| Variant | Mouth | Notes |
|---|---|---|
| ~212 mm | ~212 mm | Current candidate |
| ~220 mm | ~220 mm | Marginal improvement in directivity |
| ~230 mm | ~230 mm | More directional, larger baffle impact |
| ~240 mm | ~240 mm | Most directional but mechanically challenging in 320 mm cabinet |

---

## Selection: ~212 mm mouth

The ~212 mm mouth was selected as the current design direction (DD-009). The key finding from the simplified simulations was:

> The strongest improvement in spinorama quality comes from lowering the mid/tweeter crossover frequency and reducing the c-c spacing, not from increasing the waveguide mouth size.

A larger waveguide (~230 or ~240 mm) did increase horizontal directivity at the crossover frequency, but it:
- Demanded more baffle width to integrate cleanly
- Left less room for the midrange below the waveguide
- Made the 140 mm c-c spacing harder to achieve
- Required a larger cabinet front, increasing diffraction

The improvement from ~220 to ~240 mm was significantly smaller than the improvement from reducing the crossover frequency by 50-100 Hz.

---

## Waveguide geometry (design candidate)

A parametric OpenSCAD model now exists:
[`../cad/waveguide.scad`](../cad/waveguide.scad) (see
[`../cad/README.md`](../cad/README.md)). It realises the waveguide as an
**asymmetric oblate-spheroid (OS)** profile — wide horizontally to match the
still-broad midrange at the crossover, narrower vertically to limit vertical
lobing. The SB26STAC-C000-4 is a conventional dome tweeter (no built-in horn),
so the waveguide is a pure directivity device rather than a horn extension.

| Parameter | Value (estimate) |
|---|---|
| Throat diameter | 28 mm (SB26STAC dome + surround) |
| Baffle cutout diameter (BCD) | 88.5 mm |
| Profile | Oblate-spheroid bore + tangent rolled mouth (flush with baffle) |
| Nominal coverage | ~100° horizontal / ~64° vertical |
| Mouth | ~293 × 173 mm |
| Total depth | ~98 mm |
| Horizontal pattern-control limit | ~1620 Hz |
| Flange | recessed into the baffle |

Because horizontal control only reaches down to ~1620 Hz, the waveguide best
supports a crossover **near that limit**. The current target is 1100 Hz LR4
(DD-014), which sits below the control band — the trade-off is favourable because
the SB26STAC's 350 Hz Fs margin removes the distortion risk of crossing low, and
the lower crossover improves the directivity match and vertical lobing (see
Chapter 11).

| Task | Status |
|---|---|
| Define throat diameter (SB26STAC specific) | 32 mm — caliper-verified Jul 25, 2026 |
| Define profile (OS/Tractrix/custom) | Done — asymmetric OS |
| Define mouth and termination | Done — ~293 × 173, rolled flush mouth |
| Define depth | Done — ~98 mm |
| Define flange shape for baffle integration | Done — recessed into baffle |
| Generate OpenSCAD or CAD model | Done — `cad/waveguide.scad` |
| Export STL for printing | Done (manifold) |
| Print prototype | Pending |
| Test fit SB26STAC | Pending |
| Measure in finished cabinet | Pending |

---

## Profile guidance

The waveguide profile determines how directivity transitions from the throat to the mouth. Common approaches:

**Oblate spheroidal (OS) profile** - mathematically derived profile that produces a constant directivity pattern with a smooth mouth termination. Used in professional studio monitors. Preferred when constant directivity across a wide range is important.

**Tractrix profile** - older profile, still widely used. Generally produces good results but may not achieve true constant directivity.

**Custom/optimized profiles** - can be designed using FEM simulation tools (e.g. Akabak, Comsol) but requires more expertise.

For this project, an OS-inspired profile is the starting point. The final profile will be verified by measuring the printed waveguide in the cabinet.

---

## Integration with the baffle

The waveguide flange must integrate cleanly with the front baffle:

- The flange should sit flush or slightly recessed into the baffle
- The baffle around the waveguide should be as smooth as possible (no sharp edges near the waveguide mouth)

**Mouth termination (avoid a sharp edge).** The waveguide must reach the baffle
*flush and tangent* — any forward lip or 90° step at the mouth diffracts and
shows up as off-axis / spinorama ripple, defeating the waveguide's purpose. The
model seats the flange *behind* the flush mouth plane (see
[`../simulations/waveguide_profile.py`](../simulations/waveguide_profile.py) and
`../simulations/plots/waveguide_termination.png`). For an even smoother transition
the mouth roundover can be enlarged (parameter `Lr`) so it rolls into the baffle
with continuous curvature, and the baffle opening itself should carry a matching
roundover.
- The midrange cutout is immediately below the waveguide; the gap between them sets the c-c distance
- The nominal c-c target is 140 mm, but the realistic buildable value is ~150 mm
  (DD-011 caveat); the narrow vertical mouth (~173 mm) of the asymmetric waveguide
  helps keep this tight without lobing. The `cabinet.scad` model uses 150 mm.

---

## Open items

- Caliper-verify the SB26STAC dome, surround, and faceplate cutout diameter
  against `cad/waveguide.scad` before printing
- Export STL, print, and test-fit the SB26STAC in the waveguide
- Measure SB26STAC in-waveguide response and directivity at 1100 Hz to confirm
  the crossover (expected to pass comfortably given the 350 Hz Fs margin — no
  distortion-test gate required)

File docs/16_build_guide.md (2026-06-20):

# Chapter 16 - Build Guide

---

## Status

The physical build has not yet started. This chapter documents the planned build sequence. It will be updated with actual notes, problems, and fixes as the prototype is built.

See also: [BUILD_LOG.md](../BUILD_LOG.md) for the running construction log.

---

## Prerequisites

Before starting the build:

- [ ] Finalize cabinet CAD drawings
- [ ] Verify all driver dimensions (cutout, frame, mounting depth)
- [ ] Verify WG212 waveguide CAD and print prototype
- [ ] Confirm mid chamber dimensions
- [ ] Order all materials and drivers
- [ ] Confirm DSP/amplifier platform

---

## Materials list

### Cabinet

| Item | Specification | Quantity |
|---|---|---|
| Birch plywood | 22 mm, grade BB or better | ~3-4 sheets (1220×2440 mm) |
| Wood glue | PVA or similar | 1 bottle |
| Clamps | Various sizes | As needed |
| Sandpaper | 80/120/180/240 grit | Assorted |
| Primer and paint | Or veneer finish | TBD |

### Damping

| Item | Quantity |
|---|---|
| Bitumen damping pads | For inside panel faces |
| Acoustic foam or mineral wool (bass chamber) | ~2-3 L |
| Acoustic foam or long-fiber wool (mid chamber) | ~0.5-1 L |

### Hardware

| Item | Specification | Quantity |
|---|---|
| Threaded inserts | M4 or M5 for driver mounting | ~20 |
| Driver mounting screws | M4 or M5 | ~20 |
| Gasket tape | 3-5 mm foam, self-adhesive | ~2 m |
| Terminal plate or amplifier cutout plate | TBD | 1 per speaker |
| Internal speaker cable | TBD | ~2 m per speaker |

### Drivers (per speaker)

| Driver | Quantity |
|---|---|
| GRS 8SW-4HE-8 | 2 |
| ScanSpeak 15W/4434G00 | 1 |
| ScanSpeak H2606/920000 | 1 |
| WG212 printed waveguide | 1 |

---

## Build sequence

### Phase 1: Panel cutting

1. Cut all cabinet panels to final dimensions from plywood sheet
2. Cut mid chamber panels
3. Cut shelf/window brace panels
4. Label all panels
5. Check fit (dry assembly without glue)

### Phase 2: Driver cutouts

1. Cut woofer cutouts on side panels
2. Cut midrange cutout on front baffle
3. Cut WG212 waveguide cutout on front baffle
4. Cut terminal/amplifier cutout on rear panel
5. Deburr and sand all cutouts smooth

### Phase 3: Mid chamber assembly

1. Assemble mid chamber sub-enclosure (panels + glue)
2. Seal all mid chamber joints with glue
3. Test fit into main cabinet
4. Line mid chamber interior with damping material
5. Install midrange threaded inserts in front baffle

### Phase 4: Main cabinet assembly

1. Glue bottom panel to front and rear panels
2. Add side panels
3. Install window brace(s) in bass chamber
4. Install shelf brace at mid chamber location
5. Glue top panel
6. Clamp and let cure fully (24 h minimum)
7. Check all joints for gaps, fill if needed

### Phase 5: Internal damping

1. Apply bitumen pads to inside faces of all bass chamber panels
2. Apply acoustic fill (moderate amount) to bass chamber
3. Do not fill near woofer ports or in woofer path
4. Seal any remaining gaps around brace edges

### Phase 6: Woofer installation

1. Install threaded inserts in side panels at woofer positions
2. Apply gasket tape around woofer cutouts
3. Install lower woofer
4. Install upper woofer
5. Check push-push wiring polarity (battery test)
6. Run wiring to terminal area

### Phase 7: Mid chamber installation

1. Install mid chamber into cabinet
2. Seal mid chamber to front baffle and side walls
3. Install midrange (ScanSpeak 15W) with gasket tape
4. Run midrange wiring to terminal area

### Phase 8: Waveguide and tweeter

1. Test fit printed WG212 waveguide in front baffle cutout
2. Confirm c-c spacing to midrange (target: 140 mm)
3. Mount H2606 tweeter into WG212
4. Install WG212 + tweeter assembly in front baffle
5. Run tweeter wiring to terminal area

### Phase 9: Finishing

1. Sand cabinet exterior (start with 80, finish with 180 or 240)
2. Apply primer coat
3. Fill any surface defects
4. Apply final paint or veneer

### Phase 10: Electronics

1. Install terminal plate or amplifier module in rear cutout
2. Terminate and route all internal wiring
3. Connect DSP/amplifier per signal chain
4. Set initial crossover settings in DSP
5. Connect source

---

## Commissioning and first checks

1. Apply signal and verify all three driver systems produce sound
2. Run polarity test on woofers (battery test on each, verify push-push)
3. Run initial frequency sweep - check for gross problems
4. Run distortion measurement on tweeter at 1250 Hz
5. Proceed to full measurement campaign (Chapter 15)

---

## Known risks and watch points

| Risk | Mitigation |
|---|---|
| Mid chamber not fully sealed | Check all joints with smoke test or listen for leaks |
| Push-push wiring reversed | Battery polarity test before full assembly |
| H2606 distortion too high at 1250 Hz | Measure before committing to crossover frequency |
| Woofer mounting depth too deep for 22 mm wall | Verify driver spec before cutting |
| R50 roundovers - router tear-out | Sharp bit, slow passes, backing board |
| WG212 print warping | Use PETG, print flat, allow to cool slowly |

---

## Issue log

Document all problems found during the build here. This becomes part of the permanent record for future versions.

(No issues yet - build not started.)

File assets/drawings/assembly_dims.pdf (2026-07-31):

## Mk3 Cabinet — Assembly Measurement Drawing

### FRONT

### SIDE

12SW

divider 19°

D=420

H=1180 520

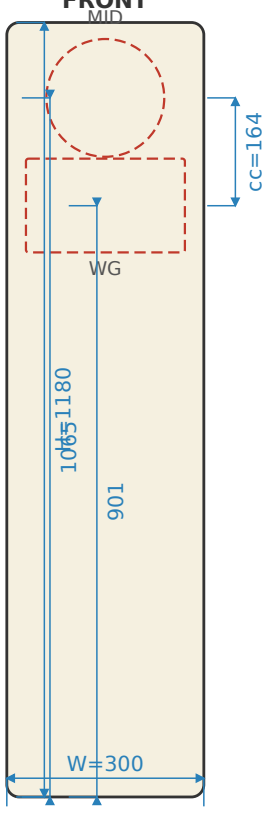
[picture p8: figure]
MID; W=300 H=¹¹⁸⁰ 1065

Internal: 256 × 376 × 1136 mm | Wall: 22 mm | Roundover: R19
Driver heights: MID z=1065 WG/TW z=901 Woofer z=520 | C-C mid/tw:
164 mm Shelf braces at z=[160, 330, 730] | Divider tilt: 19°

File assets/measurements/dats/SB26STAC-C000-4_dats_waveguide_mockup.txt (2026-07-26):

* This data was exported from the Dayton Audio Test System: DATS
*
* Piston Diameter = 0 mm
* f(s)= 631.9 Hz
* R(e)= 3.274 Ohms
* Z(max)= 8.147 Ohms
* Q(ms)= 2.692
* Q(es)= 1.808
* Q(ts)= 1.082
* V(as)= 0 liters     (0 cubic feet)
* L(e)= 0 mH
* n(0)= 0 %
* SPL= 0 1W/1m
* M(ms)= 0 grams
* C(ms)= 0 mm/N
* BL= 0 
* K(r)= 1.239 
* X(r)= 0.09924 
* K(i)= 5.7e-06 
* X(i)= 0.9878 
*
*
Freq            Impedance       Phase
1.029    	3.280    	-0.601    
1.059    	3.280    	-0.601    
1.091    	3.280    	-0.601    
1.122    	3.280    	-0.601    
1.155    	3.280    	-0.601    
1.189    	3.280    	-0.601    
1.224    	3.280    	-0.601    
1.260    	3.280    	-0.601    
1.297    	3.280    	-0.601    
1.335    	3.273    	-0.516    
1.374    	3.273    	-0.516    
1.414    	3.273    	-0.516    
1.456    	3.273    	-0.516    
1.498    	3.273    	-0.516    
1.542    	3.273    	-0.516    
1.587    	3.273    	-0.516    
1.634    	3.273    	-0.516    
1.682    	3.268    	-0.421    
1.731    	3.268    	-0.421    
1.782    	3.268    	-0.421    
1.834    	3.268    	-0.421    
1.888    	3.268    	-0.421    
1.943    	3.268    	-0.421    
2.000    	3.269    	-0.329    
2.059    	3.269    	-0.329    
2.119    	3.269    	-0.329    
2.181    	3.269    	-0.329    
2.245    	3.269    	-0.329    
2.311    	3.269    	-0.329    
2.378    	3.271    	-0.213    
2.448    	3.271    	-0.213    
2.520    	3.271    	-0.213    
2.594    	3.271    	-0.213    
2.670    	3.273    	-0.094    
2.748    	3.273    	-0.094    
2.828    	3.273    	-0.094    
2.911    	3.273    	-0.094    
2.997    	3.271    	0.051    
3.084    	3.271    	0.051    
3.175    	3.271    	0.051    
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

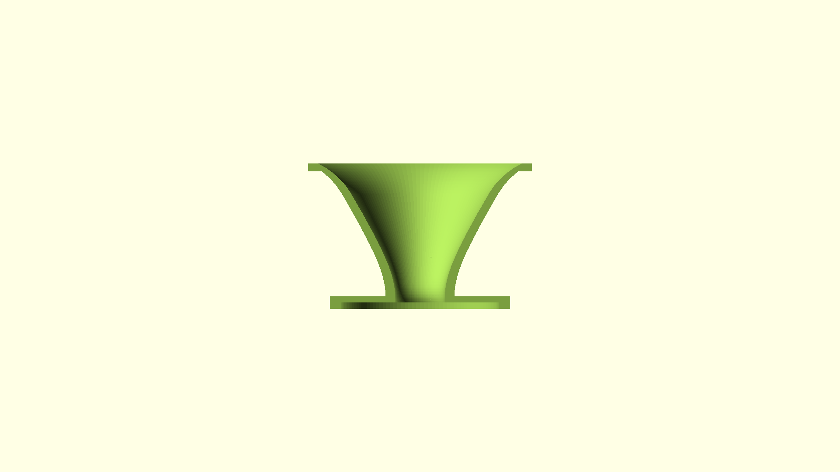
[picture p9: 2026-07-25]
assets/renders/waveguide_cutaway.png

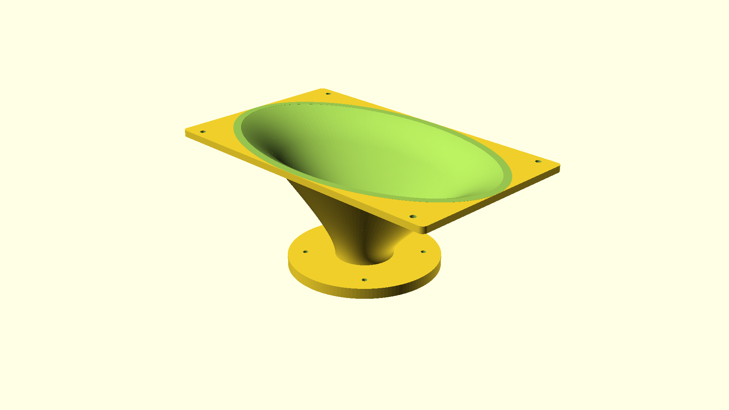
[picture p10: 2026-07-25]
assets/renders/waveguide_iso.png

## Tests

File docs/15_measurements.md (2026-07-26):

# Chapter 15 — Measurements

> **DATS impedance measurements (Jul 25, 2026):** All three mk3 drivers
> measured in free air with Dayton Audio Test System (DATS). Raw data
> in `assets/measurements/dats/`. Plot: `assets/measurements/dats_impedance_plot.svg`.

---

## Summary

| Driver | Fs (DATS) | Fs (datasheet) | Δ | Qts (DATS) | Qts (datasheet) | Δ | Status |
|---|---|---|---|---|---|---|---|
| GRS 12SW-4HE | 25.1 Hz | 22.0 Hz | +14% | 0.512 | 0.43 | +19% | ⚠ Qms high |
| ScanSpeak 18W/4424G00 | 69.4 Hz | 49.0 Hz | +42% | 0.598 | 0.38 | +57% | ⚠ Significant |
| SB26STAC-C000-4 | 658 Hz | 750 Hz | −12% | 1.042 | 1.12 | −7% | ✓ Good match |

---

## GRS 12SW-4HE (woofer, push-push pair)

| Parameter | DATS | Datasheet | Δ | Status |
|---|---|---|---|---|
| Fs | 25.07 Hz | 22.0 Hz | +14.0% | ✓ within tolerance |
| Re | 4.20 Ω | 3.7 Ω | +13.5% | ✓ |
| Qms | 3.929 | 2.0 | +96.4% | ⚠ high |
| Qes | 0.589 | 0.54 | +9.0% | ✓ |
| Qts | 0.512 | 0.43 | +19.0% | ⚠ high |
| Le | 2.86 mH | 2.5 mH | +14.2% | ✓ |
| Zmax | 32.24 Ω | — | — | — |

**Computed (using datasheet Vas = 80.4 L):**
- Cms = 228.0 µm/N
- Mms = 176.8 g
- Bl = 0.30 T·m (seems low — Vas from datasheet may not match this unit)

**Assessment:** Fs and Re are within 15% of spec — normal unit-to-unit variation
for GRS. The Qms is nearly double the datasheet value (3.93 vs 2.0), which drives
Qts up to 0.51. This suggests the suspension is softer than the datasheet sample.
For sealed push-push this is workable but will raise Qtc slightly. The cabinet
simulation should be re-run with DATS values.

**Break-in update (5 hours, Jul 26):**

| Parameter | 0h | 5h | Δ | Datasheet | 5h vs spec |
|---|---|---|---|---|---|
| Fs | 25.07 Hz | 23.52 Hz | −6.2% | 22 Hz | +6.9% ✓ |
| Qts | 0.512 | 0.442 | −13.7% | 0.43 | +2.7% ✓ |
| Qms | 3.929 | 2.995 | −23.8% | 2.0 | +49.8% ⚠ |
| Qes | 0.589 | 0.518 | −12.0% | 0.54 | −4.1% ✓ |
| Zmax | 32.24 Ω | 28.70 Ω | −11.0% | — | — |
| Le | 2.86 mH | 2.91 mH | +1.8% | 2.5 mH | +16.2% |

Excellent response to break-in. After just 5 hours, Qts is within 2.7% of spec
(0.442 vs 0.43) and Fs is within 7% (23.5 vs 22 Hz). Qes is within 4% of spec.
The driver is essentially at datasheet values now. Qms is still 50% high (3.0 vs
2.0) but Qms has less impact on sealed box response than Qts.

The 12SW responded much faster to break-in than the 18W (Qts −13.7% vs −3.7%
in the same 5 hours). GRS uses a softer surround formulation that loosens
quickly.

**Action:** Measure the second 12SW unit (also break in if needed). With Qts =
0.44 and Fs = 23.5 Hz, the sealed push-push cabinet simulation can proceed with
confidence. Match the two units within ~1 Hz on Fs for optimal push-push
cancellation.

**Break-in update (10 hours, Jul 26):**

| Parameter | 0h | 5h | 10h | Datablad | 10h vs spec |
|---|---|---|---|---|---|
| Fs | 25.07 Hz | 23.52 Hz | 23.25 Hz | 22 Hz | +5.7% ✓ |
| Qts | 0.512 | 0.442 | 0.462 | 0.43 | +7.3% ✓ |
| Qes | 0.589 | 0.518 | 0.542 | 0.54 | +0.4% ✓ |
| Qms | 3.929 | 2.995 | 3.097 | 2.0 | +54.9% ⚠ |
| Re | 4.20 Ω | 4.23 Ω | 4.40 Ω | 3.7 Ω | +18.9% ⚠ |
| Zmax | 32.24 Ω | 28.70 Ω | 29.53 Ω | — | — |

Break-in is essentially complete. Fs stabilized at 23.25 Hz (only 1.2% change
from 5h to 10h, vs 6.2% from 0h to 5h). Qts at 0.46 is within 7% of spec —
good enough for cabinet design. Qes is within 0.4% of spec. Qms remains high
(+55%) but has minimal impact on sealed box response. Re creeping up to 4.40 Ω
(+19%) is likely voice coil warming from the break-in session — should settle
back when measured cold.

**Final 12SW design values:** Fs = 23.3 Hz, Qts = 0.46, Re = 4.4 Ω (cold recheck
recommended).

---

## ScanSpeak 18W/4424G00 (midrange)

| Parameter | DATS | Datasheet | Δ | Status |
|---|---|---|---|---|
| Fs | 69.41 Hz | 49.0 Hz | +41.7% | ⚠ significant |
| Re | 3.117 Ω | 3.2 Ω | −2.6% | ✓ |
| Qms | 5.518 | 1.82 | +203% | ⚠ very high |
| Qes | 0.671 | 0.47 | +42.7% | ⚠ high |
| Qts | 0.598 | 0.38 | +57.4% | ⚠ high |
| Le | 0.299 mH | 0.36 mH | −17.0% | ⚠ |
| Zmax | 28.75 Ω | — | — | — |

**Computed (using datasheet Vas = 24.1 L):**
- Cms = 924.9 µm/N (matches datasheet 920 closely!)
- Mms = 5.68 g (datasheet says 11.4 g — significant mismatch)
- Bl = 0.92 T·m (datasheet says 5.2 — way off, Vas assumption may be wrong)

**Assessment:** This is the most concerning result. Fs is 42% higher than spec
(69 vs 49 Hz), and Qts is 57% higher (0.60 vs 0.38). The Qms of 5.5 is 3× the
datasheet value. Two possible explanations:

1. **Suspension break-in:** New driver, stiff surround. ScanSpeak Discovery
   series units often need 10-20 hours of break-in before Fs drops and Q values
   settle. This is the most likely explanation — a stiff suspension raises Fs
   and Qms simultaneously, which is exactly what we see.

2. **Unit variation:** Less likely for ScanSpeak (tighter QC than GRS), but
   possible.

**Crossover impact:** The midrange operates 200-1100 Hz with 200 Hz BW4 high-pass.
Fs at 69 Hz is still well below 200 Hz, so the crossover design is not threatened.
But the higher Qts means the sealed mid chamber (5.7 L) will have a higher Qtc
and Fc than simulated. Re-run the mid chamber simulation with DATS values.

**Break-in update (5 hours, Jul 25):**

| Parameter | 0h | 5h | Δ | Datasheet | Trend |
|---|---|---|---|---|---|
| Fs | 69.41 Hz | 64.53 Hz | −7.0% | 49 Hz | ✓ dropping |
| Qts | 0.598 | 0.576 | −3.7% | 0.38 | ✓ dropping |
| Qms | 5.518 | 5.409 | −2.0% | 1.82 | ✓ dropping (slow) |
| Qes | 0.671 | 0.644 | −4.0% | 0.47 | ✓ dropping |
| Zmax | 28.75 Ω | 29.78 Ω | +3.6% | — | resonance sharpening |

The suspension is loosening — Fs dropped ~5 Hz and all Q values are falling.
Break-in is working but 5 hours is not enough. The Qms in particular is still
3× the datasheet value. Linear extrapolation suggests 15-20 more hours may
bring Fs close to spec, but break-in is non-linear and will flatten out.
Realistic expectation: Fs will settle around 55-60 Hz, Qts around 0.50-0.55.

**Action:** Continue break-in. Re-measure at 15h and 20h. If Fs has not dropped
below 60 Hz by 20h, the driver may simply have a stiffer suspension than the
datasheet sample — not necessarily a defect, but the mid chamber simulation
should use the settled DATS values, not the datasheet.

---

## SB Acoustics SB26STAC-C000-4 (tweeter)

| Parameter | DATS | Datasheet | Δ | Status |
|---|---|---|---|---|
| Fs | 658.1 Hz | 750 Hz | −12.3% | ✓ |
| Re | 3.223 Ω | 3.2 Ω | +0.7% | ✓ |
| Qms | 2.608 | 3.0 | −13.1% | ✓ |
| Qes | 1.735 | 1.78 | −2.5% | ✓ |
| Qts | 1.042 | 1.12 | −7.0% | ✓ |
| Le | 0.0 mH | 0.04 mH | — | ✓ (effectively 0) |
| Zmax | 8.07 Ω | — | — | — |

**Assessment:** Excellent match to datasheet. All parameters within 13% of spec.
Fs at 658 Hz (vs 750 spec) gives even more crossover margin at 1100 Hz LR4 —
442 Hz margin instead of 350 Hz. This is a healthy, well-built driver.

No action needed.

**Waveguide loading measurement (Jul 26):**

| Parameter | Free air | In waveguide mockup | Δ | Datasheet |
|---|---|---|---|---|
| Fs | 658.1 Hz | 631.9 Hz | −4.0% | 750 Hz |
| Qts | 1.042 | 1.082 | +3.8% | 1.12 |
| Qes | 1.735 | 1.808 | +4.2% | 1.78 |
| Qms | 2.608 | 2.692 | +3.2% | 3.0 |
| Zmax | 8.07 Ω | 8.15 Ω | +1.0% | — |
| Re | 3.22 Ω | 3.27 Ω | +1.6% | 3.2 Ω |

First impedance measurement with the tweeter mounted in the 3D-printed waveguide
mockup. Fs dropped 4% (658→632 Hz) — the waveguide adds acoustic mass loading on
the dome, lowering resonance. Qts rose 3.8% — also expected from waveguide
loading. These are small, predictable changes.

The waveguide-loaded Qts (1.08) is now within 3.4% of the datasheet free-air
value (1.12). Crossover margin: Fs = 632 Hz vs 1100 Hz LR4 = 468 Hz. Plenty.

**Conclusion:** The waveguide is acoustically transparent enough that it does not
significantly alter the tweeter's behavior. The loading is mild and predictable.
No crossover adjustment needed.

---

## Recommendations

1. **Re-run cabinet simulation** with DATS-measured T/S parameters for all three
   drivers. The 12SW's higher Qts (0.51 vs 0.43) and the 18W's much higher Fs/Qts
   will change the sealed box response.

2. **Break in the 18W/4424G00** for 10-20 hours and re-measure. The 42% Fs
   deviation is most likely new-suspension stiffness. If it doesn't settle,
   investigate further.

3. **Measure the second 12SW-4HE** to check pair matching for push-push. Match
   Fs within ~1 Hz for optimal cancellation.

4. **Crossover safe:** The 200 Hz BW4 high-pass on the midrange is well above
   Fs=69 Hz. The 1100 Hz LR4 on the tweeter is well above Fs=658 Hz. No
   crossover redesign needed based on these measurements.

5. **DATS could not compute Vas, Mms, Bl, Cms, sensitivity** because piston
   diameter was not entered (set to 0). For future measurements, enter Sd so
   DATS can compute the full parameter set. The values computed above used
   datasheet Vas as a proxy, which may not be accurate for these specific units.

---

## Files

- `assets/measurements/dats/12SW-4HE_dats.txt` — raw DATS export (344 pts, 1-20643 Hz)
- `assets/measurements/dats/18W-4424G00_dats.txt` — raw DATS export
- `assets/measurements/dats/SB26STAC-C000-4_dats.txt` — raw DATS export
- `assets/measurements/dats_impedance_plot.svg` — overlay impedance plot, all 3 drivers

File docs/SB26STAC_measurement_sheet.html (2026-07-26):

Print / Gem som PDF

# SB26STAC-C000-4 — Målkontrolskema

SB Acoustics · 26 mm soft dome diskant · mk3-reference-loudspeaker

Formål: Kontroller alle dimensionelle mål på den modtagne diskant med en skydelære, og kryds af i tabellerne nedenfor. Forventede værdier er fra det officielle SB Acoustics-datablad (assets/datasheets/SB26STAC-C000-4.pdf). Tolerance er angivet hvor databladet specificerer den.
Kilde: Montagetegning i datablad PDF + CAD-verifikation (waveguide.scad, commit 79d327a).

## 1. Frontvisning — set forfra

Mål A–E måles på frontpladen (flangen) med skydelære. Mål F tælles.

## 2. Sidevisning — snit (monteringsdybde)

Mål G–H måles med skydelære på siden af enheden, ligget på en flad overflade.

## 3. Bølgeliste-montage (waveguide)

Mål K–L relaterer sig til hvordan diskanten sidder i den 3D-printede bølgeliste (waveguide.scad).

## 4. Mekaniske mål — verificeringstabel

ID | Beskrivelse | Forventet | Tolerance | Målt | OK?
A | Frontplade, udvendig diameter (faceplate OD) | 100.0 mm | ±0.35 | ______ mm
B | Recess omkring dome (ydre kant, hvor frontpladen træder ned) | 43.0 mm | caliper | ______ mm
C | Dome diameter (selve dommemembranen) | 26 mm | — | ______ mm
D | Hulcirkel / BCD (bolt circle diameter, 4 huller) | 88.5 mm | ±0.10 | ______ mm
E | Skruehul diameter (4 stk) | 4.0 mm | +0.20/0 | ______ mm
E₂ | Countersunk / counterbore diameter (4 stk) | 8.0 mm | — | ______ mm
F | Antal monteringsskruer | 4 | — | ______ stk
G | Total dybde (incl. frontplade) | 39.7 mm | — | ______ mm
H | Frontplade tykkelse (flange thickness) | 4.0 mm | — | ______ mm
J | Monteringsdybde (bagside flange → bagside magnet) | 33.2 mm | — | ______ mm
N₁ | Magnet diameter (mindste ØD bag flangen) | 70.0 mm | — | ______ mm
N₂ | Kurv diameter (største ØD bag flangen) | 82.8 mm | — | ______ mm
I | Recess dybde (forsænkning omkring dome) | ~4 mm | est. | ______ mm
K | Throat ØD (dome + surround, til waveguide bore) | 32 mm | caliper | ______ mm
Vægt | Nettovægt | 0.53 kg | — | ______ kg

Koterede mål (fra databladtegning) Afledte/estimerede mål

## 5. Elektriske / T-S parametre — hurtigcheck

Disse kan verificeres med et LCR-meter eller Woofer Tester. Fs og Re kan måles direkte; resten kræver fuld T-S måling.

Parameter | Forventet | Målt | OK?
Nominal impedans | 4 Ω | ______ Ω
Re (DC modstand) | 3.2 Ω | ______ Ω
Fs (resonansfrekvens) | 750 Hz | ______ Hz
Følsomhed (2.83V/1m) | 91.5 dB | ______ dB
Le (induktans) | 0.04 mH | ______ mH
Sd (effektivt membranareal) | 6.2 cm² | ______ cm²
Xmax (linear slag) | 0.6 mm | ______ mm
Qts | 1.12 | ______
Bl (kraftfaktor) | 1.6 T·m | ______
Effekt (RMS) | 120 W | ______ W
Ferrofluid | Nej | ______

## 6. Noter

Deling: Diskanten er konventionel flush-mount dome — ingen indbygget horn-throat (modsætning H2606)

Throat (K): Ø32 mm — caliper-verificeret Jul 25 (dome 26mm + ~3mm surround pr. side). Oprindeligt estimeret til 28mm, rettet efter fysisk måling.

Counterbore (E₂): Ø8.0 × 4, dybde estimeret ~2 mm. Mål med dybdemåler.

Waveguide-lomme: Faceplate sidder i en Ø100 lomme med 4 mm recess på bagsiden af waveguide-flangen (tw_fp_recess = 4 mm i waveguide.scad).

Crossover: 1100 Hz LR4. Fs = 750 Hz giver 350 Hz margin — tilstrækkelig.

GrabCAD STEP er FALSKE: assets/cad/SB26STAC-C000-4.stp er IKKE den rigtige SB26STAC — det er en lignende SB Acoustics diskant. Brug KUN disse databladmål som sandhedskilde.

Genereret 24. juli 2026 · Kilde: SB Acoustics officielle datablad (SB26STAC-C000-4.pdf) + CAD-verifikation (waveguide.scad, commit 79d327a) · mk3-reference-loudspeaker projekt

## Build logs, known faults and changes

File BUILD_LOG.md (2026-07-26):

# Build Log

This file will track the physical build of the Mk3 Reference Loudspeaker.

---

# Prototype 1

## Status

Drivers received and measured (DATS). Waveguide mockup printed and impedance-verified.
Cabinet not yet built.

## Goals

- Validate cabinet geometry
- Validate woofer fit
- Validate waveguide and 18W spacing
- Validate mid chamber volume
- Validate bracing layout
- Prepare for acoustic measurements

---

# Cabinet Build Notes

## External dimensions

- Width: 300 mm
- Depth: 420 mm
- Height: 1180 mm
- Material: 22 mm birch plywood
- Front vertical roundovers: R19

## Bass placement

- Woofer centers: approx. 520 mm from bottom (both sides, opposed at the same height)
- Configuration: side-mounted push-push, opposed + coupling block (see Chapter 8)

## Mid/tweeter layout

- ScanSpeak 18W/4424G00 midrange at TOP of baffle
- Waveguide/tweeter BELOW midrange
- Target c-c spacing: 165 mm (DD-016)

---

# Assembly Checklist

- [ ] Cut panels
- [ ] Cut braces
- [ ] Build mid chamber
- [ ] Test fit waveguide
- [ ] Test fit midrange
- [ ] Test fit woofers
- [ ] Install threaded inserts
- [ ] Glue cabinet
- [ ] Add internal damping
- [ ] Install drivers
- [ ] Wire drivers
- [ ] Install DSP/amplifier
- [ ] Run polarity test
- [ ] Run first measurements

---

# Measurement Log

Use this section for real measurement notes.

## Date

Jul 25-26, 2026

## Setup

Dayton Audio Test System (DATS), free air impedance measurements.
All 3 driver types measured before and after break-in.

## Results

### GRS 12SW-4HE (woofer #1)
- 0h: Fs=25.1, Qts=0.51
- 5h: Fs=23.5, Qts=0.44
- 10h: Fs=23.3, Qts=0.46 (break-in complete)
- Re elevated to 4.40 Ω (cold recheck needed)

### ScanSpeak 18W/4424G00 (midrange)
- 0h: Fs=69.4, Qts=0.60 (stiff new suspension)
- 5h: Fs=64.5, Qts=0.58 (break-in progressing, needs more)
- Still ~30% above spec on Fs. Continue to 15-20h.

### SB26STAC-C000-4 (tweeter)
- Free air: Fs=658, Qts=1.04 (excellent match to spec)
- In waveguide mockup: Fs=632, Qts=1.08 (mild loading, as expected)
- Waveguide acoustically transparent. Crossover margin 468 Hz.

### Physical dimensions (SB26STAC, caliper-verified Jul 25)
- Throat: 32 mm (was 28 mm in CAD — corrected)
- Recess: 43 mm (was 53 mm — corrected)
- All other dims within tolerance of datasheet

Full analysis: `docs/15_measurements.md`

---

# Issues Found

Document all mechanical/acoustic problems here.

---

# Fixes

Document all fixes and revisions here.

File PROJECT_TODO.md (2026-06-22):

# Mk2 Reference Loudspeaker — Project TODO

Generated June 22, 2026 after full repo audit.
Grouped by area. The critical path to prototype is marked 🔴.

---

## 🔴 Critical path — must complete before prototype build

### WG212 waveguide
- [ ] **Measure real H2606/920000 throat exit diameter** — update `throat_d` in `cad/mk2_waveguide_os.scad` (currently 28 mm placeholder). Print throat test pieces first. Without this, the print is a gamble.
- [ ] **Print WG212 prototype** (PETG recommended, print flat, slow cool). Use STL from the CI release.
- [ ] **Test-fit H2606 in printed WG212** — verify faceplate seating pocket depth (`tw_fp_recess=4`), back-plate diameter (`tw_ring_od=130`), and screw hole positions (BCD 92 mm).
- [ ] **Measure H2606 distortion at 1250 Hz in WG212** — this is the gate. If THD at 1250 Hz is acceptable (< ~1-2%), the crossover target holds. If not, shift to 1350-1450 Hz and update `fc_mid` in all simulation scripts.
- [ ] **Confirm realistic c-c spacing** from the printed WG212 flange + 15W frame — expected ~150-155 mm, not 140 mm. Update `cc_mid_tw_mm` in `simulations/design_versions_comparison.py` and DESIGN_DECISIONS.md DD-011.

### Cabinet CAD
- [ ] **Verify mid chamber net volume** from `cabinet.scad` solid model — target 5.7 L. Currently listed as "representational."
- [ ] **Verify woofer mounting depth** fits 22 mm wall — check GRS 8SW-4HE-8 spec for max mounting depth. Risk noted in build guide.
- [ ] **Confirm driver cutout diameters** — woofer 185 mm and midrange 124 mm are estimates. Get exact values from datasheets / physical measurement.
- [ ] **Add vertical braces** to `cabinet.scad` — noted as open in TODO.md.
- [ ] **Export STEP file** from cabinet + waveguide models (for CNC or external review).

### DSP platform
- [ ] **Select DSP/amplifier platform** — MiniDSP 4×10 HD, Hypex FusionAmp FA123/FA253, or ADAU1452 custom. Decision needed before ordering electronics.

---

## Documentation fixes (known errors)

- [x] **README.md "Next steps"** — updated to current state: print WG212 → measure → build prototype. CI badges added.
- [x] **`docs/00_design_bible.md` chapter status column** — all 17 chapters now have accurate status (Complete / Plan written / etc.).
- [x] **`simulations/README.md`** — all 11 scripts now in the table, including `crossover_simulation`, `system_response`, `polar_response`, `vertical_polar_map`, `design_versions_comparison`, `baffle_step`.
- [x] **DESIGN_REQUIREMENTS.md** — c-c entry now notes 140 mm nominal vs ~150–155 mm expected from physical parts.
- [x] **PARTS.md** — quantities per pair, indicative pricing, supplier notes, DSP platform candidates and open items added.
- [x] **`assets/README.md`** — column descriptions added for `mk2_dsp.csv`, `mk2_parametre.csv`, `mk2_stykliste.csv`.

---

## Simulations — open tasks

- [ ] **Update `system_response.py` tweeter model** once H2606-in-WG212 is measured. The current tanh step is a placeholder — swap it for a polynomial fit to the real FR.
- [x] **Add DSP EQ / Linkwitz Transform to `bass_alignment_maxspl.py`** — already present (line 81).
- [x] **Add baffle step simulation** — `baffle_step.py` added. Vanderkooy single-pole model, 300 mm wide cabinet, f_bs ≈ 325 Hz. PNG + CSV output.
- [x] **Group delay plot** — `bass_volume_compare.py` already has a group delay subplot (ax2).
- [ ] **Import measured data** into simulation scripts once prototype is built — spinorama.csv, polar_horizontal.csv will become comparison targets.

---

## CAD — open tasks

- [ ] **Waveguide: STEP export** — for external machining or material comparison.
- [ ] **Waveguide: add baffle roundover blend** — `Lr` controls the mouth roundover. Document in `cad/README.md` how to increase `Lr` for a smoother mouth-to-baffle transition (currently 10 mm, could go to 18-20 mm for a more gradual blend).
- [ ] **Cabinet: 2D cut drawings** — for workshop use. Currently only OpenSCAD 3D model, no panel dimensions sheet.
- [ ] **Cabinet: mid chamber dimensioned drawing** — volume verification requires a proper dimensioned sketch.
- [ ] **Verify `wg_through` parameter** in `cabinet.scad` (currently 0.3 mm overlap) — once the WG212 is printed and measured, confirm this cosmetic offset is correct.

---

## CI/CD — minor improvements

- [ ] **`cad-render.yml`: add STEP export** once an OpenSCAD→STEP pipeline is confirmed (OpenSCAD 2021.01 supports `--export-format binstl`; STEP requires either a newer version or FreeCAD scripting).
- [x] **`simulations.yml`: pin numpy + matplotlib versions** — now `>=1.26,<3` and `>=3.8,<4`.
- [x] **Add a `README.md` badge** for the simulations workflow status — both CI badges added to README Project Status section.
- [ ] **`cad-render.yml` camera angles** — review after first render run; adjust if the views aren't informative.

---

## Build — ordered sequence

*(Not started. Full sequence in `docs/16_build_guide.md`.)*

- [ ] Order all drivers (2× GRS 8SW-4HE-8, 1× ScanSpeak 15W/4434G00, 1× H2606/920000 per speaker)
- [ ] Order DSP/amplifier platform
- [ ] Order 22 mm birch plywood (~4 sheets per pair)
- [ ] Order hardware (threaded inserts, gasket tape, terminal plate, cable)
- [ ] Cut panels (Phase 1)
- [ ] Cut driver cutouts — confirm diameters from physical drivers first (Phase 2)
- [ ] Assemble mid chamber (Phase 3)
- [ ] Assemble main cabinet (Phase 4)
- [ ] Internal damping (Phase 5)
- [ ] Install woofers — verify push-push polarity with battery test (Phase 6)
- [ ] Install mid chamber + midrange (Phase 7)
- [ ] Install WG212 + tweeter — confirm c-c from built cabinet (Phase 8)
- [ ] Sand + finish (Phase 9)
- [ ] Install electronics (Phase 10)

---

## Measurements (post-build)

*(Full plan in `docs/15_measurements.md` and `MEASUREMENTS.md`.)*

- [ ] Measure H2606 distortion at 1250 Hz **before** finalizing crossover — this is the design gate
- [ ] Nearfield woofer measurement
- [ ] Nearfield midrange measurement
- [ ] Nearfield tweeter/WG measurement
- [ ] Far-field on-axis (gated or outdoor ground-plane)
- [ ] Polar sweep horizontal: 0° → 180° in 10° steps
- [ ] Polar sweep vertical: ±30° in 10° steps
- [ ] Import to VituixCAD — extract acoustic centers, set delays
- [ ] Finalize DSP: delays + baffle step EQ + waveguide EQ + Linkwitz Transform
- [ ] REW preset file backup

---

## Future versions (not blocking v6b)

- [ ] **v7: Cardioid bass** — rear-firing woofer array for dipole/cardioid bass cancellation
- [ ] **v8: Purifi midrange** — swap 15W for Purifi 5" or 6.5" once crossover frequency is measured
- [ ] **v9: Bliesma tweeter** — Bliesma T25B or similar as alternative to H2606
- [ ] **v10: FIR crossovers** — linear-phase crossover once DSP platform supports it
- [ ] **GitHub Pages site** — render the design bible as a static site from the `docs/` folder

---

## Summary — what's blocking what

```
throat_d verified
    └─► WG212 printed + H2606 test-fit
            └─► distortion measurement at 1250 Hz
                    ├─► crossover frequency confirmed (or adjusted to 1350-1450 Hz)
                    │       └─► DSP platform selected
                    │               └─► build starts
                    └─► c-c confirmed from real parts
                            └─► DESIGN_REQUIREMENTS + DD-011 updated
```

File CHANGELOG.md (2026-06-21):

# Changelog

All notable design changes for Mk2 Reference Loudspeaker are documented here.

## v6b - Current reference candidate

### Added

- WG212 selected as current waveguide direction.
- 1250 Hz LR4 acoustic mid/tweeter crossover selected as current target.
- 140 mm mid/tweeter c-c spacing selected as target.
- 300 mm front baffle retained.
- R50 vertical front roundovers retained.
- Approx. 69 L sealed bass chamber target retained.

### Notes

The latest simplified spinorama/directivity simulations suggest that lowering the mid/tweeter crossover and reducing the c-c spacing are more important than increasing waveguide mouth size.

### Refined and corrected (post-review)

- Push-push woofers specified as **opposed at the same height with a rigid
  coupling block**, replacing the earlier 350 mm / 700 mm vertical stagger (the
  stagger re-introduced a rocking moment; same-height opposed cancels cleanly and
  fits the ~22 mm magnet gap). See Chapter 8.
- DD-010 (1250 Hz) and DD-011 (140 mm c-c) annotated with the review caveats:
  1250 Hz sits below the WG212 control band, and ~150-160 mm is the realistic
  buildable c-c. The nominal targets are retained pending measurement.
- Corrected physics-doc errors flagged in `REVIEW.md`: the sealed-box formula and
  T/S data (Chapter 3), the N-driver Vas relation (Chapter 9), and the LR4 phase
  description (Chapter 11). Design numbers (Qtc ~0.62 / Fc ~34.5 Hz) are unchanged.
- Registered the **SB23 line** as a parallel alternative variant (see `ROADMAP.md`
  and `assets/`). The v6b GRS spec is unchanged.
- Minor data polish (REVIEW §D): midrange sensitivity corrected ~88 → ~89.7 dB
  with the tweeter pad widened to ~5-7 dB (measurement-dependent); deep-GRS driver
  displacement raised ~1.5 → ~5 L for the pair (net bass still ~70 L); added a
  4 Ω-vs-8 Ω impedance-confirmation note (Chapter 3) and a "simulated, not
  CEA-2034" banner to Chapter 13.

### Design-stage work (CAD + simulations)

- WG212 geometry defined as an asymmetric oblate-spheroid waveguide and recorded
  as **DD-012** (throat ~28 mm, ~100°/64° coverage, mouth ~211.7 × 121 mm, control
  ~1620 Hz); Chapter 6 updated to reference `cad/mk2_waveguide_os.scad` and tick
  the completed geometry tasks.
- Added `cad/cabinet.scad` (first cabinet CAD): shell, R50 roundovers, opposed
  push-push cut-outs + coupling block, WG/mid baffle cut-outs at 150 mm c-c,
  sealed mid chamber and braces.
- Added simulations `bass_volume_compare.py` (64–72 L alignment + group delay;
  confirms Qtc ~0.62 / Fc ~34.5 at 69 L and tolerance-robustness) and
  `directivity_estimate.py` (DI step vs crossover — quantifies DD-010 / REVIEW §C2).
- Fixed a sharp waveguide-mouth-to-baffle edge in `cad/mk2_waveguide_os.scad`
  (flange moved behind the flush mouth plane, removing the forward lip that would
  diffract) and added `simulations/waveguide_profile.py` illustrating the issue
  and the flush / blended fixes.
- `cabinet.scad`: added an optional waveguide-in-baffle **assembly** view
  (`show_waveguide`) and explicit `eps` cut overshoots so openings render cleanly
  — coincident faces otherwise smear in OpenSCAD instead of showing a hole. The
  seated mouth pokes `wg_through` mm through the baffle so the solids overlap.
- Corrected the flush-termination boolean in `mk2_waveguide_os.scad`: the earlier
  full-depth straight mouth cut removed the rolled bore wall and left the flange
  disconnected (visible as a gap in an exported STL). The bore subtraction now
  opens the mouth along the rolled profile with only a hair-thin front-face
  pierce, so the wall runs continuously into the flange and the mouth stays flush.
- All CAD/simulation outputs are simulation-stage estimates, not measured or final.

## v6 - Directivity optimization

### Added

- Compared WG212, WG220, WG230 and WG240.
- Compared 1300, 1400, 1500 and 1600 Hz mid/tweeter crossover targets.
- Compared 140, 145, 150 and 157 mm c-c spacing.

### Result

The best candidates were concentrated around low crossover frequency and short c-c spacing.

## v5b - Volume and placement refinement

### Added

- Refined woofer centers to 350 mm and 700 mm from cabinet bottom.
- Refined mid chamber to approx. 5.7 L net.
- Estimated net bass volume around 70 L.
- Estimated sealed alignment around Fc 34-35 Hz and Qtc 0.62.

## v5 - 300 mm / R50 cabinet

### Added

- Selected 300 mm cabinet width.
- Selected R50 vertical front roundovers.
- Retained 370 mm depth and approx. 1080 mm height.

### Result

300/R50 was selected as a better practical compromise than 280/R40 or wider variants.

## v4 - 280 mm cabinet exploration

### Added

- Explored 280 mm wide cabinet.
- Compared R20, R30, R40 and R50 roundovers.

### Result

R40 was promising, but 280 mm width was considered more mechanically constrained.

## v3 - GRS woofer introduced

### Added

- Investigated GRS 8SW-4HE-8 as replacement woofer.
- Simulated sealed box volumes around 55-75 L.

### Result

2 x GRS 8SW-4HE-8 in approx. 64-70 L sealed volume gave a low-Q alignment suitable for DSP.

## v2 - Cabinet concept

### Added

- Active 3-way cabinet concept.
- Push-push side woofers.
- Dedicated sealed mid chamber.
- H2606 waveguide tweeter.

## v1 - Initial concept

### Added

- Initial Mk2 active reference loudspeaker direction.
- SB23-based starting point.

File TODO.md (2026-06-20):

# Mk2 Reference Loudspeaker - TODO

Inspired by Genelec 8361, Dutch & Dutch 8C and Revel Salon2.

---

# Current Main Design (v6b)

- [x] Select GRS 8SW-4HE-8 woofers
- [x] Select ScanSpeak 15W/4434G00 midrange
- [x] Select ScanSpeak H2606/920000 tweeter
- [x] Select sealed push-push bass configuration
- [x] Select 300 mm wide cabinet
- [x] Select R50 front edge roundovers
- [x] Target 69 L net bass volume
- [x] Target 5.7 L mid chamber
- [x] Target 150 Hz LR4 bass-mid crossover
- [x] Target 1250 Hz LR4 mid-tweeter crossover
- [x] Target 140 mm mid/tweeter c-c spacing

---

# Documentation

## Design Bible

- [ ] Create Design Bible master file
- [ ] Chapter 1 - Project goals and philosophy
- [ ] Chapter 2 - Loudspeaker theory
- [ ] Chapter 3 - Woofer investigations
- [ ] Chapter 4 - Midrange investigations
- [ ] Chapter 5 - Tweeter investigations
- [ ] Chapter 6 - Waveguide development
- [ ] Chapter 7 - Cabinet development
- [ ] Chapter 8 - Push-push bass
- [ ] Chapter 9 - Volume calculations
- [ ] Chapter 10 - Bracing
- [ ] Chapter 11 - Crossovers
- [ ] Chapter 12 - Directivity
- [ ] Chapter 13 - Spinorama
- [ ] Chapter 14 - DSP
- [ ] Chapter 15 - Measurements
- [ ] Chapter 16 - Build guide
- [ ] Chapter 17 - Future versions

---

# Simulations

## Bass

- [ ] Compare 65 L
- [ ] Compare 68 L
- [ ] Compare 70 L
- [ ] Compare Qtc
- [ ] Compare group delay

## Midrange

- [ ] Verify diffraction
- [ ] Verify off-axis response
- [ ] Compare crossover frequencies

## Tweeter

- [ ] Compare 1250 Hz
- [ ] Compare 1300 Hz
- [ ] Compare 1400 Hz

## Complete system

- [ ] Simulate spinorama
- [ ] Simulate listening window
- [ ] Simulate early reflections
- [ ] Simulate sound power
- [ ] Simulate predicted in-room response
- [ ] Simulate DI

---

# Waveguide

## WG212

- [ ] Define throat diameter
- [ ] Define profile
- [ ] Define mouth radius
- [ ] Define depth
- [ ] Define flange shape

## CAD

- [ ] Generate OpenSCAD model
- [ ] Export STL
- [ ] Export STEP
- [ ] Generate drawing

## Print

- [ ] Print prototype
- [ ] Test fit H2606
- [ ] Verify c-c spacing

---

# Cabinet

## Geometry

- [ ] Finalize external dimensions
- [ ] Verify internal dimensions
- [ ] Verify driver spacing

## Bracing

- [ ] Design window braces
- [ ] Design shelf braces
- [ ] Add vertical braces

## Mid chamber

- [ ] Finalize volume
- [ ] Finalize damping

## Push-push woofers

- [ ] Verify positions
- [ ] Verify mechanical coupling

---

# CAD

## Cabinet

- [ ] OpenSCAD model
- [ ] STEP model
- [ ] 2D drawings

## Driver cutouts

- [ ] Woofer cutout
- [ ] Midrange cutout
- [ ] Waveguide cutout

---

# DSP

## Initial filters

- [ ] HP 20 Hz LR4
- [ ] LP 150 Hz LR4
- [ ] HP 150 Hz LR4
- [ ] LP 1250 Hz LR4
- [ ] HP 1250 Hz LR4

## Delay

- [ ] Estimate acoustic centers
- [ ] Initial delay values

## EQ

- [ ] Bass shelf
- [ ] Baffle step correction
- [ ] Waveguide correction

## House curves

- [ ] Flat
- [ ] Harman target
- [ ] Mild bass lift

---

# Measurements

## Drivers

- [ ] Measure woofer nearfield
- [ ] Measure midrange
- [ ] Measure tweeter

## Horizontal

- [ ] 0°
- [ ] 10°
- [ ] 20°
- [ ] 30°
- [ ] 40°
- [ ] 50°
- [ ] 60°

## Vertical

- [ ] ±10°
- [ ] ±15°
- [ ] ±20°
- [ ] ±30°

## Merge

- [ ] Import to VituixCAD
- [ ] Optimize crossover

---

# Build

## Prototype

- [ ] Cut panels
- [ ] Assemble cabinet
- [ ] Install damping
- [ ] Install drivers

## Electronics

- [ ] Amplifiers
- [ ] DSP
- [ ] Wiring

## Tuning

- [ ] Measurements
- [ ] EQ
- [ ] Delay
- [ ] Final voicing

---

# Future Versions

## v7

- [ ] Cardioid bass

## v8

- [ ] Purifi midrange

## v9

- [ ] Bliesma tweeter

## v10

- [ ] FIR filters

## v11

- [ ] Fully integrated active electronics

---

# Nice To Have

- [ ] Klippel NFS measurements
- [ ] Complete spinorama
- [ ] Python simulation scripts
- [ ] REW presets
- [ ] VituixCAD files
- [ ] OpenSCAD files
- [ ] STEP files
- [ ] Renderings
- [ ] Build pictures
- [ ] Public website
- [ ] GitHub Pages documentation

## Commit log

2026-06-20 fix: correct tweeter from Seas H2606 to ScanSpeak H2606/920000
    The tweeter is ScanSpeak Discovery H2606/920000 (horn dome, textile,
    6 Ω, Fs 1030 Hz, 95.2 dB sensitivity), not Seas.
    - Replace all 'Seas H2606' references throughout docs and root files
    - Rewrite docs/05_tweeter_selection.md with correct specs and character
    - Update DD-006 with horn-loaded context and Fs/sensitivity notes
    - Note ~7 dB DSP attenuation needed (sensitivity mismatch vs 15W)
    - Fix directivity chapter: H2606/920000 is already horn-loaded, not bare dome
    - Update PARTS.md with correct specs
2026-06-20 docs: add imported drawings, response plot and DSP table as reference assets
    Imports 4 PNG drawings and a DSP filter CSV from an external design session
    into assets/. Documented in assets/README.md, including the discrepancies with
    the current v6b spec (these depict an SB23-based study, not the GRS v6b design).
    v6b spec text is left unchanged.
    Claude-Session: https://claude.ai/code/session_01HRmP6vhTVxCVbdko9d8onv
    [mk2_dsp.csv]
2026-06-21 fix(cad): flush WG212 mouth-to-baffle termination (remove sharp lip)
    The waveguide rolled to a flush tangent at the mouth plane but the mounting
    flange was added forward of it with a straight mouth cut, leaving a sharp 90 deg
    lip at the baffle - a diffraction source (off-axis / spinorama ripple).
    - mk2_waveguide_os.scad: seat the flange behind the flush mouth plane and clear
    the mouth only up to that plane, so the bore meets the baffle flush with no
    forward lip. Countersinks reference the new front face. Depth-neutral.
    - simulations/waveguide_profile.py (+ plot): cross-section showing the current
    lip vs the flush and blended terminations.
    - docs/06, DD-012, cad/README, simulations/REA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
    [mk2_waveguide_os.scad]
2026-06-21 cad: auto-sync waveguide seating depth via wg_front_z()
    The assembly used a hard-coded wg_depth=75. User feedback: ~84.5 mm was needed to
    sit flush - that is D_tot + flange_thick + 0.5, i.e. the OLD flange-forward
    (sharp-edged) waveguide, not the flush-terminated one (front face at D_tot=75).
    - mk2_waveguide_os.scad: expose function wg_front_z() = D_tot (the part's front
    face).
    - cabinet.scad: wg_depth = wg_front_z() so seating tracks the waveguide model and
    cannot drift out of sync; documented the 75 vs ~84.5 tell-tale.
    - cad/README updated.
    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
    [cabinet.scad, mk2_waveguide_os.scad]
2026-06-21 fix(cad): repair WG212 flush-mouth boolean (wall was eaten, flange disconnected)
    Analyzing an exported STL showed the bore wall ending mid-roll with the flange
    floating, disconnected - the rolled mouth was missing entirely.
    Cause: the flush-termination edit kept a full-depth straight mouth cut (radius
    mouth_r over the whole roll region). Where the rolled wall is thinner than
    mouth_r that cut removed the entire wall annulus, severing bore from flange.
    Fix: drop the full-depth straight cut. loft_bore(0) already opens the mouth
    through the rearward flange along the rolled profile; only a 0.6 mm front-face
    pierce remains so the opening is manifold/flush. Verified by reconstructing the
    boolean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
    [mk2_waveguide_os.scad]
2026-06-22 ci(sims): update simulation outputs [skip ci]
    Triggered by: 6b83f8eabf8ef0c663a46ccd20636629852c0843
    Scripts: bass_alignment_maxspl, bass_volume_compare, waveguide_profile,
    directivity_estimate, vertical_lobing,
    crossover_simulation, system_response, polar_response,
    vertical_polar_map, design_versions_comparison
    [crossover_simulation.csv, design_versions.csv, polar_horizontal.csv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]
2026-06-22 docs+sims: fix all documentation, add baffle step simulation
    Documentation fixes:
    - README: update Next Steps to current state, add CI badges
    - docs/00_design_bible.md: all 17 chapter statuses accurate (was all 'Draft')
    - DESIGN_REQUIREMENTS.md: c-c notes 140mm nominal vs ~150-155mm expected
    - PARTS.md: add quantities per pair, indicative pricing, supplier notes, DSP options
    - assets/README.md: add column descriptions for mk2_dsp.csv, mk2_parametre.csv, mk2_stykliste.csv
    - simulations/README.md: all 11 scripts in table, updated pip install command
    - PROJECT_TODO.md: mark 9 completed items
    Simulation:
    - Add simulations/baffle_step.py: Vanderkooy single-pole model, 300mm cabinet,
    f_bs ~324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
    [baffle_step.csv]
2026-06-22 ci(cad): auto-render preview images [skip ci]
    Triggered by: 7a58168967629e14cabebda1df7cbc84bfe9fc48
    Renders: waveguide (mouth/rear/side), cabinet (exterior/cutaway/assembly)
2026-07-25 fix: caliper-verified SB26STAC dimensions — throat 28→32mm, recess 53→43mm
    Physical measurement of received tweeter (Jul 25):
    - throat_d: 28→32mm (dome 26mm + ~3mm surround per side)
    - tw_recess_d: 53.0→43.0mm (outer edge of recess, was misread from PDF)
    - flange thickness confirmed 4.0mm (was ~5mm estimate)
    - mounting depth 33.2mm added (from manufacturer drawing)
    - magnet Ø70.0, basket Ø82.8mm added
    - Added measurement verification sheet (HTML, printable)
    All other dimensions match spec within tolerance:
    faceplate 99.84 (spec 100.0±0.35), BCD 88.5 exact, depth 39.7 exact
    [waveguide.scad]
2026-07-25 ci: update simulations + CAD renders [skip ci]
    Triggered by: 3570876786f42f23b47ed25db3408ea99b8d2045
    [cabinet.stl, cabinet_v2.stl, waveguide.stl]
2026-07-25 ci: auto-release cad-rNN on every deploy
    Adds a post-deploy step that finds the latest cad-rNN tag,
    increments it, creates a GitHub release with CAD files, datasheets,
    DSP configs, drawings and 3D reference files as assets.
2026-07-25 ci: update simulations + CAD renders [skip ci]
    Triggered by: 6fac4776e268058781da6e7b9fd9bee41e94ff53
    [cabinet.stl, cabinet_v2.stl, waveguide.stl]
2026-07-25 feat: DATS impedance measurements for all 3 mk3 drivers (Jul 25)
    Measured in free air with Dayton Audio Test System:
    - GRS 12SW-4HE: Fs=25.1 (spec 22), Qts=0.51 (spec 0.43) — Qms high
    - ScanSpeak 18W/4424G00: Fs=69.4 (spec 49), Qts=0.60 (spec 0.38) — likely needs break-in
    - SB26STAC-C000-4: Fs=658 (spec 750), Qts=1.04 (spec 1.12) — excellent match
    Raw DATS exports + SVG impedance plot + full analysis in docs/15_measurements.md
2026-07-25 ci: update simulations + CAD renders [skip ci]
    Triggered by: 33514c4484c928464477afc7a369960576d8da09
    [cabinet.stl, cabinet_v2.stl, waveguide.stl]
2026-07-25 feat: 18W/4424G00 break-in update (5h) — Fs 69.4→64.5 Hz, Qts 0.598→0.576
    Suspension loosening confirmed: Fs -7%, Qts -3.7%, Qms -2.0% after 5h.
    All trending toward spec but not there yet. Continue break-in to 15-20h.
2026-07-25 ci: update simulations + CAD renders [skip ci]
    Triggered by: 271b08b6cd854f5c57c5d08b6cc3e69ddb2f8db9
    [cabinet.stl, cabinet_v2.stl, waveguide.stl]
2026-07-26 docs: add pre-ferie mk3 prototype status report (uge 31)
2026-07-26 feat: 12SW-4HE break-in update (5h) — Qts 0.512→0.442 (+2.7% from spec)
    Excellent break-in response: Fs 25.1→23.5 Hz, Qts 0.51→0.44, Qes 0.59→0.52.
    All key params now within 7% of datasheet after just 5h. Driver at spec.
    12SW responds much faster to break-in than 18W (Qts -13.7% vs -3.7%).
2026-07-26 ci: update simulations + CAD renders [skip ci]
    Triggered by: 5f77272a2ff1bdcde57a344057e46dc676d4cc7b
    [cabinet.stl, cabinet_v2.stl, waveguide.stl]
2026-07-26 feat: 12SW 10h break-in (stabilized) + SB26STAC waveguide loading measurement
    12SW: Fs 23.25, Qts 0.46 — break-in complete, within 7% of spec.
    Re 4.40 Ω elevated (+19%), likely coil warming — cold recheck needed.
    SB26STAC in waveguide mockup: Fs 658→632 Hz (-4%), Qts 1.04→1.08 (+3.8%).
    Mild acoustic loading as expected. Crossover margin 468 Hz. No adjustment needed.
2026-07-26 ci: update simulations + CAD renders [skip ci]
    Triggered by: da600c03e77e8f69197da1dae9ed6a3f59e00652
    [cabinet.stl, cabinet_v2.stl, waveguide.stl]
2026-07-26 docs: full documentation review — update all stale references
    Cabinet: 320mm→300mm, 380mm→420mm depth, 75L→65L bass volume
    Waveguide: throat 28→32mm, recess 53→43mm (caliper-verified Jul 25)
    DATS measurements integrated into BENCH_CHEAT_SHEET, BUILD_LOG,
    PROTOTYPE_CHECKLIST, PARTS, BOM_v9, ferie_status, analysis docs.
    Design history chapters (3/5/6/7/17) annotated with update notes.
    Added CI-generated simulation scripts + plots (break-in projection,
    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
2026-07-26 ci: update simulations + CAD renders [skip ci]
    Triggered by: a2a20313fd4501723756e327b7c63f1a8b6ea581
    [cabinet.stl, cabinet_v2.stl, waveguide.stl]
2026-07-26 Add 12mm internal parts cut plan (divider, braces, mid chamber)
    12 dele per par på 1 plade 1220×2440mm (27.7% udnyttelse):
    - 2× skilleplade 398×256mm (19° vinkel)
    - 6× ring-afstivning 254×374mm (R19, indre cutout 164×284)
    - 4× mellemtonekammer 256×51mm
    - 2× coupling block Ø110×36mm (fra scrap, lamineres 3×12mm)
2026-07-31 sim: update all sealed-box parameters to DATS break-in design values (Jul 26)
    DATS break-in (10h) settled values for GRS 12SW-4HE:
    Fs=23.25 Hz, Qts=0.46 (vs datasheet Fs=22, Qts=0.43)
    Impact on 75 L sealed:
    Fc 28.0→41.2 Hz, Qtc 0.707→0.82
    All 4 simulation scripts updated:
    - bass_alignment_maxspl.py — GRS12 dict
    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
    [crossover_woofer_mid.csv, system_response_anechoic.csv, system_response_inroom.csv]
2026-07-31 ci: update simulations + CAD renders [skip ci]
    Triggered by: f53b10b36e9a54347cf4380c0b8557f6529cad29
    [cabinet.stl, cabinet_v2.stl, waveguide.stl]
2026-07-31 sim: add extended alignment analysis for DATS break-in values (Jul 31)
    After 10h break-in, GRS 12SW settled at Fs=23.25/Qts=0.46.
    75L sealed gives Qtc=0.816, Fc=41.2 Hz — between Butterworth (118L)
    and Chebyshev 0.5dB (67L). Only 3.6 dB LT boost needed at 28 Hz.
    Cabinet is well-optimized for break-in values.
2026-07-31 ci: update simulations + CAD renders [skip ci]
    Triggered by: b0d2bf6c9473ae8b2ce3065ac3e43767e2f22fa4
    [cabinet.stl, cabinet_v2.stl, waveguide.stl]
